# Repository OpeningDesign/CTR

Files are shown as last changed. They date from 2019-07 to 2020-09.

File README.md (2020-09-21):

<div align="right" >
<p align="right" >

</p>
</div>

## OpeningDesign
An (uberly) transparent & open source architectural studio.

---
#### In-the-Open

All of [OpeningDesign's](http://openingdesign.com/) projects are conducted out in the open.  That is, during the development of any one project, all team communication and content is hosted [publicly](https://github.com/OpeningDesign) (here on GitHub) and is <a href="#license">open source</a>.

Our [about page](http://openingdesign.com/about/) provides a more nuanced description of this open approach.

---
#### License
Per usual, unless otherwise noted, all content associated with [OpeningDesign](http://openingdesign.com) projects is licensed under an open source, 'copyleft' license: 
[Attribution-ShareAlike 4.0 International (CC BY-SA 4.0)](https://creativecommons.org/licenses/by-sa/4.0/).  Attribution to be given to the entire team associated with the project.


---

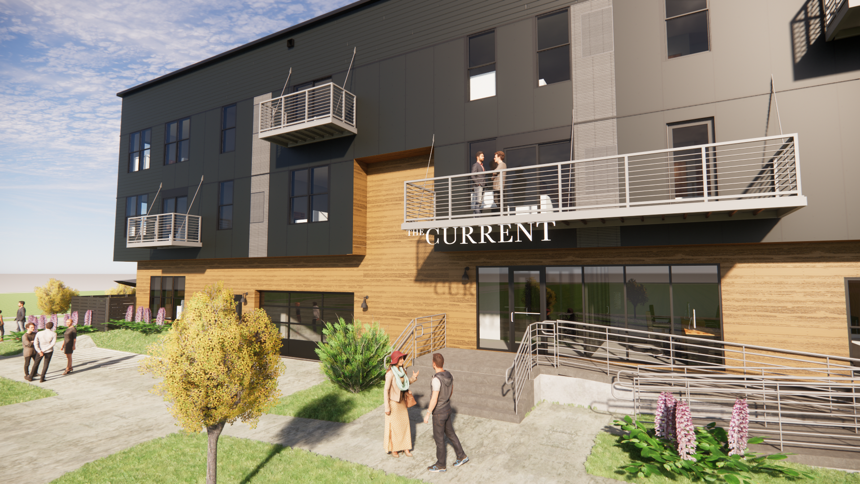
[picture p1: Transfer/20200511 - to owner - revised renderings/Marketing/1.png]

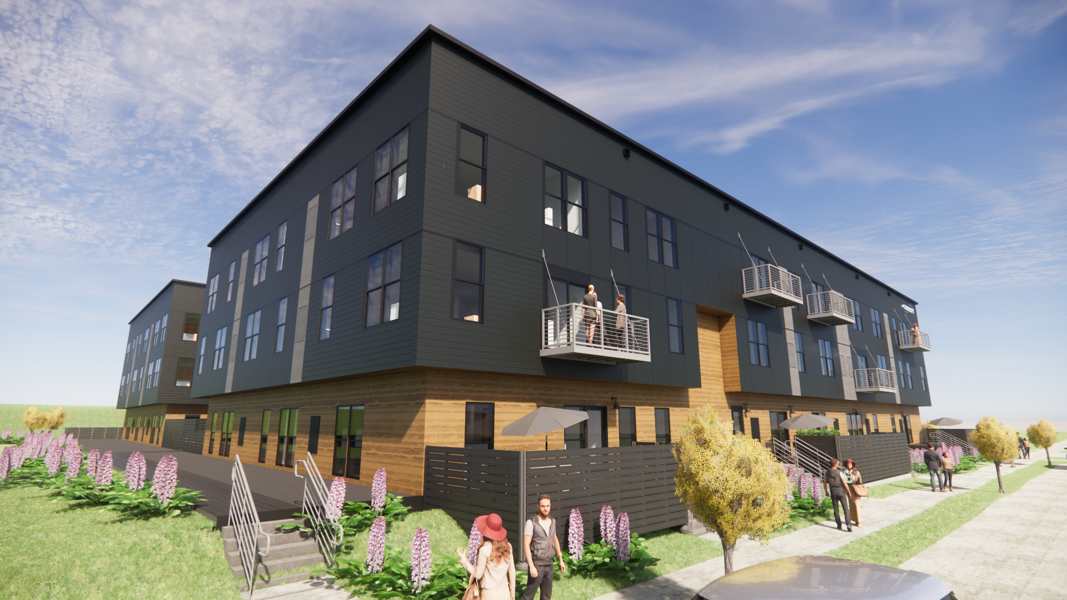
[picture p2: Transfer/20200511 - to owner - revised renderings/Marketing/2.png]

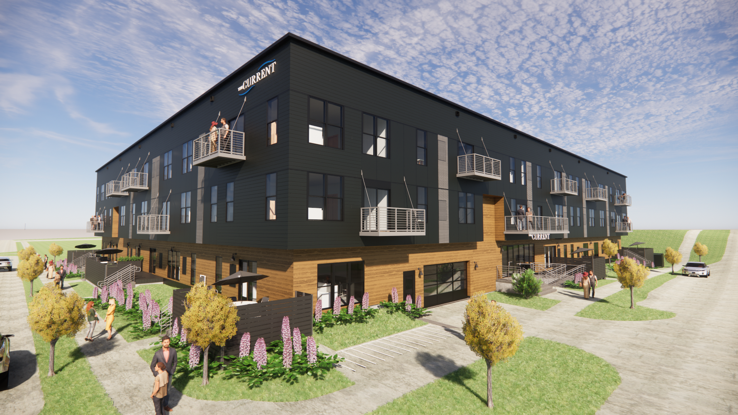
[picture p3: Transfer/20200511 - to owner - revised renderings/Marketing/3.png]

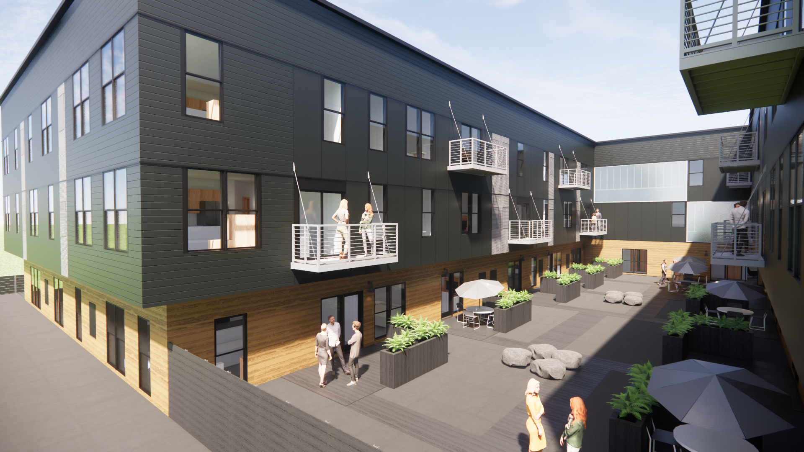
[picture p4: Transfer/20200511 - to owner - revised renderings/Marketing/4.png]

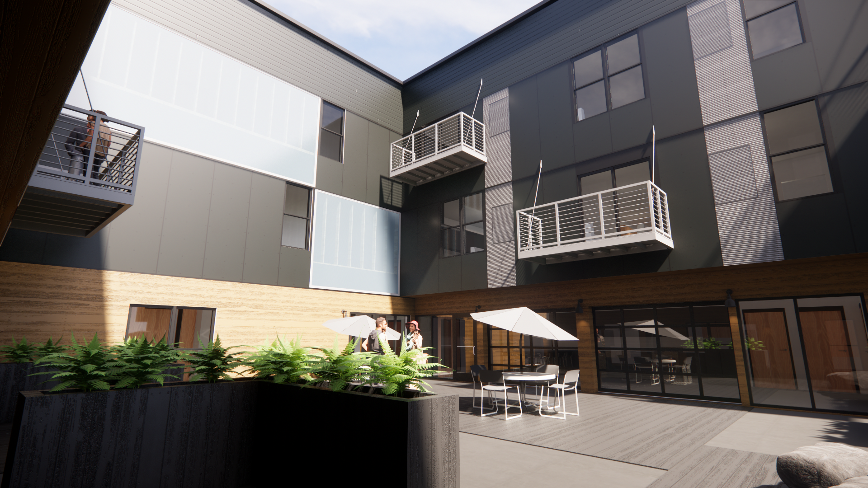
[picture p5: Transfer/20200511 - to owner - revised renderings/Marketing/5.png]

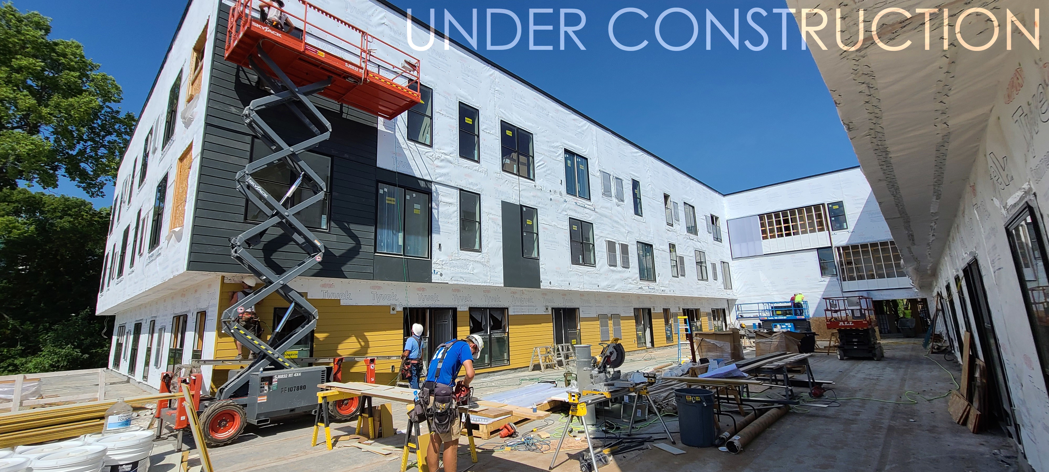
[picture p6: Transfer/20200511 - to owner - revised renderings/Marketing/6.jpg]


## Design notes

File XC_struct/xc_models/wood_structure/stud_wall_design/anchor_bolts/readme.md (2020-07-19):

Anchor bolts for anchoring wood framing walls to concrete.

See [issue](https://github.com/OpeningDesign/CTR/issues/90)

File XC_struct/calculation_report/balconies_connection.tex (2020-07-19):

\subsection{Loads on the connection}
The ties of the balconies are attached to the wood structure by means of the
connection represented in figure \ref{fg_balconies_connection}.

According to our calculations the maximum load to be resisted by this connection is:

\begin{equation}
  F= 4.83\ kN
\end{equation}

\noindent the angle with respect to the vertical of this force is 23.42 degrees.

\subsection{Loads on fasteners}
To calculate the loads on the connection fasteners we have used a the finite element model shown in figure \ref{fg_balconies_connection_mesh}.

\subsection{Fastener strength}
The strength of the 3/8 lag screws are as follows:

\begin{itemize}
\item Screw design withdrawal: $W_d= 4.6\ kN$.
\item Screw design lateral strength: $Z_d= 0.89\ kN$.
\end{itemize}

\subsection{Checking of fastener capacities}
The capacities of the fasteners are as follows:

\begin{center}
  \begin{tabular}{|c|c|c|c|}
    \hline
    \textbf{Screw} & $\mathbf{Z}$ & $\mathbf{R}$ & CF    \\
    \textbf{ID} & \textbf{(kN)}& \textbf{(kN)} & - \\
      \hline
466 & 0.13 & 0.98 & 0.14\\
638 & 0.96 & 1.03 & 0.93\\
129 & 0.15 & 1.19 & 0.12\\
59 & 0.76 & 1.38 & 0.55\\
94 & 0.12 & 4.25 & 0.03\\
50 & 0.64 & 2.66 & 0.24\\
26 & 0.13 & 1.40 & 0.10\\
393 & 0.70 & 1.21 & 0.58\\
218 & 0.13 & 0.98 & 0.14\\
242 & 0.96 & 1.03 & 0.93\\
543 & 0.15 & 1.19 & 0.12\\
522 & 0.76 & 1.38 & 0.55\\
539 & 0.12 & 4.25 & 0.03\\
490 & 0.64 & 2.66 & 0.24\\
322 & 0.13 & 1.40 & 0.10\\
297 & 0.70 & 1.21 & 0.58\\
\hline
  \end{tabular}
  \end{center}

\noindent where
\begin{description}
\item{Screw ID.} Screw identifier.
\item{$Z$:} Screw strength.
\item{$R$:} Design load on screw.
\item{$CF= Z/R$:} Capacity factor
  \end{description}

We can see that the maximum capacity factor is $0.93<1$ so the fasteners are strong enough.

\begin{figure}
  \begin{center}
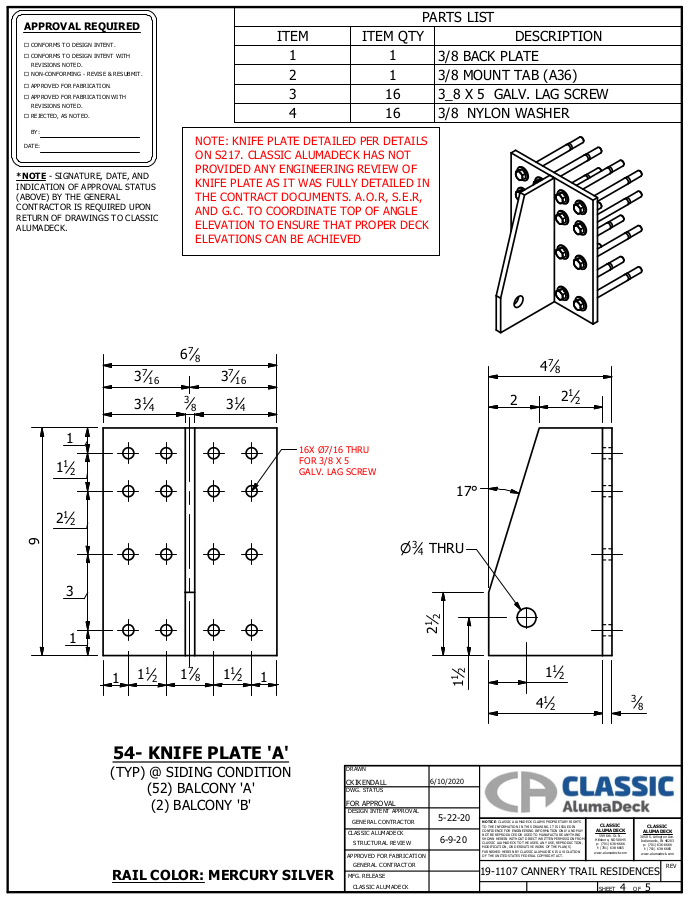
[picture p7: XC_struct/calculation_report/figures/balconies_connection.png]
    
  \end{center}
  \caption{Balconies connection.} \label{fg_balconies_connection}
\end{figure}

\begin{figure}
  \begin{center}
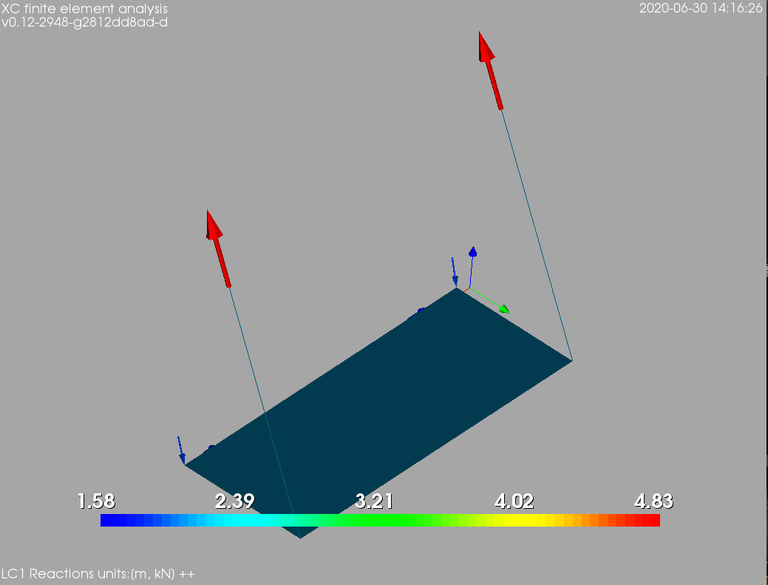
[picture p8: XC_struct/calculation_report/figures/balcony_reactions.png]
    
  \end{center}
  \caption{Balconies. Maximum load on connections.}
\end{figure}

\begin{figure}
  \begin{center}
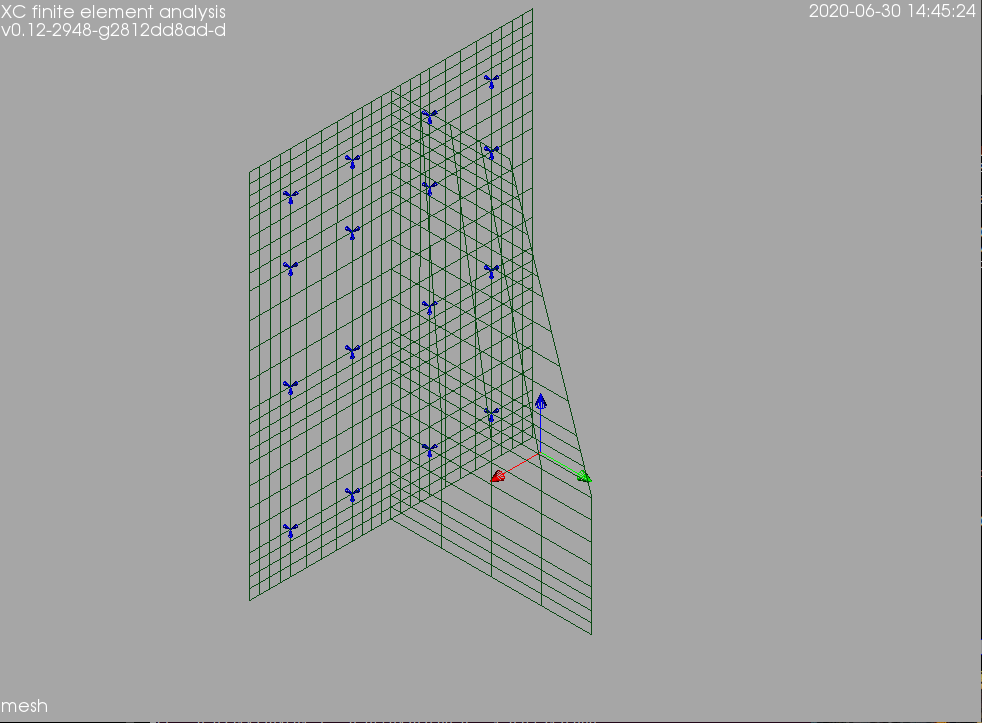
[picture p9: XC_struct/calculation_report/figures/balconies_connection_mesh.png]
    
  \end{center}
  \caption{Balconies connection. Finite element model.}\label{fg_balconies_connection_mesh}
\end{figure}

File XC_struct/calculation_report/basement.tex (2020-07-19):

\input{model.tex}
\subsection{Footings}
\input{footings.tex}
\subsection{Basement walls}
\input{basement_walls.tex}
%\subsection{Ramp}
%\input{ramp.tex}
\subsection{Ramp walls and steel structure bearing hollowcore 2nd floor}
\input{ramp_wall/data.tex}
\subsubsection{Material and RC-sections properties}
\input{ramp_wall/results.tex}

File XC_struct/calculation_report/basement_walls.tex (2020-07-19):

\subsubsection{Introduction}

The design is based in the following assumptions:

\begin{itemize}
\item Design wall with pinned base and pinned top.
\item Neglect corner regions (wall spans one-way only).
\item Top slab is in place and has achieved full strength prior to back-filling.
\item Vehicular traffic around the building is represented by a uniform load of $250\ psf$ ($11.97\ kN/m^2$).
\item The vertical response of the soil calculated using a Winkler model with a sub-grade reaction module of set of 200 pounds per cubic inch ($54.29 \times 10^6\ N/m^3$).
\item Water table deep below structure.
\end{itemize}

\subsubsection{Load determination}

\subparagraph{Self weight.}
The self weight of the reinforced concrete is calculated from its density: $2500\ kg/m^3$.

\subparagraph{Axial loads from building.}
The loads transferred by the top slab to the wall are as follows:

\begin{center}
  \begin{tabular}{|l|l|r|r|}
\hline
\textbf{Building} & \textbf{Load} & \textbf{Phase 1} & \textbf{Phase 2}\\
\textbf{side} &  & (kN/m) & (kN/m)\\
\hline
North & SnowL & 10.06 & 10.06\\
North & LiveL & 21.67 & 21.67\\
North & Wind\_NS & -15.12 & -15.12\\
North & Wind\_WE & -1.33 & -1.33\\
North & DeadL & 31.54 & 31.54\\
\hline
South & SnowL & 8.04 & 16.08\\
South & LiveL & 14.22 & 28.44\\
South & Wind\_NS & 4.97 & 9.95\\
South & Wind\_WE & -0.23 & -0.46\\
South & DeadL & 20.58 & 41.15\\
\hline
East & SnowL & 11.96 & 11.96\\
East & LiveL & 23.75 & 23.75\\
East & Wind\_NS & -0.07 & -0.07\\
East & Wind\_WE & 12.97 & 12.97\\
East & DeadL & 30.87 & 30.87\\
\hline
West & SnowL & 15.02 & 15.02\\
West & LiveL & 27.15 & 27.15\\
West & Wind\_NS & -0.20 & -0.20\\
West & Wind\_WE & -13.20 & -13.20\\
West & DeadL & 29.81 & 29.81\\
\hline
\end{tabular}
\end{center}

\subsubsection{Load combinations} \label{sc_load_combinations}

\begin{center}
  \begin{footnotesize}
  \begin{tabular}{|l|c|l|}
\hline
\multicolumn{3}{|c|}{\textbf{Serviceability limit states}}\\
\hline
Equation 16-8 & EQ1608 & 1.0*selfWeight+1.0*deadLoad\\
Equation 16-9 & EQ1609A & 1.0*selfWeight+1.0*deadLoad+1.0*trafficLoad\\
Equation 16-9 & EQ1609B & 1.0*selfWeight+1.0*deadLoad+1.0*liveLoad\\
Equation 16-10 & EQ1610 & 1.0*selfWeight+1.0*deadLoad+1.0*snowLoad\\
Equation 16-11 & EQ1611A & 1.0*selfWeight+1.0*deadLoad+0.75*trafficLoad+0.75*snowLoad\\
Equation 16-11 & EQ1611B & 1.0*selfWeight+1.0*deadLoad+0.75*liveLoad+0.75*snowLoad\\
Equation 16-12 & EQ1612 & 1.0*selfWeight+1.0*deadLoad+0.6*windLoad\\
Equation 16-13 & EQ1613A & 1.0*selfWeight+1.0*deadLoad+0.45*windLoad+0.75*trafficLoad+0.75*snowLoad\\
Equation 16-13 & EQ1613B & 1.0*selfWeight+1.0*deadLoad+0.45*windLoad+0.75*liveLoad+0.75*snowLoad\\
Equation 16-14 & \multicolumn{2}{l|}{doesn't apply}\\
Equation 16-15 & EQ1615 & 0.6*selfWeight+0.6*deadLoad+0.6*windLoad\\
Equation 16-16 & \multicolumn{2}{l|}{doesn't apply}\\
\hline
  \end{tabular}
  \end{footnotesize}
  \end{center}

\begin{center}
  \begin{footnotesize}
  \begin{tabular}{|l|c|l|}
\hline
\multicolumn{3}{|c|}{\textbf{Ultimate limit states.}}\\
\hline
Equation 16-1 & EQ1601 & 1.4*selfWeight+1.4*deadLoad\\
Equation 16-2 & EQ1602A & 1.2*selfWeight+1.2*deadLoad+1.6*trafficLoad+0.5*snowLoad\\
Equation 16-2 & EQ1602B & 1.2*selfWeight+1.2*deadLoad+1.6*liveLoad+0.5*snowLoad\\
Equation 16-3 & EQ1603A & 1.2*selfWeight+1.2*deadLoad+1.6*snowLoad+0.5*trafficLoad\\
Equation 16-3 & EQ1603B & 1.2*selfWeight+1.2*deadLoad+1.6*snowLoad+0.5*liveLoad\\
Equation 16-3 & EQ1603C & 1.2*selfWeight+1.2*deadLoad+1.6*snowLoad+0.5*windLoad\\
Equation 16-4 & EQ1604A & 1.2*selfWeight+1.2*deadLoad+1.0*windLoad+0.5*trafficLoad+0.5*snowLoad\\
Equation 16-4 & EQ1604B & 1.2*selfWeight+1.2*deadLoad+1.0*windLoad+0.5*liveLoad+0.5*snowLoad\\
Equation 16-5 & EQ1605A & 1.2*selfWeight+1.2*deadLoad+0.5*trafficLoad+0.7*snowLoad\\
Equation 16-5 & EQ1605B & 1.2*selfWeight+1.2*deadLoad+0.5*liveLoad+0.7*snowLoad\\
Equation 16-6 & \multicolumn{2}{l|}{doesn't apply}\\
Equation 16-7 & \multicolumn{2}{l|}{doesn't apply}\\
\hline
  \end{tabular}
  \end{footnotesize}
  \end{center}

\subparagraph{Earth pressure.}
The soil pressure over the wall has been calculated using the lateral pressure at rest with a coefficient $K_0= 0.5$.

\subsubsection{Stem dimensions and reinforcement}
The thickness and the reinforcement for the walls are indicated in the table \ref{tb_concrete_wall_reinforcing_schedule}.

\begin{table}
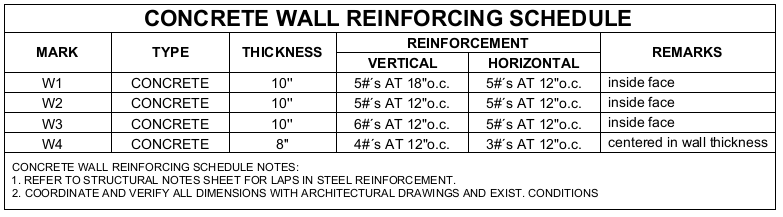
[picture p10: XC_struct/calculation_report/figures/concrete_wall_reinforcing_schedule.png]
    
    \caption{Concrete walls reinforcing schedule}\label{tb_concrete_wall_reinforcing_schedule}
\end{table}

\subparagraph{Wall types.}
For analysis purposes we have considered the following wall types:

\begin{center}
  \begin{tabular}{|l|c|}
    \hline
    \textbf{Wall} & \textbf{Stem} \\
    & \textbf{height (m)} \\
    \hline
T1 & 3.15\\
T2 & 2.74\\
T3 & 3.53\\
T4 & 3.12\\
T5 & 2.51\\
T6 & 3.43\\
    \hline
  \end{tabular}
\end{center}

\subparagraph{Internal forces.}
The envelope of internal forces envelope for each of the walls are given in tables \ref{tb_def_T1} to \ref{tb_def_T6}.

\begin{table}
\begin{center}
\begin{tabular}{|l|}
\hline
\multicolumn{1}{|c|}{\textsc{T1}}\\
\hline
\begin{tabular}{c|l}
\begin{minipage}{85mm}
\vspace{2mm}
\begin{center}

\end{center}
\vspace{1pt}
\end{minipage} & 
\begin{tabular}{l}
\textsc{Wall geometry}\\
Stem top thickness: \\
$b_{top}= 0.25\ m$\\
Stem height: \\
$h_{stem}= 3.15\ m$\\
Stem bottom thickness: \\
$b_{bottom}= 0.25\ m$\\
Footing thickness: \\
$b_{footing}= 0.36\ m$\\
\end{tabular} \\
\end{tabular} \\
\hline
\begin{tabular}{llll}
\multicolumn{3}{c}{\textsc{Materials}}\\
  Concrete: C4000 &   Steel: A615G60 &   Concrete cover: 55 mm\\
\end{tabular} \\
\hline
\end{tabular}
\caption{Wall materials and dimensions T1} \label{tb_def_T1}
\end{center}
\end{table}

\begin{table}
\begin{center}
\begin{tabular}{|l|}
\hline
\multicolumn{1}{|c|}{\textsc{T2}}\\
\hline
\begin{tabular}{c|l}
\begin{minipage}{85mm}
\vspace{2mm}
\begin{center}

\end{center}
\vspace{1pt}
\end{minipage} & 
\begin{tabular}{l}
\textsc{Wall geometry}\\
Stem top thickness: \\
$b_{top}= 0.25\ m$\\
Stem height: \\
$h_{stem}= 2.74\ m$\\
Stem bottom thickness: \\
$b_{bottom}= 0.25\ m$\\
Footing thickness: \\
$b_{footing}= 0.36\ m$\\
\end{tabular} \\
\end{tabular} \\
\hline
\begin{tabular}{llll}
\multicolumn{3}{c}{\textsc{Materials}}\\
  Concrete: C4000 &   Steel: A615G60 &   Concrete cover: 55 mm\\
\end{tabular} \\
\hline
\end{tabular}
\caption{Wall materials and dimensions T2} \label{tb_def_T2}
\end{center}
\end{table}

\begin{table}
\begin{center}
\begin{tabular}{|l|}
\hline
\multicolumn{1}{|c|}{\textsc{T3}}\\
\hline
\begin{tabular}{c|l}
\begin{minipage}{85mm}
\vspace{2mm}
\begin{center}

\end{center}
\vspace{1pt}
\end{minipage} & 
\begin{tabular}{l}
\textsc{Wall geometry}\\
Stem top thickness: \\
$b_{top}= 0.25\ m$\\
Stem height: \\
$h_{stem}= 3.53\ m$\\
Stem bottom thickness: \\
$b_{bottom}= 0.25\ m$\\
Footing thickness: \\
$b_{footing}= 0.36\ m$\\
\end{tabular} \\
\end{tabular} \\
\hline
\begin{tabular}{llll}
\multicolumn{3}{c}{\textsc{Materials}}\\
  Concrete: C4000 &   Steel: A615G60 &   Concrete cover: 55 mm\\
\end{tabular} \\
\hline
\end{tabular}
\caption{Wall materials and dimensions T3} \label{tb_def_T3}
\end{center}
\end{table}

\begin{table}
\begin{center}
\begin{tabular}{|l|}
\hline
\multicolumn{1}{|c|}{\textsc{T4}}\\
\hline
\begin{tabular}{c|l}
\begin{minipage}{85mm}
\vspace{2mm}
\begin{center}

\end{center}
\vspace{1pt}
\end{minipage} & 
\begin{tabular}{l}
\textsc{Wall geometry}\\
Stem top thickness: \\
$b_{top}= 0.25\ m$\\
Stem height: \\
$h_{stem}= 3.12\ m$\\
Stem bottom thickness: \\
$b_{bottom}= 0.25\ m$\\
Footing thickness: \\
$b_{footing}= 0.36\ m$\\
\end{tabular} \\
\end{tabular} \\
\hline
\begin{tabular}{llll}
\multicolumn{3}{c}{\textsc{Materials}}\\
  Concrete: C4000 &   Steel: A615G60 &   Concrete cover: 55 mm\\
\end{tabular} \\
\hline
\end{tabular}
\caption{Wall materials and dimensions T4} \label{tb_def_T4}
\end{center}
\end{table}

\begin{table}
\begin{center}
\begin{tabular}{|l|}
\hline
\multicolumn{1}{|c|}{\textsc{T5}}\\
\hline
\begin{tabular}{c|l}
\begin{minipage}{85mm}
\vspace{2mm}
\begin{center}

\end{center}
\vspace{1pt}
\end{minipage} & 
\begin{tabular}{l}
\textsc{Wall geometry}\\
Stem top thickness: \\
$b_{top}= 0.25\ m$\\
Stem height: \\
$h_{stem}= 2.51\ m$\\
Stem bottom thickness: \\
$b_{bottom}= 0.25\ m$\\
Footing thickness: \\
$b_{footing}= 0.36\ m$\\
\end{tabular} \\
\end{tabular} \\
\hline
\begin{tabular}{llll}
\multicolumn{3}{c}{\textsc{Materials}}\\
  Concrete: C4000 &   Steel: A615G60 &   Concrete cover: 55 mm\\
\end{tabular} \\
\hline
\end{tabular}
\caption{Wall materials and dimensions T5} \label{tb_def_T5}
\end{center}
\end{table}

\begin{table}
\begin{center}
\begin{tabular}{|l|}
\hline
\multicolumn{1}{|c|}{\textsc{T6}}\\
\hline
\begin{tabular}{c|l}
\begin{minipage}{85mm}
\vspace{2mm}
\begin{center}

\end{center}
\vspace{1pt}
\end{minipage} & 
\begin{tabular}{l}
\textsc{Wall geometry}\\
Stem top thickness: \\
$b_{top}= 0.25\ m$\\
Stem height: \\
$h_{stem}= 3.43\ m$\\
Stem bottom thickness: \\
$b_{bottom}= 0.25\ m$\\
Footing thickness: \\
$b_{footing}= 0.36\ m$\\
\end{tabular} \\
\end{tabular} \\
\hline
\begin{tabular}{llll}
\multicolumn{3}{c}{\textsc{Materials}}\\
  Concrete: C4000 &   Steel: A615G60 &   Concrete cover: 55 mm\\
\end{tabular} \\
\hline
\end{tabular}
\caption{Wall materials and dimensions T6} \label{tb_def_T6}
\end{center}
\end{table}

\subparagraph{Reinforcement checks.}

\tablefirsthead{\hline
\multicolumn{1}{|c|}{\textsc{Wall vertical reinforcements}}\\\hline
}
\tablehead{\hline
\multicolumn{1}{|c|}{\textsc{wall vertical reinforcements (cont.)}}\\\hline
}
\tabletail{\hline \multicolumn{1}{|r|}{../..}\\\hline}
\tablelasttail{\hline}
\begin{center}
\begin{supertabular}{|l|}
\hline
\textbf{T1 wall. Inside stem reinforcement:}\\
  RC section dimensions; b= 1.00 m, h= 0.25 m\\
  diam: 16 mm, spacing: 300 mm  reinf. development L=0.34 m (22 diameters).\\
  area: As=   6.67 cm2/m areaMin:   4.56 cm2/m  F(As)= 1.46 OK!\\
  Bending check: Md=  40.09 kN m, MR=  41.36kN m  F(M)= 1.03 OK!\\
  Shear check: Vd=   7.61 kN,  VR= 199.37 kN  F(V)= 26.21 OK!\\
  %% Stress check: M=  40.09 kN m, $\sigma_s$= 263.03 MPa\\
  %%   $\sigma_{lim}$= 300.00 MPa  F($\sigma_s$)= 1.14 OK!\\
\hline
\textbf{T2 wall. Inside stem reinforcement:}\\
  RC section dimensions; b= 1.00 m, h= 0.25 m\\
  diam: 16 mm, spacing: 400 mm  reinf. development L=0.34 m (22 diameters).\\
  area: As=   5.00 cm2/m areaMin:   4.56 cm2/m  F(As)= 1.10 OK!\\
  Bending check: Md=  29.02 kN m, MR=  31.02kN m  F(M)= 1.07 OK!\\
  Shear check: Vd=   6.84 kN,  VR= 199.37 kN  F(V)= 29.15 OK!\\
  %% Stress check: M=  29.02 kN m, $\sigma_s$= 253.88 MPa\\
  %%   $\sigma_{lim}$= 300.00 MPa  F($\sigma_s$)= 1.18 OK!\\
\hline
\textbf{T3 wall. Inside stem reinforcement:}\\
  RC section dimensions; b= 1.00 m, h= 0.25 m\\
  diam: 19 mm, spacing: 300 mm  reinf. development L=0.61 m (32 diameters).\\
  area: As=   9.47 cm2/m areaMin:   4.56 cm2/m  F(As)= 2.08 OK!\\
  Bending check: Md=  51.88 kN m, MR=  58.26kN m  F(M)= 1.12 OK!\\
  Shear check: Vd=   7.98 kN,  VR= 199.37 kN  F(V)= 24.98 OK!\\
  %% Stress check: M=  51.88 kN m, $\sigma_s$= 239.75 MPa\\
  %%   $\sigma_{lim}$= 300.00 MPa  F($\sigma_s$)= 1.25 $\sim$ OK!\\
\hline
\textbf{T4 wall. Inside stem reinforcement:}\\
  RC section dimensions; b= 1.00 m, h= 0.25 m\\
  diam: 16 mm, spacing: 300 mm  reinf. development L=0.34 m (22 diameters).\\
  area: As=   6.67 cm2/m areaMin:   4.56 cm2/m  F(As)= 1.46 OK!\\
  Bending check: Md=  39.19 kN m, MR=  41.36kN m  F(M)= 1.06 OK!\\
  Shear check: Vd=   7.46 kN,  VR= 199.37 kN  F(V)= 26.73 OK!\\
  %% Stress check: M=  39.19 kN m, $\sigma_s$= 257.14 MPa\\
  %%   $\sigma_{lim}$= 300.00 MPa  F($\sigma_s$)= 1.17 OK!\\
\hline
\textbf{T5 wall. Inside stem reinforcement:}\\
  RC section dimensions; b= 1.00 m, h= 0.25 m\\
  diam: 16 mm, spacing: 400 mm  reinf. development L=0.34 m (22 diameters).\\
  area: As=   5.00 cm2/m areaMin:   4.56 cm2/m  F(As)= 1.10 OK!\\
  Bending check: Md=  23.62 kN m, MR=  31.02kN m  F(M)= 1.31 OK!\\
  Shear check: Vd=   6.42 kN,  VR= 199.37 kN  F(V)= 31.05 OK!\\
  %% Stress check: M=  23.62 kN m, $\sigma_s$= 206.69 MPa\\
  %%   $\sigma_{lim}$= 300.00 MPa  F($\sigma_s$)= 1.45 OK!\\
\hline
\textbf{T6 wall. Inside stem reinforcement:}\\
  RC section dimensions; b= 1.00 m, h= 0.25 m\\
  diam: 19 mm, spacing: 300 mm  reinf. development L=0.61 m (32 diameters).\\
  area: As=   9.47 cm2/m areaMin:   4.56 cm2/m  F(As)= 2.08 OK!\\
  Bending check: Md=  49.02 kN m, MR=  58.26kN m  F(M)= 1.19 OK!\\
  Shear check: Vd=   8.13 kN,  VR= 199.37 kN  F(V)= 24.54 OK!\\
  %% Stress check: M=  49.02 kN m, $\sigma_s$= 226.52 MPa\\
  %%   $\sigma_{lim}$= 300.00 MPa  F($\sigma_s$)= 1.32 OK!\\
\end{supertabular}
\end{center}

\tablefirsthead{\hline
\multicolumn{1}{|c|}{\textsc{Shear check}}\\\hline
}
\tablehead{\hline
\multicolumn{1}{|c|}{\textsc{shear check (cont.)}}\\\hline
}
\tabletail{\hline \multicolumn{1}{|r|}{../..}\\\hline}
\tablelasttail{\hline}
\begin{center}
\begin{supertabular}{|l|}
\textbf{T1 wall. Shear check:}\\
  Shear check: Vd=  42.99 kN,  VR= 199.37 kN  F(V)= 4.64 OK!\\
\hline
\textbf{T2 wall. Shear check:}\\
  Shear check: Vd=  31.78 kN,  VR= 199.37 kN  F(V)= 6.27 OK!\\
\hline
\textbf{T3 wall. Shear check:}\\
  Shear check: Vd=  55.00 kN,  VR= 199.37 kN  F(V)= 3.63 OK!\\
\hline
\textbf{T4 wall. Shear check:}\\
  Shear check: Vd=  42.35 kN,  VR= 199.37 kN  F(V)= 4.71 OK!\\
\hline
\textbf{T5 wall. Shear check:}\\
  Shear check: Vd=  26.03 kN,  VR= 199.37 kN  F(V)= 7.66 OK!\\
\hline
\textbf{T6 wall. Shear check:}\\
  Shear check: Vd=  51.43 kN,  VR= 199.37 kN  F(V)= 3.88 OK!\\
\end{supertabular}
\end{center}

\paragraph{Wall foundations}
The results obtained for the verifications of the footing stability and the soil-bearing capacity. According to the geotechnical report the allowable soil bearing pressure is 3000 psf ($143.64\ kN/m^2$).
\begin{center}
\begin{tabular}{|l|c|c|c|}
\hline
\multicolumn{4}{|c|}{\textsc{wall foundation: T1}}\\
\hline
Verification:  & $F_{disp}$ & $F_{req}$ & Combination\\
\hline
Overturning:  & $\gg 1$ & 1.00 & EQ1609A\\
Sliding:  & 1.23 & 1.00 & EQ1609A\\
Adm. pressure:  & 1.09 & 1.00 & EQ1613B\\
\hline
\multicolumn{4}{|c|}{\textsc{wall foundation: T2}}\\
\hline
Verification:  & $F_{disp}$ & $F_{req}$ & Combination\\
\hline
Overturning:  & $\gg 1$ & 1.00 & EQ1613B\\
Sliding:  & 1.46 & 1.00 & EQ1609A\\
Adm. pressure:  & 1.13 & 1.00 & EQ1613B\\
\hline
\multicolumn{4}{|c|}{\textsc{wall foundattion: T3}}\\
\hline
Verification:  & $F_{disp}$ & $F_{req}$ & Combination\\
\hline
Overturning:  & $\gg 1$ & 1.00 & EQ1609A\\
Sliding:  & 1.13 & 1.00 & EQ1609A\\
Adm. pressure:  & 1.12 & 1.00 & EQ1613B\\
\hline
\multicolumn{4}{|c|}{\textsc{wall foundation: T4}}\\
\hline
Verification:  & $F_{disp}$ & $F_{req}$ & Combination\\
\hline
Overturning:  & $\gg 1$ & 1.00 & EQ1613B\\
Sliding:  & 1.45 & 1.00 & EQ1609A\\
Adm. pressure:  & 1.08 & 1.00 & EQ1613B\\
\hline
\multicolumn{4}{|c|}{\textsc{wall foundation: T5 }}\\
\hline
Verification:  & $F_{disp}$ & $F_{req}$ & Combination\\
\hline
Overturning:  & $\gg 1$ & 1.00 & EQ1613B\\
Sliding:  & 1.69 & 1.00 & EQ1609A\\
Adm. pressure:  & 1.22 & 1.00 & EQ1613B\\
\hline
\multicolumn{4}{|c|}{\textsc{wall foundation: T6}}\\
\hline
Verification:  & $F_{disp}$ & $F_{req}$ & Combination\\
\hline
Overturning:  & $\gg 1$ & 1.00 & EQ1609A\\
Sliding:  & 1.10 & 1.00 & EQ1609A\\
Adm. pressure:  & 1.03 & 1.00 & EQ1613B\\
\hline
\multicolumn{4}{|l|}{$F_{avail.}$: available security.}\\
\multicolumn{4}{|l|}{$F_{req}$: required security.}\\
\hline
\end{tabular}
\end{center}

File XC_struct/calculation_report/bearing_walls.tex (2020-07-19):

\subsection{Bearing walls}

\begin{figure}
  \begin{center}
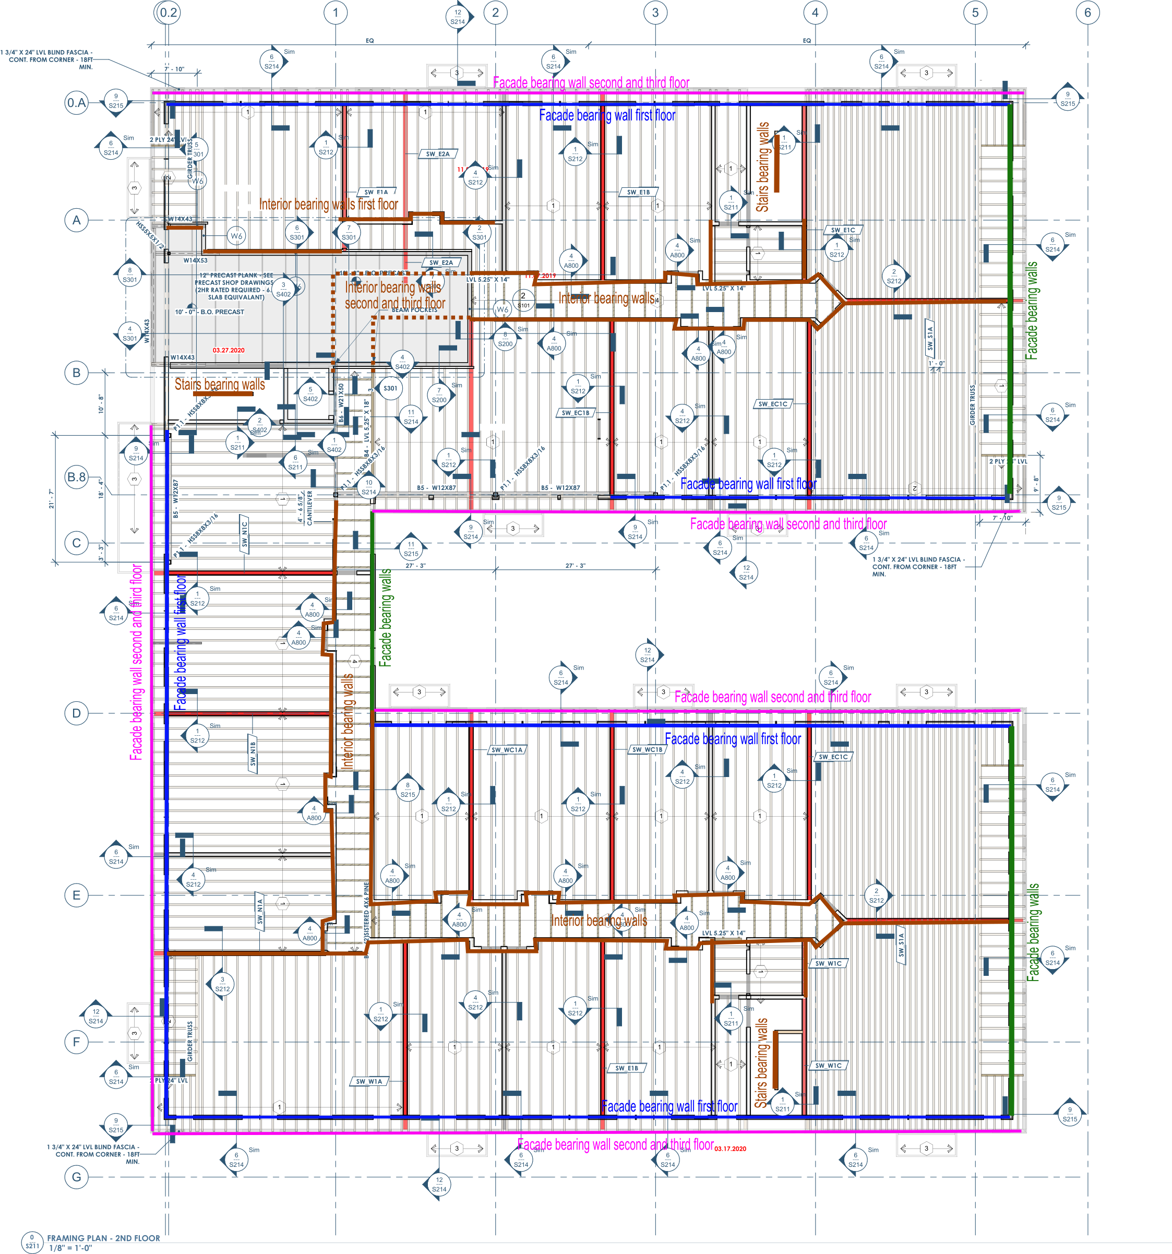
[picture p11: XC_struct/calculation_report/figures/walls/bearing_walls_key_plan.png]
  
  \end{center}
  \caption{Bearing walls key plan. Roof}\label{fg_bearing_walls_key_plan}
\end{figure}

\subsubsection{Facade bearing walls at first floor}

\paragraph{Loads.}

\begin{itemize}
\item Vertical load: 43.34 kN/m
\item Vertical load on each stud: 21.14 kN
\item Wind load on stud height: 0.42 kN/m
\end{itemize}

\paragraph{Internal forces.}

\noindent Internal forces:

\begin{align}
  N_{max}&= 21.14\ kN \\
  M_{max}&= 0.36\ kN \cdot m
\end{align}

\paragraph{Bending and axial compression check.}

\subparagraph{Mechanical properties}

\begin{itemize}
\item Species: Hem-fir stud
\item Spacing: $0.49\ m$
\item Stud height: 2.64 m
\item Repetitive member factor: $C_r= 1.15$
\item Size factor: $C_F= 1.3$
\item $E_{min}= 3.03\ GPa$
\item $F'_c= 6.09\ MPa$.
\item $F'_b= 6.97\ MPa$.
\item Sections dimensions: (2x8''), effective (1.5x7.5'')= $38.1 \times 190.5\ mm$.
\item Unbraced length x axis: 2.64 m
\item Unbraced length y axis: 0.3 m
\item Stud stability factor: $C_P= 0.85$
\end{itemize}

\begin{equation}
  N'_s= 44.21\ kN
\end{equation}

\noindent Capacity factor according to section 3.9.2 of NDS-2018 (equations 3.9.3 and 3.9.4):

\begin{equation}
  CF= 0.52 < 1 \implies OK
\end{equation}

\subsubsection{Facade bearing walls at second floor}

\paragraph{Loads.}

\begin{itemize}
\item Vertical load: 30.52 kN/m
\item Vertical load on each stud: 14.88 kN
\item Wind load on stud height: 0.42 kN/m
\end{itemize}

\paragraph{Internal forces.}

\noindent Internal forces:

\begin{align}
  N_{max}&= 14.88\ kN \\
  M_{max}&= 0.36\ kN \cdot m
\end{align}

\paragraph{Bending and axial compression check.}

\subparagraph{Mechanical properties}

\begin{itemize}
\item Species: Hem-fir stud
\item Spacing: $0.49\ m$
\item Stud height: 2.64 m
\item Repetitive member factor: $C_r= 1.15$
\item Size factor: $C_F= 1.3$
\item $E_{min}= 3.03\ GPa$
\item $F'_c= 6.09\ MPa$.
\item $F'_b= 6.95\ MPa$.
\item Sections dimensions: (2x8''), effective (1.5x7.5'')= $38.1 \times 190.5\ mm$.
\item Unbraced length x axis: 2.64 m
\item Unbraced length y axis: 0.3 m
\item Stud stability factor: $C_P= 0.85$
\end{itemize}

\begin{equation}
  N'_s= 44.21\ kN
\end{equation}

\noindent Capacity factor according to section 3.9.2 of NDS-2018 (equations 3.9.3 and 3.9.4):

\begin{equation}
  CF= 0.38 < 1 \implies OK
\end{equation}

\subsubsection{Facade bearing walls at third floor}

\paragraph{Loads.}

\begin{itemize}
\item Vertical load: 16.01 kN/m
\item Vertical load on each stud: 7.81 kN
\item Wind load on stud height: 0.42 kN/m
\end{itemize}

\paragraph{Internal forces.}

\noindent Internal forces:

\begin{align}
  N_{max}&= 7.81\ kN \\
  M_{max}&= 0.36\ kN \cdot m
\end{align}

\paragraph{Bending and axial compression check.}

\subparagraph{Mechanical properties}

\begin{itemize}
\item Species: Hem-fir stud
\item Spacing: $0.49\ m$
\item Stud height: 2.64 m
\item Repetitive member factor: $C_r= 1.15$
\item Size factor: $C_F= 1.3$
\item $E_{min}= 3.03\ GPa$
\item $F'_c= 6.09\ MPa$.
\item $F'_b= 6.96\ MPa$.
\item Sections dimensions: (2x8''), effective (1.5x7.5'')= $38.1 \times 190.5\ mm$.
\item Unbraced length x axis: 2.64 m
\item Unbraced length y axis: 0.3 m
\item Stud stability factor: $C_P= 0.85$
\end{itemize}

\begin{equation}
  N'_s= 44.21\ kN
\end{equation}

\noindent Capacity factor according to section 3.9.2 of NDS-2018 (equations 3.9.3 and 3.9.4):

\begin{equation}
  CF= 0.28 < 1 \implies OK
\end{equation}

\subsubsection{Top plates}

\paragraph{Loads}

\begin{itemize}
\item Load from trusses: 9.64 kN/truss.
\item Truss spacing: 0.61 m
\item Stud spacing: 0.49 m
\end{itemize}

\paragraph{Bending strength checking:}

\noindent Maximum induced moment:
\begin{align}
  M_{max}&= 0.42 kN \cdot m\\
  \sigma_{max}&= 9.21\ MPa
\end{align}

\noindent Bending strength:

\begin{equation}
  F'_b= 10.05\ MPa
\end{equation}

\noindent Structural bending check:

\begin{equation}
F'_b = 10.05 > 9.21 = \sigma_{max} \implies OK
\end{equation}

\paragraph{Perpendicular to grain strength checking:}

\noindent Maximum induced reaction:
\begin{align}
  R_{max}&= 9.38\ kN\\
  \sigma_{max,perp}&= 1.29\ MPa
\end{align}

\begin{equation}
F'_{c,perp} = 2.79 > 1.29 = \sigma_{max,perp} \implies OK
\end{equation}

\subsubsection{Interior bearing walls at first floor}

\paragraph{Loads.}

\begin{itemize}
\item Vertical load: 84.99 kN/m
\item Vertical load on each stud: 25.9 kN
\item Wind load on stud height: 0.0 kN/m
\end{itemize}

\paragraph{Internal forces.}

\noindent Internal forces:

\begin{align}
  N_{max}&= 25.9\ kN \\
  M_{max}&= 0.0\ kN \cdot m
\end{align}

\paragraph{Bending and axial compression check.}

\subparagraph{Mechanical properties}

\begin{itemize}
\item Species: Hem-fir stud
\item Spacing: $0.30\ m$
\item Stud height: 2.64 m
\item Repetitive member factor: $C_r= 1.15$
\item Size factor: $C_F= 1.3$
\item $E_{min}= 3.03\ GPa$
\item $F'_c= 4.89\ MPa$.
\item $F'_b= 6.96\ MPa$.
\item Sections dimensions: (2x6''), effective (1.5x5.5'')= 38.1 x 139.7  mm.
\item Unbraced length x axis: 2.64 m
\item Unbraced length y axis: 0.3 m
\item Stud stability factor: $C_P= 0.68$
\end{itemize}

\begin{equation}
  N'_s= 26.00\ kN
\end{equation}

\noindent Capacity factor according to section 3.9.2 of NDS-2018 (equations 3.9.3 and 3.9.4):

\begin{equation}
  CF= 0.99 < 1 \implies OK
\end{equation}

\subsubsection{Interior bearing walls at second floor}

\paragraph{Loads.}

\begin{itemize}
\item Vertical load: 59.93 kN/m
\item Vertical load on each stud: 18.26 kN
\item Wind load on stud height: 0.0 kN/m
\end{itemize}

\paragraph{Internal forces.}

\noindent Internal forces:

\begin{align}
  N_{max}&= 18.26\ kN \\
  M_{max}&= 0.0\ kN \cdot m
\end{align}

\paragraph{Bending and axial compression check.}

\subparagraph{Mechanical properties}

\begin{itemize}
\item Species: Hem-fir stud
\item Spacing: $0.30\ m$
\item Stud height: 2.64 m
\item Repetitive member factor: $C_r= 1.15$
\item Size factor: $C_F= 1.3$
\item $E_{min}= 3.03\ GPa$
\item $F'_c= 4.89\ MPa$.
\item $F'_b= 6.96\ MPa$.
\item Sections dimensions: (2x6''), effective (1.5x5.5'')= 38.1 x 139.7  mm.
\item Unbraced length x axis: 2.64 m
\item Unbraced length y axis: 0.3 m
\item Stud stability factor: $C_P= 0.68$
\end{itemize}

\begin{equation}
  N'_s= 26.00\ kN
\end{equation}

\noindent Capacity factor according to section 3.9.2 of NDS-2018 (equations 3.9.3 and 3.9.4):

\begin{equation}
  CF= 0.49 < 1 \implies OK
\end{equation}

\subsubsection{Interior bearing walls at third floor}

\paragraph{Loads.}

\begin{itemize}
\item Vertical load: 33.7 kN/m
\item Vertical load on each stud: 20.54 kN
\item Wind load on stud height: 0.0 kN/m
\end{itemize}

\paragraph{Internal forces.}

\noindent Internal forces:

\begin{align}
  N_{max}&= 20.54\ kN \\
  M_{max}&= 0.00\ kN \cdot m
\end{align}

\paragraph{Bending and axial compression check.}

\subparagraph{Mechanical properties}

\begin{itemize}
\item Species: Hem-fir stud
\item Spacing: $0.61\ m$
\item Stud height: 2.64 m
\item Repetitive member factor: $C_r= 1.15$
\item Size factor: $C_F= 1.3$
\item $E_{min}= 3.03\ GPa$
\item $F'_c= 4.89\ MPa$.
\item $F'_b= 6.96\ MPa$.
\item Sections dimensions: (2x6''), effective (1.5x5.5'')= 38.1 x 139.7  mm.
\item Unbraced length x axis: 2.64 m
\item Unbraced length y axis: 0.3 m
\item Stud stability factor: $C_P= 0.68$
\end{itemize}

\begin{equation}
  N'_s= 26.00\ kN
\end{equation}

\noindent Capacity factor according to section 3.9.2 of NDS-2018 (equations 3.9.3 and 3.9.4):

\begin{equation}
  CF= 0.62 < 1 \implies OK
\end{equation}

\subsubsection{Top plates}

\paragraph{Loads}

\begin{itemize}
\item Load from trusses: 11.81 kN/truss.
\item Truss spacing: 0.61 m
\item Stud spacing: 0.49 m
\end{itemize}

\paragraph{Bending strength checking:}

\noindent Maximum induced moment:
\begin{align}
  M_{max}&= 0.24 kN \cdot m\\
  \sigma_{max}&= 7.15\ MPa
\end{align}

\noindent Bending strength:

\begin{equation}
  F'_b= 10.05\ MPa
\end{equation}

\noindent Structural bending check:

\begin{equation}
F'_b = 10.05 > 7.15 = \sigma_{max} \implies OK
\end{equation}

\paragraph{Perpendicular to grain strength checking:}

\noindent Maximum induced reaction:
\begin{align}
  R_{max}&= 8.56\ kN\\
  \sigma_{max,perp}&= 1.61\ MPa
\end{align}

\begin{equation}
F'_{c,perp} = 2.79 > 1.61 = \sigma_{max,perp} \implies OK
\end{equation}

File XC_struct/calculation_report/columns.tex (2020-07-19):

\subsection{Columns}

\begin{figure}
  \begin{center}
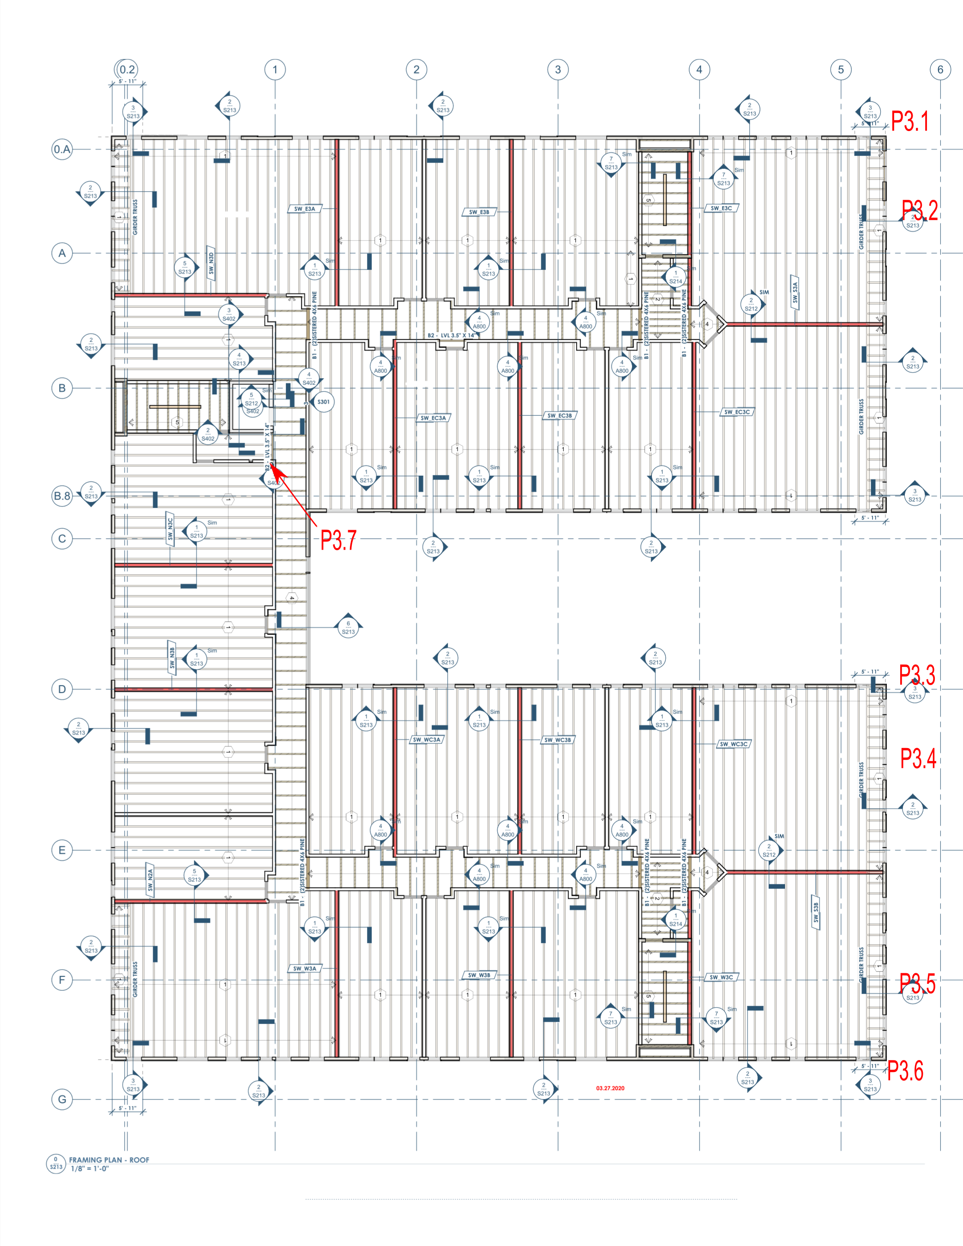
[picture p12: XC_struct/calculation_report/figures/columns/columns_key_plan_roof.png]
  
  \end{center}
  \caption{Columns key plan. Roof}\label{fg_columns_key_plan_roof}
\end{figure}

\begin{figure}
  \begin{center}
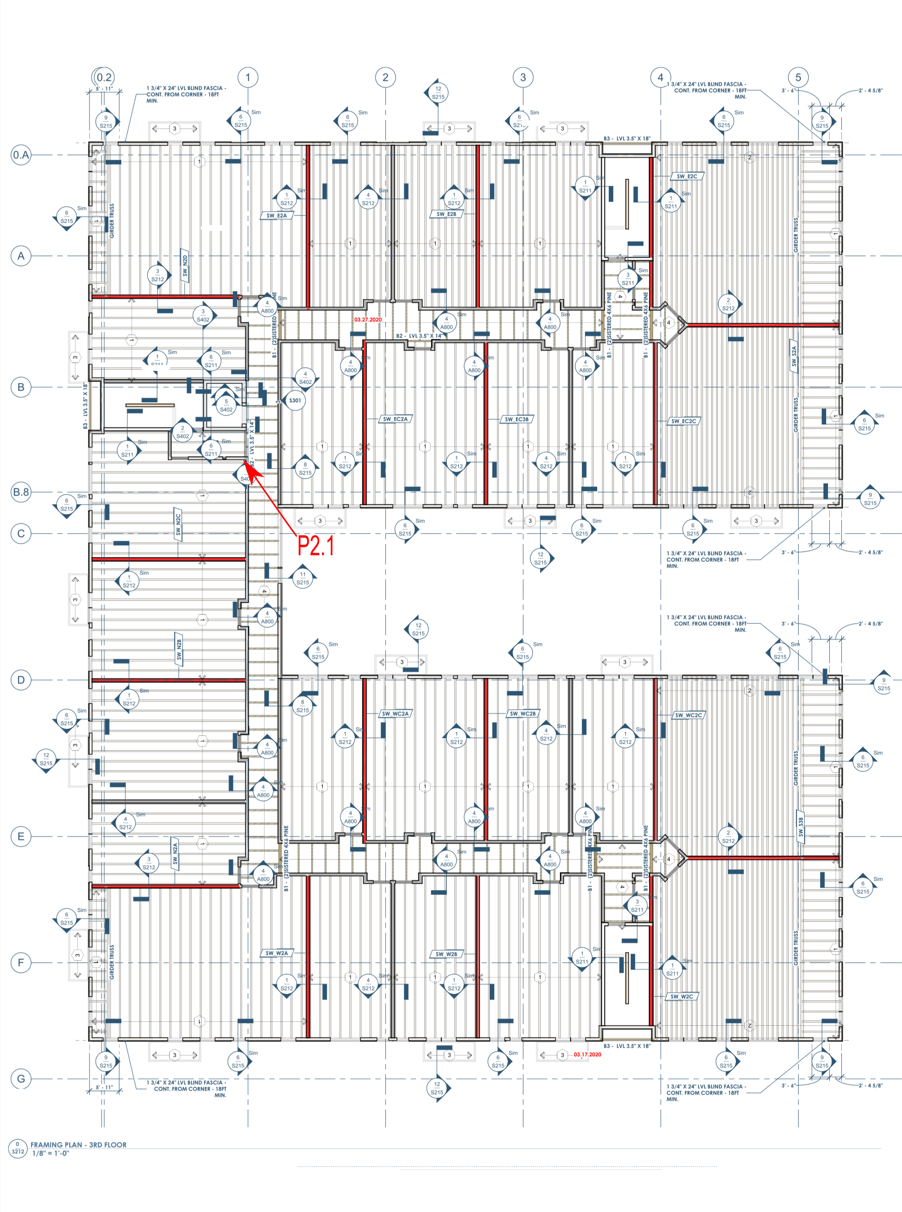
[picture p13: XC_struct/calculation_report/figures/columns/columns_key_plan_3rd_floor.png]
  
  \end{center}
  \caption{Columns key plan. Third floor}\label{fg_columns_key_plan_3rd_floor}
\end{figure}

\begin{figure}
  \begin{center}
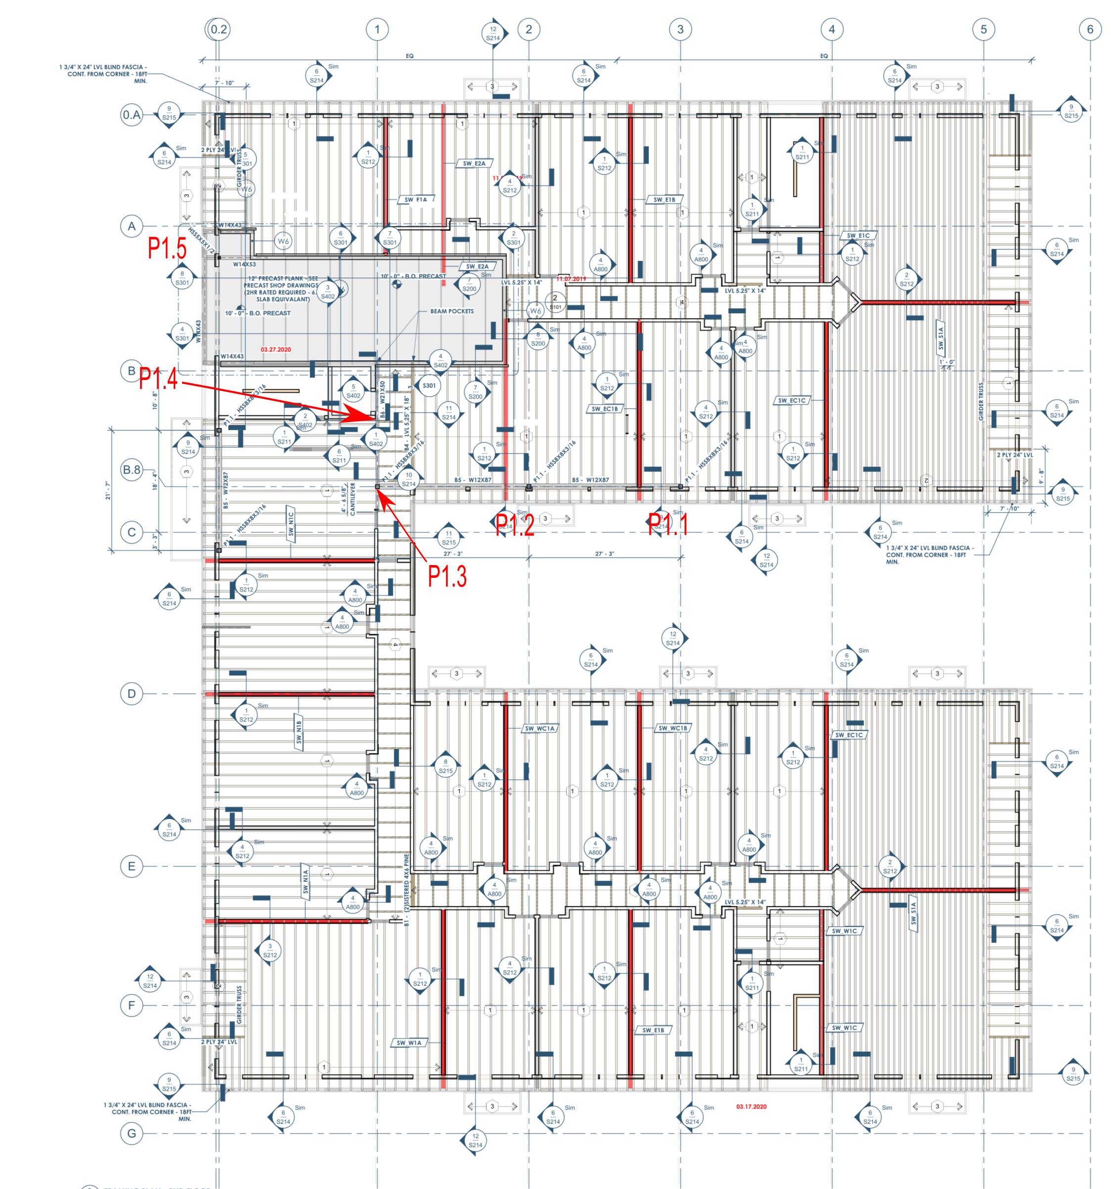
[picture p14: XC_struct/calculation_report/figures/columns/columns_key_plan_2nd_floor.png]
  
  \end{center}
  \caption{Columns key plan. Second floor}\label{fg_columns_key_plan_2nd_floor}
\end{figure}

\subsubsection{Columns P3.1 to P3.6}

\paragraph{Loads.}

\begin{itemize}
\item Load from header: 4.8 kN
\end{itemize}

\paragraph{Internal forces.}

\noindent Maximum induced axial force:

\begin{equation}
  N_{max}= 4.8\ kN
\end{equation}

\paragraph{Compression check.}

\subparagraph{Mechanical properties}

\begin{itemize}
\item Species: Spruce-pine-fir No.2
\item $E_{min}= 2.55\ GPa$
\item $F_c= 2.93\ MPa$.
\item Sections dimensions: (6x6''), effective (5.5x5.5'')= 139.7 x 139.7  mm.
\item Unbraced lenght x axis: 3.45 m
\item Unbraced lenght y axis: 2.59 m
\item Column stability factor: $C_P= 0.74$
\end{itemize}

\begin{equation}
  N'_s= 42.46\ kN
\end{equation}

\noindent Structural compression check: $N'_s = 42.46 > 4.8 = N_{max} \implies OK$

\subsubsection{Column P3.7}

\paragraph{Loads.}

\begin{itemize}
\item Load from header 3.10: 27.61 kN
\end{itemize}

\paragraph{Internal forces.}

\noindent Maximum induced axial force:

\begin{equation}
  N_{max}= 27.61\ kN
\end{equation}

\paragraph{Compression check.}

\subparagraph{Mechanical properties}

\begin{itemize}
\item Species: Douglas fir-Larch dense structural
\item $E_{min}= 4.27\ GPa$
\item $F_c= 9.31\ MPa$.
\item Sections dimensions: (4x6''), effective (3.5x5.5'')= 88.9 x 139.7  mm.
\item Unbraced lenght x axis: 2.902 m
\item Unbraced lenght y axis: 0.5 m
\item Column stability factor: $C_P= 0.64$
\end{itemize}

\begin{equation}
  N'_s= 74.34\ kN
\end{equation}

\noindent Structural compression check: $N'_s = 74.34 > 27.61 = N_{max} \implies OK$

\subsubsection{Column P2.1}

\paragraph{Loads.}

\begin{itemize}
\item Load from header 2.07 and post P3.10: 55.22 kN
\end{itemize}

\paragraph{Internal forces.}

\noindent Maximum induced axial force:

\begin{equation}
  N_{max}= 55.22\ kN
\end{equation}

\paragraph{Compression check.}

\subparagraph{Mechanical properties}

\begin{itemize}
\item Species: Douglas fir-Larch dense structural
\item $E_{min}= 4.27\ GPa$
\item $F_c= 9.31\ MPa$.
\item Sections dimensions: (4x6''), effective (3.5x5.5'')= 88.9 x 139.7  mm.
\item Unbraced lenght x axis: 2.902 m
\item Unbraced lenght y axis: 0.5 m
\item Column stability factor: $C_P= 0.64$
\end{itemize}

\begin{equation}
  N'_s= 74.34\ kN
\end{equation}

\noindent Structural compression check: $N'_s = 74.34 > 55.22 = N_{max} \implies OK$

\subsubsection{2x6 wood stud capacity}

\paragraph{Compression capacity.}

\subparagraph{Mechanical properties.}

\begin{itemize}
\item Species: Hem-fir stud select structural.
\item $E_{min}= 3.24\ GPa$
\item $F_c= 8.27\ MPa$.
\item Sections dimensions: (2x6''), effective (1.5x5.5'')= 38.1 x 139.7  mm.
\item Unbraced lenght x axis: 0.3 m
\item Unbraced lenght y axis: 3.45 m
\item Column stability factor: $C_P= 0.45$
\end{itemize}

\begin{equation}
  N'_s= 19.90\ kN
\end{equation}

\subsubsection{Columns P1.1, P1.2 and P1.3}

\paragraph{Loads.}

\begin{itemize}
\item Column P1.3: load from corridor beam and courtyard beam: $192.97\ kN + 65.99\ kN= 258.96\ kN$
\item Column P1.2: load from courtyard beam: $219.96\ kN$
\item Column P1.1: load from courtyard beam: $65.99\ kN$
\end{itemize}

\paragraph{Internal forces.}

\noindent Maximum induced axial force:

\begin{equation}
  N_{max}= 258.96\ kN
  M_{y,max}= 5.18\ kN m
  M_{z,max}= 12.95\ kN m
\end{equation}

\paragraph{Mechanical properties.}

\begin{itemize}
\item Structural shape: HSS8x8x3/16
\item Height: 3.51 m
\item Steel: ASTM A500 Grade B ($F_y= 315.0\ MPa$)
\item Effective length buckling coefficient: $K= 1$
\item Compression
\begin{itemize}
  \item Limiting width-to-thickness ratio $\lambda_r= 35.28$
  \item Classification of walls: slender
\end{itemize}
\end{itemize}

\paragraph{Compression check.}

\begin{itemize}
\item Nominal compressive strength: $P_n= \frac{844.37}{1.67}= 505.61\ kN$
\item Nominal flexural strength: $M_n= \frac{58.55}{1.67}= 35.06\ kN m$
\end{itemize}

\noindent Capacity factor according to equation H1-1 of AISC 360-16:

\begin{equation}
  \frac{P_d}{P_n}+\frac{8}{9} (\frac{M_{yd}}{M_{yn}}+\frac{M_{zd}}{M_{zn}})= 0.97 < 1.0 \implies OK
  \end{equation}

\subsubsection{Column P1.4}

\paragraph{Loads.}

\begin{itemize}
\item Column P1.4: load from corridor: $125.49\ kN$
\end{itemize}

\paragraph{Internal forces.}

\noindent Maximum induced axial force:

\begin{equation}
  N_{max}= 125.49\ kN
  M_{y,max}= 7.33\ kN m
  M_{z,max}= 6.27\ kN m
\end{equation}

\paragraph{Mechanical properties.}

\begin{itemize}
\item Structural shape: HSS7X7X3/16
\item Height: 3.51 m
\item Steel: ASTM A500 Grade B ($F_y= 315.0\ MPa$)
\item Effective length buckling coefficient: $K= 1$
\item Compression
\begin{itemize}
  \item Limiting width-to-thickness ratio $\lambda_r= 35.28$
  \item Classification of walls: slender
\end{itemize}
\end{itemize}

\paragraph{Compression check.}

\begin{itemize}
\item Nominal compressive strength: $P_n= \frac{774.19}{1.67}= 463.59\ kN$
\item Nominal flexural strength: $M_n= \frac{51.02}{1.67}= 30.55\ kN m$
\end{itemize}

\noindent Capacity factor according to equation H1-1 of AISC 360-16:

\begin{equation}
  \frac{P_d}{P_n}+\frac{8}{9} (\frac{M_{yd}}{M_{yn}}+\frac{M_{zd}}{M_{zn}})= 0.67 < 1.0 \implies OK
  \end{equation}

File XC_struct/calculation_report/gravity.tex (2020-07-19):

\subsection{Gravity}

\input{trusses.tex}
\input{joists.tex}
\input{headers.tex}
\input{steel_beams.tex}
%%\input{cantilevers.tex}
\input{columns.tex}
\input{bearing_walls.tex}

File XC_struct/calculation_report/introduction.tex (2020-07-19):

This report describes the calculation procedure and data considered in order to design the structure of a new apartment building in Eau Claire, Wisconsin.

The construction consists in a three-story apartment building with a first-floor footprint of about 19,500 square feet, a below-grade parking garage with a footprint of about 27,200 square feet, perimeter retaining walls, a slab-on-grade, and a conventional foundation system.

The first floor system is precast hollow core concrete plank on precast beams and columns. For the upper floors and roof, the system is wood-framed. Retaining walls and slab on grade are comprised of cast in place concrete, except for three reinforced CMU walls next to the garage aisles, that will be demolished during the second phase of construction.

The foundation uses conventional cast in place concrete footings to transfer axial compression and lateral loads to the ground.

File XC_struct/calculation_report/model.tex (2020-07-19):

\subsection{Structural model}
A three-dimensional elastic computer model of the substructure is analyzed using XC. The model includes first floor frame and columns (see figure \ref{model}). The hollow core planks are modelled using shell elements, while beams and columns are modelled using frame elements. Loads transmited by 2$^{nd}$, 3$^{rd}$ floors and roof are applied to the 1$^{st}$. Load layout is shown in figure \ref{loadLay}. See in figures \ref{LC_D} to \ref{LC_W_NS} load distribution for each load case.\\

Linear loads are expressed in $\mathrm{kN/m}$ and surface loads in $\mathrm{kN/m^2}$, where:\\
\begin{center}
  \begin{tabular}{ll}
    1 $\mathrm{kN/m}$ = & 68.52178 lb/ft \\
    1 $\mathrm{kN/m^2}$ = & 20.885434 psf \\
  \end{tabular}
  \end{center}

\captionsetup[figure]{font=footnotesize}
\twocolumn
\begin{Figure}
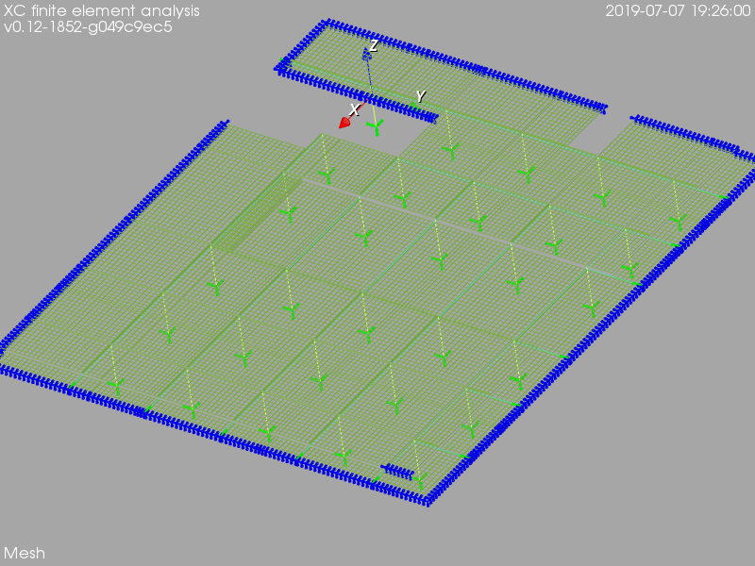
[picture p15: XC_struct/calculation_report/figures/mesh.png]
    
    \captionof{figure}{Elastic model, mesh.}
    \label{model}
\end{Figure}
\begin{Figure}
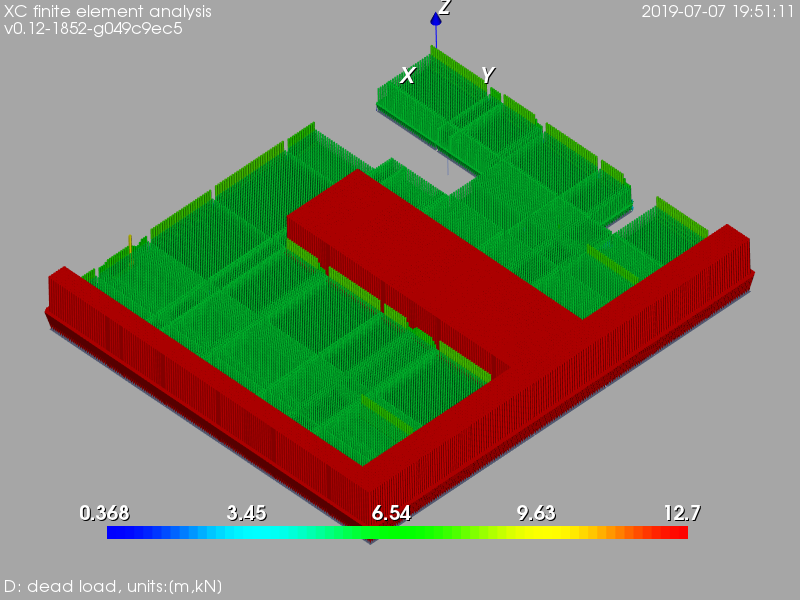
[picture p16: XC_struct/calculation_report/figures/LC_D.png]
    
    \captionof{figure}{Load case D: dead load (include slab selfweight) [units: kN,m].}
    \label{LC_D}
\end{Figure}

\begin{Figure}
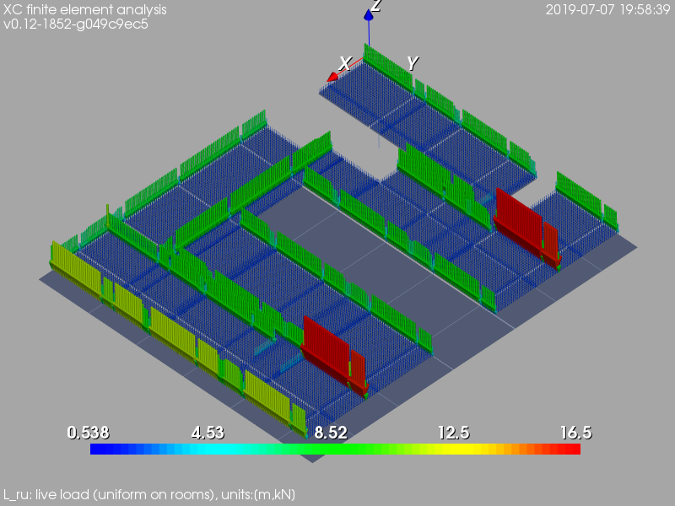
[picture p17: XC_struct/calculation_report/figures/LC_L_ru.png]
    
    \captionof{figure}{Load case Lru: live load (uniform on rooms) [units: kN,m].}
    \label{LC_L_ru}
\end{Figure}

\begin{Figure}
    
    \captionof{figure}{Load case Lrs:  live load (staggered pattern on rooms) [units: kN,m].}
    \label{LC_L_rs}
\end{Figure}

\begin{Figure}
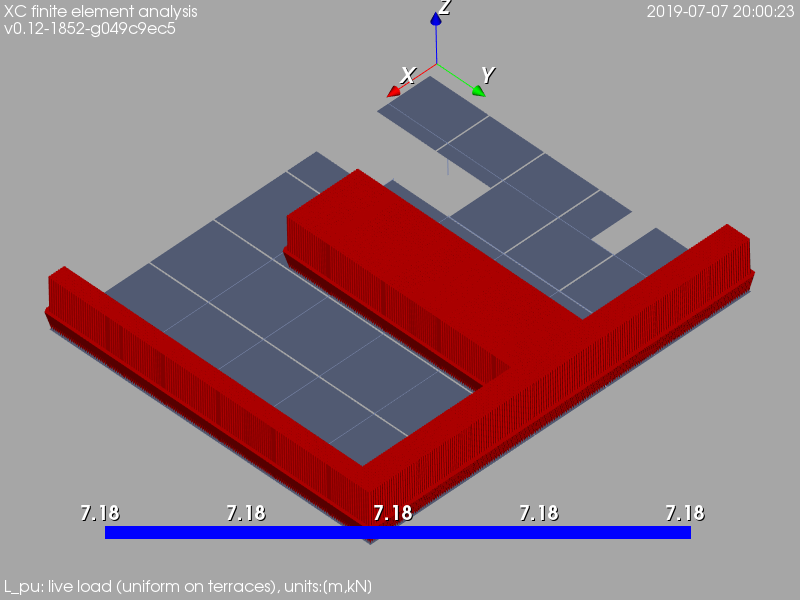
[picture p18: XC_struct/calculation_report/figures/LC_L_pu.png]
    
    \captionof{figure}{Load case Lpu: live load (uniform on patios) [units: kN,m].}
    \label{LC_L_pu}
\end{Figure}

\begin{Figure}
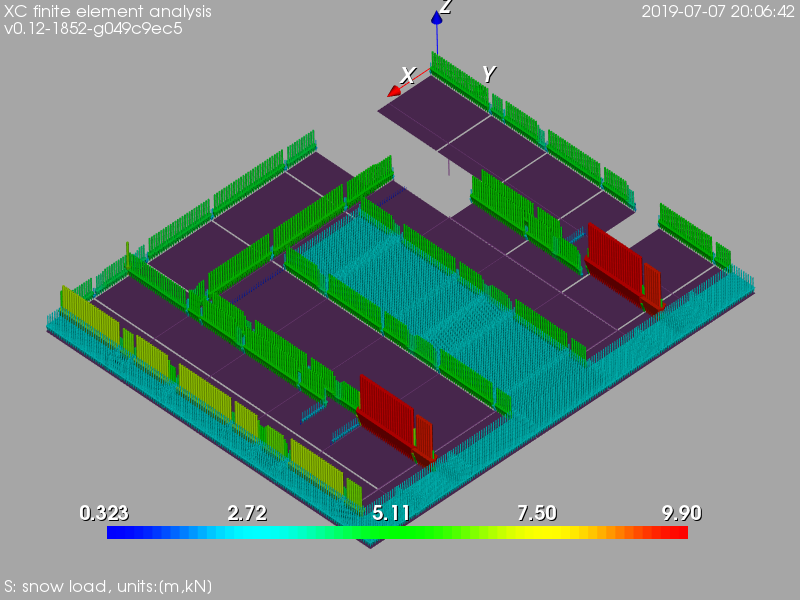
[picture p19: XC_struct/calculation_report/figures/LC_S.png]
    
    \captionof{figure}{Load case S: snow [units: kN,m].}
    \label{LC_S}
\end{Figure}
\begin{Figure}
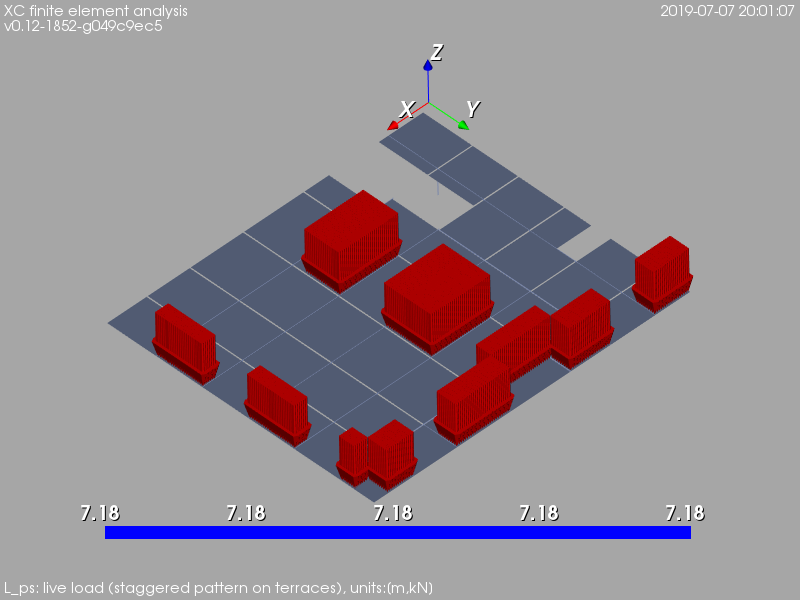
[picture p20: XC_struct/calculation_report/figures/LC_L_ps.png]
    
    \captionof{figure}{Load case Lps:  live load (staggered pattern on patios) [units: kN,m].}
    \label{LC_L_ps}
\end{Figure}

\begin{Figure}
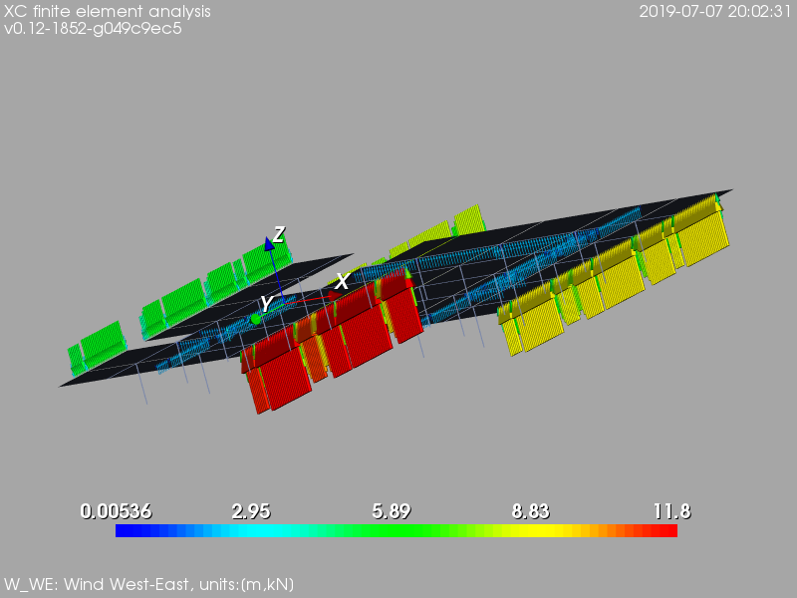
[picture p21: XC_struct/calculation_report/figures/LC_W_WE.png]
    
    \captionof{figure}{Load case W\_WE:  wind West-East [units: kN,m].}
    \label{LC_W_WE}
\end{Figure}

\begin{Figure}
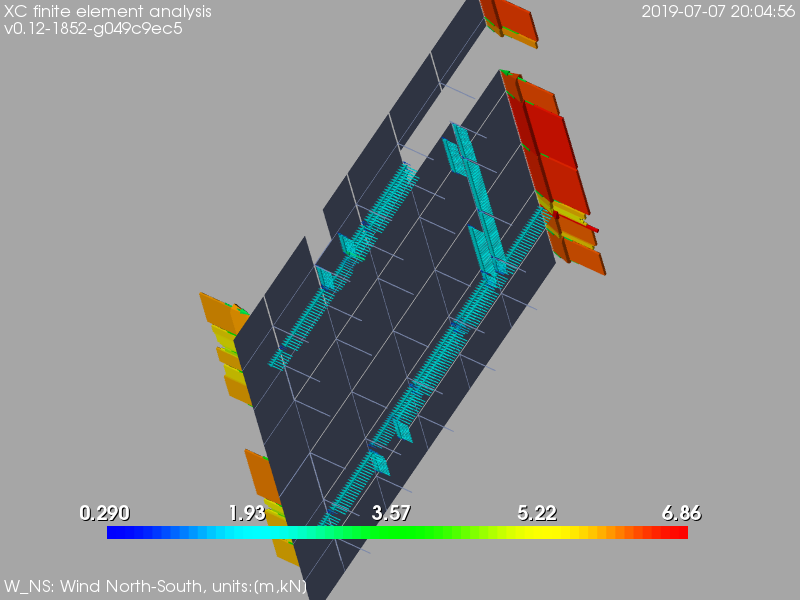
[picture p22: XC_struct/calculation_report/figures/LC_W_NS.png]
    
    \captionof{figure}{Load case W\_NS: wind North-South [units: kN,m].}
    \label{LC_W_NS}
\end{Figure}
\onecolumn
\begin{Figure}
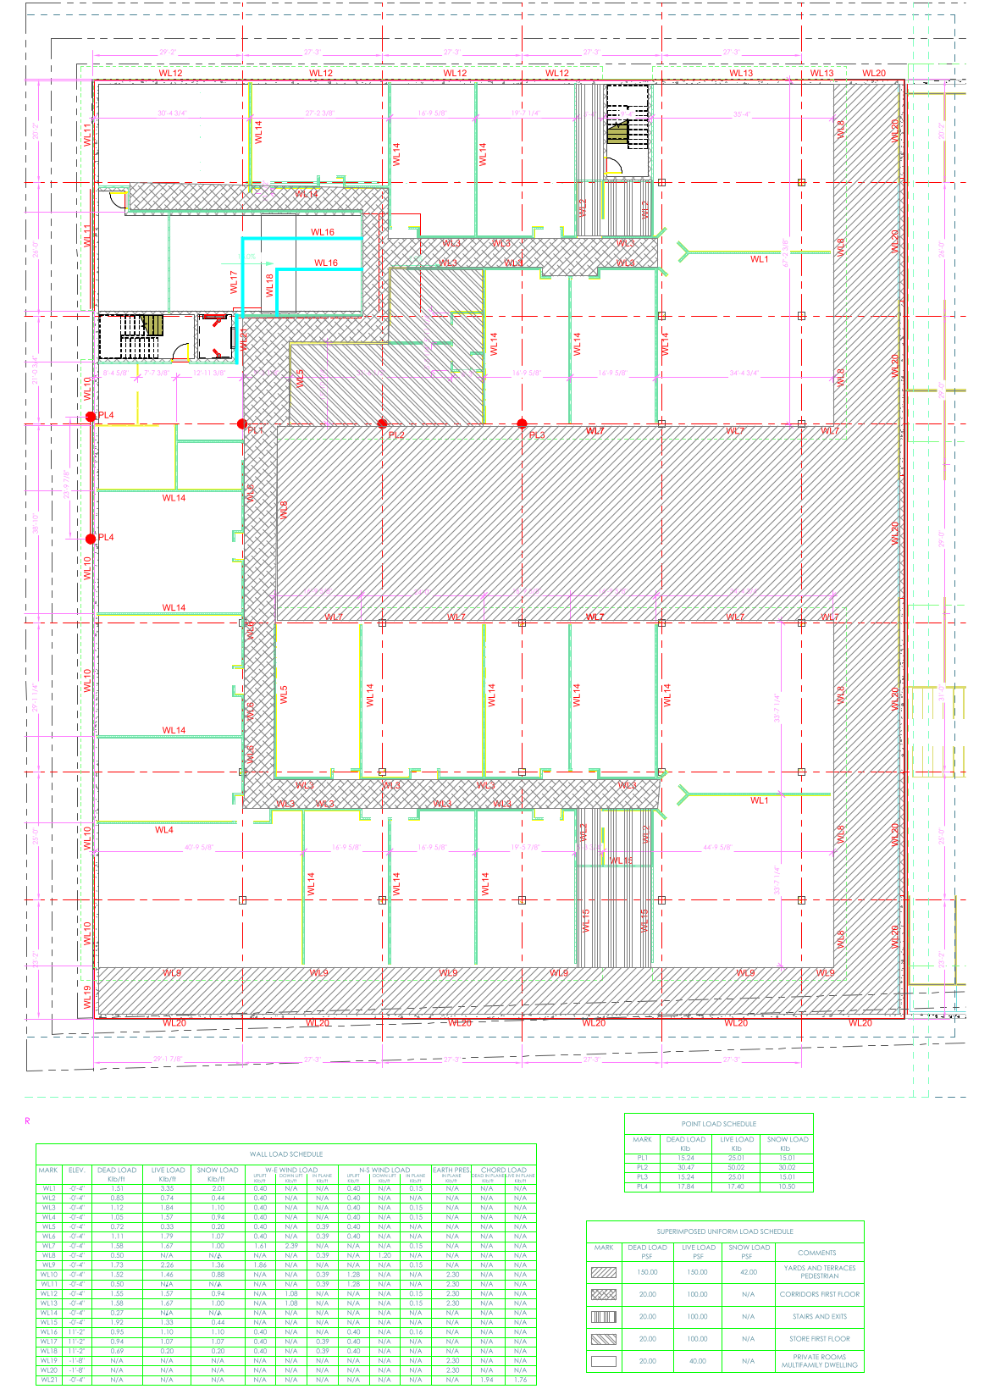
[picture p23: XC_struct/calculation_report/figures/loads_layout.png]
    
    \captionof{figure}{Load layout on first floor.}
    \label{loadLay}
\end{Figure}

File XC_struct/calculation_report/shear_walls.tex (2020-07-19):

\subsection{Lateral. Diaphragms/Shear walls}

\subsubsection{East and West facades shear walls}
The shear walls of the East facade are those denoted by the letters ``E'' and ``W'' in figures \ref{fg_3rd_floor_key_plan} to \ref{fg_1st_floor_key_plan}. The wind load on each floor per unit length is as follows:

\begin{center}
  \begin{tabular}{|l|c|}
    \hline
    \textbf{floor} & \textbf{wind force}\\
    & $(kN/m)$\\
    \hline
    roof & 2.34 \\
    third & 1.67 \\
    second & 1.71 \\
    \hline
  \end{tabular}
\end{center}  

\noindent The shear values obtained for each wall are as follows:

\begin{center}
  \begin{tabular}{|l|c|c|c|}
    \hline
    \textbf{floor} & \multicolumn{3}{c|}{\textbf{shear force} $(kN)$}\\
                   & EA/WA & EB/WB & EC/WC \\
    \hline
    roof & 68.76 & -21.54 & 59.39 \\
    third & 48.93 & -15.32 & 42.26 \\
    second & 118.86 & 44.95 & 31.49 \\
    \hline
  \end{tabular}
\end{center}  

\noindent And the cumulated values are:

\begin{center}
  \begin{tabular}{|l|c|c|c|}
    \hline
    \textbf{floor} & \multicolumn{3}{c|}{\textbf{shear force} $(kN)$}\\
                   & EA/WA & EB/WB & EC/WC \\
    \hline
    roof & 68.76 & -21.54 & 59.39 \\
    third & 117.70 & -36.86 & 101.65 \\
    second & 118.86 & 8.09 & 133.14 \\
    \hline
  \end{tabular}
\end{center}

\noindent leading to the following dimensions:

\begin{center}
  \begin{tiny}
  \begin{longtable}{|c|p{1.25cm}|c|c|c|c|c|c|c|c|c|c|c|p{2cm}|}
    \hline
    \multicolumn{11}{|c|}{}& \multicolumn{2}{p{1.1cm}|}{Bottom plate attachment (foundation)} & Bottom plate attachment (floor to floor)\\
    \hline
    \rotatebox[origin=c]{90}{Shear wall} & \rotatebox[origin=c]{90}{Sheathing material} & \rotatebox[origin=c]{90}{Panel thickness} & \rotatebox[origin=c]{90}{Blocking} & \rotatebox[origin=c]{90}{Minimum fastener penetration} & \rotatebox[origin=c]{90}{Fastener type and size} & \rotatebox[origin=c]{90}{Panel edge fastener spacing}  & \rotatebox[origin=c]{90}{Nominal unit shear capacity $v_w$} & \rotatebox[origin=c]{90}{Hold-down anchor capacity} & \rotatebox[origin=c]{90}{Hold-down studs} & \rotatebox[origin=c]{90}{Hold-down anchor type} & \rotatebox[origin=c]{90}{Number of bolts} & \rotatebox[origin=c]{90}{Bolt spacing}  & \\
\hline
ID &  & (in) &  & (in) &  & (in) & (plf) & (kip) & & HD & & (in) & \\
\hline
E3A & WSP – sheathing & 19/32 & Y & 1-1/2 & 10d & 4 & 1430 & 3 & (1) & U4-SDS2.5 & - & - & wood screws 20 (d= 0.32 in) at 16 in. o/c; 46 fasteners in 2 rows.\\
\hline
E3B & WSP – sheathing & 3/8 & N & 1-3/8 & 8d & 6 & 560 & - & - &  & - & - & 16d (d= 0.268 in) nails at 12 in. o/c; 30 fasteners in 1 row.\\
\hline
E3C & WSP – sheathing & 19/32 & Y & 1-1/2 & 10d & 4 & 1430 & 6 & (2) & U11-SDS2.5 & - & - & SDWS log screw (d= 0.197 in) at 15 in. o/c; 32 fasteners in 2 rows.\\
\hline
E2A & WSP – sheathing & 19/32 & Y & 1-1/2 & 10d & 3 & 1860 & 7 & (3) & U11-SDS2.5 & - & - & SDWS log screw (d= 0.197 in) at 11 in. o/c; 64 fasteners in 2 rows.\\
\hline
E2B & WSP – sheathing & 3/8 & N & 1-3/8 & 8d & 6 & 560 & 1 & (1) & U4-SDS2.5 & - & - & 16d (d= 0.268 in) nails at 14 in. o/c; 51 fasteners in 2 rows.\\
\hline
E2C & WSP – sheathing & 19/32 & Y & 1-1/2 & 10d & 2 & 2435 & 11 & (4) & 19 & - & - & SDWS log screw (d= 0.197 in) at 9 in. o/c; 54 fasteners in 2 rows.\\
\hline
E1A & WSP – sheathing & 19/32 & Y & 1-1/2 & 10d & 2 & 2435 & 13 & (4) & 19 & 7 & 36 & SDWS log screw (d= 0.197 in) at 7 in. o/c; 64 fasteners in 2 rows.\\
\hline
E1B & WSP – sheathing & 3/8 & N & 1-3/8 & 8d & 6 & 560 & - & - &  & 11 & 36 & 16d (d= 0.268 in) nails at 32 in. o/c; 12 fasteners in 1 row.\\
\hline
E1C & WSP – sheathing & 19/32 & Y & 1-1/2 & 10d & 2 & 2435 & 9 & (3) & 19 & 11 & 36 & SDWS log screw (d= 0.197 in) at 10 in. o/c; 72 fasteners in 2 rows.\\
\hline
W3A & WSP – sheathing & 19/32 & Y & 1-1/2 & 10d & 4 & 1430 & 3 & (1) & U4-SDS2.5 & - & - & wood screws 20 (d= 0.32 in) at 16 in. o/c; 46 fasteners in 2 rows.\\
\hline
W3B & WSP – sheathing & 3/8 & N & 1-3/8 & 8d & 6 & 560 & - & - &  & - & - & 16d (d= 0.268 in) nails at 12 in. o/c; 30 fasteners in 1 row.\\
\hline
W3C & WSP – sheathing & 19/32 & Y & 1-1/2 & 10d & 4 & 1430 & 6 & (2) & U11-SDS2.5 & - & - & SDWS log screw (d= 0.197 in) at 15 in. o/c; 32 fasteners in 2 rows.\\
\hline
W2A & WSP – sheathing & 19/32 & Y & 1-1/2 & 10d & 3 & 1860 & 7 & (3) & U11-SDS2.5 & - & - & SDWS log screw (d= 0.197 in) at 11 in. o/c; 64 fasteners in 2 rows.\\
\hline
W2B & WSP – sheathing & 3/8 & N & 1-3/8 & 8d & 6 & 560 & 1 & (1) & U4-SDS2.5 & - & - & 16d (d= 0.268 in) nails at 14 in. o/c; 51 fasteners in 2 rows.\\
\hline
W2C & WSP – sheathing & 19/32 & Y & 1-1/2 & 10d & 2 & 2435 & 11 & (4) & 19 & - & - & SDWS log screw (d= 0.197 in) at 9 in. o/c; 54 fasteners in 2 rows.\\
\hline
W1A & WSP – sheathing & 19/32 & Y & 1-1/2 & 10d & 2 & 2435 & 13 & (4) & 19 & 9 & 30 & SDWS log screw (d= 0.197 in) at 7 in. o/c; 64 fasteners in 2 rows.\\
\hline
W1B & WSP – sheathing & 3/8 & N & 1-3/8 & 8d & 6 & 560 & - & - &  & 11 & 36 & 16d (d= 0.268 in) nails at 32 in. o/c; 12 fasteners in 1 row.\\
\hline
W1C & WSP – sheathing & 19/32 & Y & 1-1/2 & 10d & 2 & 2435 & 9 & (3) & 19 & 11 & 36 & SDWS log screw (d= 0.197 in) at 10 in. o/c; 72 fasteners in 2 rows.\\
\hline
\hline
  \end{longtable}
  \end{tiny}
  \end{center}

\subsubsection{Courtyard facades shear walls}
The shear walls of the courtyard East and West facades are those denoted by the letters ``EC'' or ``WC'' in figures \ref{fg_3rd_floor_key_plan} to \ref{fg_1st_floor_key_plan}. The wind load on each floor per unit length is as follows:

\begin{center}
  \begin{tabular}{|l|c|}
    \hline
    \textbf{floor} & \textbf{wind force}\\
    & $(kN/m)$\\
    \hline
    roof & 2.50 \\
    third & 1.98 \\
    second & 2.03 \\
    \hline
  \end{tabular}
\end{center}  

\noindent The shear values obtained for each wall are as follows:

\begin{center}
  \begin{tabular}{|l|c|c|c|}
    \hline
    \textbf{floor} & \multicolumn{3}{c|}{\textbf{shear force} $(kN)$}\\
                   & ECA/WCA & ECB/WCB & ECC/WCC \\
    \hline
    roof & 30.35 & -4.77 & 59.26 \\
    third & 24.06 & -3.78 & 46.97 \\
    second & 24.61 & -3.87 & 48.04 \\
    \hline
  \end{tabular}
\end{center}  

\noindent And the cumulated values are:

\begin{center}
  \begin{tabular}{|l|c|c|c|}
    \hline
    \textbf{floor} & \multicolumn{3}{c|}{\textbf{shear force} $(kN)$}\\
                   & ECA/WCA & ECB/WCB & ECC/WCC \\
    \hline
roof & 30.35 & -4.77 & 59.26 \\
third & 54.41 & -8.56 & 106.22 \\
second & 79.02 & -12.43 & 154.27 \\
    \hline
  \end{tabular}
\end{center}

\noindent leading to the following dimensions:

\begin{center}
  \begin{tiny}
  \begin{longtable}{|c|p{1.25cm}|c|c|c|c|c|c|c|c|c|c|c|p{2cm}|}
    \hline
    \multicolumn{11}{|c|}{}& \multicolumn{2}{p{1.1cm}|}{Bottom plate attachment (foundation)} & Bottom plate attachment (floor to floor)\\
    \hline
    \rotatebox[origin=c]{90}{Shear wall} & \rotatebox[origin=c]{90}{Sheathing material} & \rotatebox[origin=c]{90}{Panel thickness} & \rotatebox[origin=c]{90}{Blocking} & \rotatebox[origin=c]{90}{Minimum fastener penetration} & \rotatebox[origin=c]{90}{Fastener type and size} & \rotatebox[origin=c]{90}{Panel edge fastener spacing}  & \rotatebox[origin=c]{90}{Nominal unit shear capacity $v_w$} & \rotatebox[origin=c]{90}{Hold-down anchor capacity} & \rotatebox[origin=c]{90}{Hold-down studs} & \rotatebox[origin=c]{90}{Hold-down anchor type} & \rotatebox[origin=c]{90}{Number of bolts} & \rotatebox[origin=c]{90}{Bolt spacing}  & \\
\hline
ID &  & (in) &  & (in) &  & (in) & (plf) & (kip) & & HD & & (in) & \\
\hline
EC3A & WSP – sheathing & 19/32 & Y & 1-1/2 & 10d & 6 & 950 & 0 & - &  & - & - & 16d (d= 0.268 in) nails at 18 in. o/c; 42 fasteners in 2 rows.\\
\hline
EC3B & WSP – sheathing & 3/8 & N & 1-3/8 & 8d & 6 & 560 & - & - &  & - & - & 16d (d= 0.268 in) nails at 60 in. o/c; 7 fasteners in 1 row.\\
\hline
EC3C & WSP – sheathing & 19/32 & Y & 1-1/2 & 10d & 6 & 950 & 3 & (1) & U4-SDS2.5 & - & - & wood screws 20 (d= 0.32 in) at 19 in. o/c; 40 fasteners in 2 rows.\\
\hline
EC2A & WSP – sheathing & 19/32 & Y & 1-1/2 & 10d & 3 & 1860 & 2 & (1) & U4-SDS2.5 & - & - & wood screws 20 (d= 0.32 in) at 21 in. o/c; 36 fasteners in 2 rows.\\
\hline
EC2B & WSP – sheathing & 3/8 & N & 1-3/8 & 8d & 6 & 560 & - & - &  & - & - & 16d (d= 0.268 in) nails at 32 in. o/c; 12 fasteners in 1 row.\\
\hline
EC2C & WSP – sheathing & 19/32 & Y & 1-1/2 & 10d & 3 & 1860 & 6 & (2) & U11-SDS2.5 & - & - & SDWS log screw (d= 0.197 in) at 12 in. o/c; 58 fasteners in 2 rows.\\
\hline
EC1A & WSP – sheathing & 19/32 & Y & 1-1/2 & 10d & 2 & 2435 & 11 & (4) & 19 & 6 & 36 & SDWS log screw (d= 0.197 in) at 9 in. o/c; 42 fasteners in 2 rows.\\
\hline
EC1B & WSP – sheathing & 3/8 & N & 1-3/8 & 8d & 6 & 560 & - & - &  & 11 & 36 & 16d (d= 0.268 in) nails at 22 in. o/c; 17 fasteners in 1 row.\\
\hline
EC1C & WSP – sheathing & 19/32 & Y & 1-1/2 & 10d & 2 & 2435 & 11 & (4) & 19 & 11 & 36 & SDWS log screw (d= 0.197 in) at 9 in. o/c; 82 fasteners in 2 rows.\\
\hline
WC3A & WSP – sheathing & 19/32 & Y & 1-1/2 & 10d & 6 & 950 & 0 & - &  & - & - & 16d (d= 0.268 in) nails at 18 in. o/c; 42 fasteners in 2 rows.\\
\hline
WC3B & WSP – sheathing & 3/8 & N & 1-3/8 & 8d & 0 & 560 & - & - &  & - & - & 16d (d= 0.268 in) nails at 60 in. o/c; 7 fasteners in 1 row.\\
\hline
WC3C & WSP – sheathing & 19/32 & Y & 1-1/2 & 10d & 6 & 950 & 3 & (1) & U4-SDS2.5 & - & - & wood screws 20 (d= 0.32 in) at 19 in. o/c; 40 fasteners in 2 rows.\\
\hline
WC2A & WSP – sheathing & 19/32 & Y & 1-1/2 & 10d & 3 & 1860 & 2 & (1) & U4-SDS2.5 & - & - & wood screws 20 (d= 0.32 in) at 21 in. o/c; 36 fasteners in 2 rows.\\
\hline
WC2B & WSP – sheathing & 3/8 & N & 1-3/8 & 8d & 6 & 560 & - & - &  & - & - & 16d (d= 0.268 in) nails at 32 in. o/c; 12 fasteners in 1 row.\\
\hline
WC2C & WSP – sheathing & 19/32 & Y & 1-1/2 & 10d & 3 & 1860 & 6 & (2) & U11-SDS2.5 & - & - & SDWS log screw (d= 0.197 in) at 12 in. o/c; 58 fasteners in 2 rows.\\
\hline
WC1A & WSP – sheathing & 19/32 & Y & 1-1/2 & 10d & 2 & 2435 & 11 & (4) & 19 & 6 & 36 & SDWS log screw (d= 0.197 in) at 9 in. o/c; 42 fasteners in 2 rows.\\
\hline
WC1B & WSP – sheathing & 3/8 & N & 1-3/8 & 8d & 6 & 560 & - & - &  & 11 & 36 & 16d (d= 0.268 in) nails at 22 in. o/c; 17 fasteners in 1 row.\\
\hline
WC1C & WSP – sheathing & 19/32 & Y & 1-1/2 & 10d & 2 & 2435 & 11 & (4) & 19 & 11 & 36 & SDWS log screw (d= 0.197 in) at 9 in. o/c; 82 fasteners in 2 rows.\\
    \hline
  \end{longtable}
  \end{tiny}
  \end{center}

\subsubsection{South facades shear walls}
The shear walls of the South facade are those denoted by the letter ``S'' in figures \ref{fg_3rd_floor_key_plan} to \ref{fg_1st_floor_key_plan}. The wind load on each floor per unit length is as follows:

\begin{center}
  \begin{tabular}{|l|c|}
    \hline
    \textbf{floor} & \textbf{wind force}\\
    & $(kN/m)$\\
    \hline
    roof & 2.50 \\
    third & 1.98 \\
    second & 2.03 \\
    \hline
  \end{tabular}
\end{center}  

\noindent The shear values obtained for each wall are as follows:

\begin{center}
  \begin{tabular}{|l|c|}
    \hline
    \textbf{floor} & \textbf{shear force} $(kN)$\\
                   & SA/SB \\
    \hline
    roof & 54.95 \\
    third & 43.56 \\
    second & 44.55 \\
    \hline
  \end{tabular}
\end{center}  

\noindent And the cumulated values are:

\begin{center}
  \begin{tabular}{|l|c|}
    \hline
    \textbf{floor} & \textbf{shear force} $(kN)$\\
                   & SA/SB \\
    \hline
    roof & 54.95 \\
    third & 98.51 \\
    second & 143.06 \\
    \hline
  \end{tabular}
\end{center}  

\noindent leading to the following dimensions:
\begin{center}
  \begin{tiny}
  \begin{longtable}{|c|p{1.25cm}|c|c|c|c|c|c|c|c|c|c|c|p{2cm}|}
    \hline
    \multicolumn{11}{|c|}{}& \multicolumn{2}{p{1.1cm}|}{Bottom plate attachment (foundation)} & Bottom plate attachment (floor to floor)\\
    \hline
    \rotatebox[origin=c]{90}{Shear wall} & \rotatebox[origin=c]{90}{Sheathing material} & \rotatebox[origin=c]{90}{Panel thickness} & \rotatebox[origin=c]{90}{Blocking} & \rotatebox[origin=c]{90}{Minimum fastener penetration} & \rotatebox[origin=c]{90}{Fastener type and size} & \rotatebox[origin=c]{90}{Panel edge fastener spacing}  & \rotatebox[origin=c]{90}{Nominal unit shear capacity $v_w$} & \rotatebox[origin=c]{90}{Hold-down anchor capacity} & \rotatebox[origin=c]{90}{Hold-down studs} & \rotatebox[origin=c]{90}{Hold-down anchor type} & \rotatebox[origin=c]{90}{Number of bolts} & \rotatebox[origin=c]{90}{Bolt spacing}  & \\
\hline
ID &  & (in) &  & (in) &  & (in) & (plf) & (kip) & & HD & & (in) & \\
\hline
S3A & WSP – sheathing & 19/32 & Y & 1-1/2 & 10d & 6 & 950 & 2 & (1) & U4-SDS2.5 & - & - & wood screws 20 (d= 0.32 in) at 21 in. o/c; 36 fasteners in 2 rows.\\
\hline
S3B & WSP – sheathing & 19/32 & Y & 1-1/2 & 10d & 6 & 950 & 2 & (1) & U4-SDS2.5 & - & - & wood screws 20 (d= 0.32 in) at 21 in. o/c; 36 fasteners in 2 rows.\\
\hline
S2A & WSP – sheathing & 19/32 & Y & 1-1/2 & 10d & 3 & 1860 & 6 & (2) & U11-SDS2.5 & - & - & SDWS log screw (d= 0.197 in) at 13 in. o/c; 54 fasteners in 2 rows.\\
\hline
S2B & WSP – sheathing & 19/32 & Y & 1-1/2 & 10d & 3 & 1860 & 6 & (2) & U11-SDS2.5 & - & - & SDWS log screw (d= 0.197 in) at 13 in. o/c; 54 fasteners in 2 rows.\\
\hline
S1A & WSP – sheathing & 19/32 & Y & 1-1/2 & 10d & 2 & 2435 & 11 & (4) & 19 & 10 & 36 & SDWS log screw (d= 0.197 in) at 8 in. o/c; 76 fasteners in 2 rows.\\
\hline
S1B & WSP – sheathing & 19/32 & Y & 1-1/2 & 10d & 2 & 2435 & 11 & (4) & 19 & 10 & 36 & SDWS log screw (d= 0.197 in) at 8 in. o/c; 76 fasteners in 2 rows.\\
\hline
  \end{longtable}
  \end{tiny}
  \end{center}

\subsubsection{North facade shear walls}
The shear walls of the North facade are those denoted by the letter ``N'' in figures \ref{fg_3rd_floor_key_plan} to \ref{fg_1st_floor_key_plan}. The wind load on each floor per unit length is as follows:

\begin{center}
  \begin{tabular}{|l|c|}
    \hline
    \textbf{floor} & \textbf{wind force}\\
    & $(kN/m)$\\
    \hline
    roof & 2.34 \\
    third & 1.67 \\
    second & 1.71 \\
    \hline
  \end{tabular}
\end{center}

\noindent The shear values obtained for each wall are as follows:

\begin{center}
  \begin{tabular}{|l|c|c|c|c|}
    \hline
    \textbf{floor} & \multicolumn{4}{c|}{\textbf{shear force} $(kN)$}\\
                   & NA & NB & NC & ND \\
    \hline
    roof & 44.84 & 11.72 & 25.01 & 45.63 \\
    third & 31.91 & 8.34 & 17.79 & 32.47 \\
    second & 32.64 & 8.53 & 18.20 & 33.22 \\
    \hline
  \end{tabular}
\end{center}  

\noindent And the cumulated values are:

\begin{center}
  \begin{tabular}{|l|c|c|c|c|}
    \hline
    \textbf{floor} & \multicolumn{4}{c|}{\textbf{shear force} $(kN)$}\\
                   & NA & NB & NC & ND \\
    \hline
    roof & 44.84 & 11.72 & 25.01 & 45.63 \\
    third & 76.75 & 20.06 & 42.80 & 78.11 \\
    second & 109.39 & 28.59 & 61.01 & 111.33 \\
    \hline
  \end{tabular}
\end{center}  

\noindent leading to the following dimensions:
\begin{center}
  \begin{tiny}
    \begin{longtable}{|c|p{1.25cm}|c|c|c|c|c|c|c|c|c|c|c|p{2cm}|}
    \hline
    \multicolumn{11}{|c|}{}& \multicolumn{2}{p{1.1cm}|}{Bottom plate attachment (foundation)} & Bottom plate attachment (floor to floor)\\
    \hline
    \rotatebox[origin=c]{90}{Shear wall} & \rotatebox[origin=c]{90}{Sheathing material} & \rotatebox[origin=c]{90}{Panel thickness} & \rotatebox[origin=c]{90}{Blocking} & \rotatebox[origin=c]{90}{Minimum fastener penetration} & \rotatebox[origin=c]{90}{Fastener type and size} & \rotatebox[origin=c]{90}{Panel edge fastener spacing}  & \rotatebox[origin=c]{90}{Nominal unit shear capacity $v_w$} & \rotatebox[origin=c]{90}{Hold-down anchor capacity} & \rotatebox[origin=c]{90}{Hold-down studs} & \rotatebox[origin=c]{90}{Hold-down anchor type} & \rotatebox[origin=c]{90}{Number of bolts} & \rotatebox[origin=c]{90}{Bolt spacing}  & \\
\hline
ID &  & (in) &  & (in) &  & (in) & (plf) & (kip) & & HD & & (in) & \\
N3A & WSP – sheathing & 3/8 & Y & 1-3/8 & 8d & 4 & 840 & 2 & (1) & U4-SDS2.5 & - & - & wood screws 20 (d= 0.32 in) at 25 in. o/c; 30 fasteners in 2 rows.\\
\hline
N3B & WSP – sheathing & 3/8 & N & 1-3/8 & 8d & 6 & 560 & - & - &  & - & - & 16d (d= 0.268 in) nails at 24 in. o/c; 16 fasteners in 1 row.\\
\hline
N3C & WSP – sheathing & 3/8 & N & 1-3/8 & 8d & 6 & 560 & - & - &  & - & - & 16d (d= 0.268 in) nails at 21 in. o/c; 35 fasteners in 2 rows.\\
\hline
N3D & WSP – sheathing & 3/8 & Y & 1-3/8 & 8d & 4 & 840 & 2 & (1) & U4-SDS2.5 & - & - & wood screws 20 (d= 0.32 in) at 25 in. o/c; 30 fasteners in 2 rows.\\
\hline
N2A & WSP – sheathing & 19/32 & Y & 1-1/2 & 10d & 4 & 1430 & 4 & (2) & U4-SDS2.5 & - & - & wood screws 20 (d= 0.32 in) at 14 in. o/c; 52 fasteners in 2 rows.\\
\hline
N2B & WSP – sheathing & 19/32 & Y & 1-1/2 & 10d & 6 & 950 & - & - &  & - & - & 16d (d= 0.268 in) nails at 13 in. o/c; 28 fasteners in 1 row.\\
\hline
N2C & WSP – sheathing & 19/32 & Y & 1-1/2 & 10d & 6 & 950 & 1 & (1) & U4-SDS2.5 & - & - & 16d (d= 0.268 in) nails at 12 in. o/c; 59 fasteners in 2 rows.\\
\hline
N2D & WSP – sheathing & 19/32 & Y & 1-1/2 & 10d & 4 & 1430 & 4 & (2) & U4-SDS2.5 & - & - & wood screws 20 (d= 0.32 in) at 14 in. o/c; 52 fasteners in 2 rows.\\
\hline
N1A & WSP – sheathing & 19/32 & Y & 1-1/2 & 10d & 3 & 1860 & 7 & (3) & U11-SDS2.5 & 10 & 36 & SDWS log screw (d= 0.197 in) at 12 in. o/c; 58 fasteners in 2 rows.\\
\hline
N1B & WSP – sheathing & 19/32 & Y & 1-1/2 & 10d & 6 & 950 & - & - &  & 11 & 36 & 16d (d= 0.268 in) nails at 19 in. o/c; 39 fasteners in 2 rows.\\
\hline
N1C & WSP – sheathing & 19/32 & Y & 1-1/2 & 10d & 6 & 950 & 3 & (1) & U4-SDS2.5 & 11 & 36 & wood screws 20 (d= 0.32 in) at 19 in. o/c; 40 fasteners in 2 rows.\\
\hline
N1D & WSP – sheathing & 19/32 & Y & 1-1/2 & 10d & 3 & 1860 & 7 & (3) & U11-SDS2.5 & 10 & 36 & SDWS log screw (d= 0.197 in) at 12 in. o/c; 60 fasteners in 2 rows.\\
\hline
  \end{longtable}
  \end{tiny}
  \end{center}

\begin{figure}
  \begin{center}
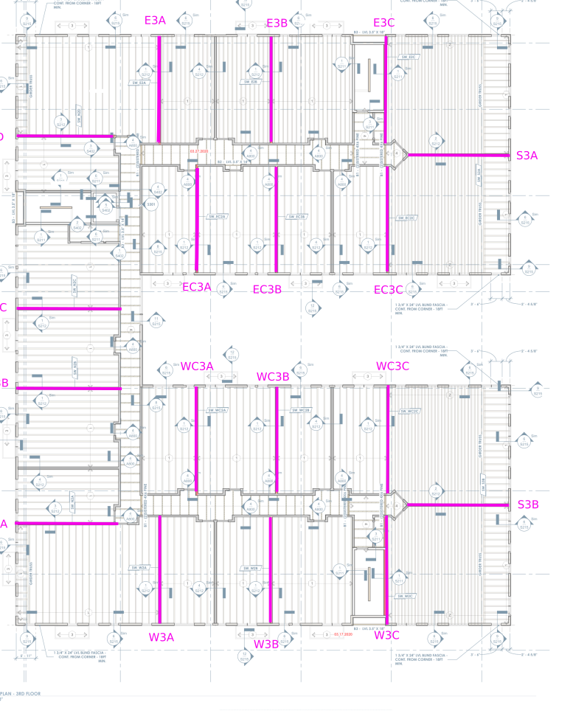
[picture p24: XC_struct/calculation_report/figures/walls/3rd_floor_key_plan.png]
  
  \end{center}
  \caption{Shear walls on the third floor.}\label{fg_3rd_floor_key_plan}
\end{figure}

\begin{figure}
  \begin{center}
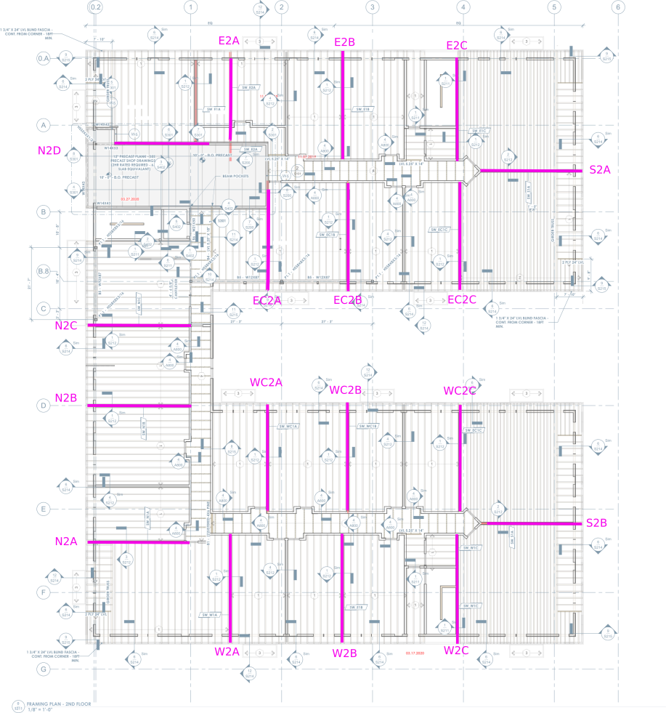
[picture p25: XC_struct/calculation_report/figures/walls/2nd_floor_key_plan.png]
  
  \end{center}
  \caption{Shear walls on the second floor.}\label{fg_2nd_floor_key_plan}
\end{figure}

\begin{figure}
  \begin{center}
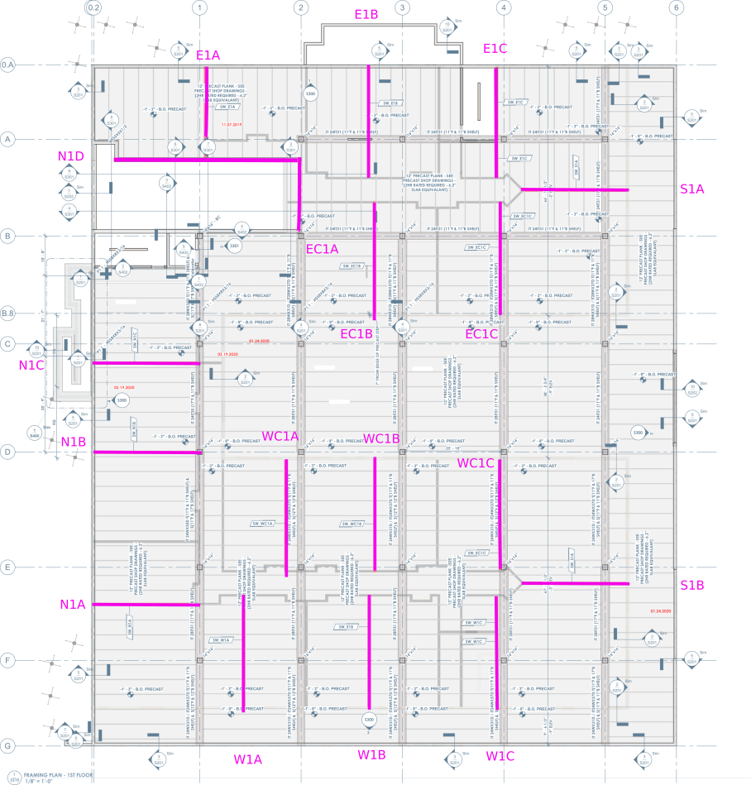
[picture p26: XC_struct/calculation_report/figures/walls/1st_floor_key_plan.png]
  
  \end{center}
  \caption{Shear walls on the first floor.}\label{fg_1st_floor_key_plan}
\end{figure}

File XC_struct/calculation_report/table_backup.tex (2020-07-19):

\begin{center}
  \begin{tiny}
  \begin{longtable}{|l|p{1.5cm}|c|c|c|c|c|c|c|c|c|p{3cm}|}
    \hline
    \multicolumn{9}{|c|}{}& \multicolumn{2}{p{1.1cm}|}{Bottom plate attachment (foundation)} &  Bottom plate attachment (floor to floor)\\
    \hline
    \rotatebox[origin=c]{90}{Shear wall} & \rotatebox[origin=c]{90}{Sheathing material} & \rotatebox[origin=c]{90}{Panel thickness} & \rotatebox[origin=c]{90}{Blocking} & \rotatebox[origin=c]{90}{Minimum fastener penetration} & \rotatebox[origin=c]{90}{Fastener type and size} & \rotatebox[origin=c]{90}{Panel edge fastener spacing}  & \rotatebox[origin=c]{90}{Nominal unit shear capacity vw} & \rotatebox[origin=c]{90}{Hold-down anchor capacity} & \rotatebox[origin=c]{90}{Number of bolts} & \rotatebox[origin=c]{90}{Bolt spacing}  & \\
\hline
ID &  & (in) &  & (in) &  & (in) & (plf) & (kip) &  & (in) & \\
\hline
SW\_N3A & Wood structural panels – sheathing & 3/8 & YES & 1-3/8 & 8d & 4 & 840 & 2 & - & - & wood screws 20 (d= 0.32 in) at 25 in. o/c; 30 fasteners in 2 rows.\\
\hline
SW\_N3B & Wood structural panels – sheathing & 3/8 & NO & 1-3/8 & 8d & 6 & 560 & - & - & - & 16d (d= 0.268 in) nails at 24 in. o/c; 16 fasteners in 1 row.\\
\hline
SW\_N3C & Wood structural panels – sheathing & 3/8 & NO & 1-3/8 & 8d & 6 & 560 & - & - & - & 16d (d= 0.268 in) nails at 21 in. o/c; 35 fasteners in 2 rows.\\
\hline
SW\_N3D & Wood structural panels – sheathing & 3/8 & YES & 1-3/8 & 8d & 4 & 840 & 2 & - & - & wood screws 20 (d= 0.32 in) at 25 in. o/c; 30 fasteners in 2 rows.\\
\hline
SW\_N2A & Wood structural panels – sheathing & 19/32 & YES & 1-1/2 & 10d & 4 & 1430 & 4 & - & - & wood screws 20 (d= 0.32 in) at 14 in. o/c; 52 fasteners in 2 rows.\\
\hline
SW\_N2B & Wood structural panels – sheathing & 19/32 & YES & 1-1/2 & 10d & 6 & 950 & - & - & - & 16d (d= 0.268 in) nails at 13 in. o/c; 28 fasteners in 1 row.\\
\hline
SW\_N2C & Wood structural panels – sheathing & 19/32 & YES & 1-1/2 & 10d & 6 & 950 & 1 & - & - & 16d (d= 0.268 in) nails at 12 in. o/c; 59 fasteners in 2 rows.\\
\hline
SW\_N2D & Wood structural panels – sheathing & 19/32 & YES & 1-1/2 & 10d & 4 & 1430 & 4 & - & - & wood screws 20 (d= 0.32 in) at 14 in. o/c; 52 fasteners in 2 rows.\\
\hline
SW\_N1A & Wood structural panels – sheathing & 19/32 & YES & 1-1/2 & 10d & 3 & 1860 & 7 & 10 & 36 & SDWS log screw (d= 0.197 in) at 12 in. o/c; 58 fasteners in 2 rows.\\
\hline
SW\_N1B & Wood structural panels – sheathing & 19/32 & YES & 1-1/2 & 10d & 6 & 950 & - & 11 & 36 & 16d (d= 0.268 in) nails at 19 in. o/c; 39 fasteners in 2 rows.\\
\hline
SW\_N1C & Wood structural panels – sheathing & 19/32 & YES & 1-1/2 & 10d & 6 & 950 & 3 & 11 & 36 & wood screws 20 (d= 0.32 in) at 19 in. o/c; 40 fasteners in 2 rows.\\
\hline
SW\_N1D & Wood structural panels – sheathing & 19/32 & YES & 1-1/2 & 10d & 3 & 1860 & 7 & 10 & 36 & SDWS log screw (d= 0.197 in) at 12 in. o/c; 60 fasteners in 2 rows.\\
\hline
SW\_S3A & Wood structural panels – sheathing & 19/32 & YES & 1-1/2 & 10d & 6 & 950 & 2 & - & - & wood screws 20 (d= 0.32 in) at 21 in. o/c; 36 fasteners in 2 rows.\\
\hline
SW\_S3B & Wood structural panels – sheathing & 19/32 & YES & 1-1/2 & 10d & 6 & 950 & 2 & - & - & wood screws 20 (d= 0.32 in) at 21 in. o/c; 36 fasteners in 2 rows.\\
\hline
SW\_S2A & Wood structural panels – sheathing & 19/32 & YES & 1-1/2 & 10d & 3 & 1860 & 6 & - & - & SDWS log screw (d= 0.197 in) at 13 in. o/c; 54 fasteners in 2 rows.\\
\hline
SW\_S2B & Wood structural panels – sheathing & 19/32 & YES & 1-1/2 & 10d & 3 & 1860 & 6 & - & - & SDWS log screw (d= 0.197 in) at 13 in. o/c; 54 fasteners in 2 rows.\\
\hline
SW\_S1A & Wood structural panels – sheathing & 19/32 & YES & 1-1/2 & 10d & 2 & 2435 & 11 & 10 & 36 & SDWS log screw (d= 0.197 in) at 8 in. o/c; 76 fasteners in 2 rows.\\
\hline
SW\_S1B & Wood structural panels – sheathing & 19/32 & YES & 1-1/2 & 10d & 2 & 2435 & 11 & 10 & 36 & SDWS log screw (d= 0.197 in) at 8 in. o/c; 76 fasteners in 2 rows.\\
\hline
SW\_E3A & Wood structural panels – sheathing & 19/32 & YES & 1-1/2 & 10d & 4 & 1430 & 3 & - & - & wood screws 20 (d= 0.32 in) at 16 in. o/c; 46 fasteners in 2 rows.\\
\hline
SW\_E3B & Wood structural panels – sheathing & 3/8 & NO & 1-3/8 & 8d & 6 & 560 & - & - & - & 16d (d= 0.268 in) nails at 12 in. o/c; 30 fasteners in 1 row.\\
\hline
SW\_E3C & Wood structural panels – sheathing & 19/32 & YES & 1-1/2 & 10d & 4 & 1430 & 6 & - & - & SDWS log screw (d= 0.197 in) at 15 in. o/c; 32 fasteners in 2 rows.\\
\hline
SW\_E2A & Wood structural panels – sheathing & 19/32 & YES & 1-1/2 & 10d & 3 & 1860 & 7 & - & - & SDWS log screw (d= 0.197 in) at 11 in. o/c; 64 fasteners in 2 rows.\\
\hline
SW\_E2B & Wood structural panels – sheathing & 3/8 & NO & 1-3/8 & 8d & 6 & 560 & 1 & - & - & 16d (d= 0.268 in) nails at 14 in. o/c; 51 fasteners in 2 rows.\\
\hline
SW\_E2C & Wood structural panels – sheathing & 19/32 & YES & 1-1/2 & 10d & 2 & 2435 & 11 & - & - & SDWS log screw (d= 0.197 in) at 9 in. o/c; 54 fasteners in 2 rows.\\
\hline
SW\_E1A & Wood structural panels – sheathing & 19/32 & YES & 1-1/2 & 10d & 2 & 2435 & 13 & 7 & 36 & SDWS log screw (d= 0.197 in) at 7 in. o/c; 64 fasteners in 2 rows.\\
\hline
SW\_E1B & Wood structural panels – sheathing & 3/8 & NO & 1-3/8 & 8d & 6 & 560 & - & 11 & 36 & 16d (d= 0.268 in) nails at 32 in. o/c; 12 fasteners in 1 row.\\
\hline
SW\_E1C & Wood structural panels – sheathing & 19/32 & YES & 1-1/2 & 10d & 2 & 2435 & 9 & 11 & 36 & SDWS log screw (d= 0.197 in) at 10 in. o/c; 72 fasteners in 2 rows.\\
\hline
SW\_W3A & Wood structural panels – sheathing & 19/32 & YES & 1-1/2 & 10d & 4 & 1430 & 3 & - & - & wood screws 20 (d= 0.32 in) at 16 in. o/c; 46 fasteners in 2 rows.\\
\hline
SW\_W3B & Wood structural panels – sheathing & 3/8 & NO & 1-3/8 & 8d & 6 & 560 & - & - & - & 16d (d= 0.268 in) nails at 12 in. o/c; 30 fasteners in 1 row.\\
\hline
SW\_W3C & Wood structural panels – sheathing & 19/32 & YES & 1-1/2 & 10d & 4 & 1430 & 6 & - & - & SDWS log screw (d= 0.197 in) at 15 in. o/c; 32 fasteners in 2 rows.\\
\hline
SW\_W2A & Wood structural panels – sheathing & 19/32 & YES & 1-1/2 & 10d & 3 & 1860 & 7 & - & - & SDWS log screw (d= 0.197 in) at 11 in. o/c; 64 fasteners in 2 rows.\\
\hline
SW\_W2B & Wood structural panels – sheathing & 3/8 & NO & 1-3/8 & 8d & 6 & 560 & 1 & - & - & 16d (d= 0.268 in) nails at 14 in. o/c; 51 fasteners in 2 rows.\\
\hline
SW\_W2C & Wood structural panels – sheathing & 19/32 & YES & 1-1/2 & 10d & 2 & 2435 & 11 & - & - & SDWS log screw (d= 0.197 in) at 9 in. o/c; 54 fasteners in 2 rows.\\
\hline
SW\_W1A & Wood structural panels – sheathing & 19/32 & YES & 1-1/2 & 10d & 2 & 2435 & 13 & 9 & 30 & SDWS log screw (d= 0.197 in) at 7 in. o/c; 64 fasteners in 2 rows.\\
\hline
SW\_W1B & Wood structural panels – sheathing & 3/8 & NO & 1-3/8 & 8d & 6 & 560 & - & 11 & 36 & 16d (d= 0.268 in) nails at 32 in. o/c; 12 fasteners in 1 row.\\
\hline
SW\_W1C & Wood structural panels – sheathing & 19/32 & YES & 1-1/2 & 10d & 2 & 2435 & 9 & 11 & 36 & SDWS log screw (d= 0.197 in) at 10 in. o/c; 72 fasteners in 2 rows.\\
\hline
SW\_EC3A & Wood structural panels – sheathing & 19/32 & YES & 1-1/2 & 10d & 6 & 950 & 0 & - & - & 16d (d= 0.268 in) nails at 18 in. o/c; 42 fasteners in 2 rows.\\
\hline
SW\_EC3B & Wood structural panels – sheathing & 3/8 & NO & 1-3/8 & 8d & 6 & 560 & - & - & - & 16d (d= 0.268 in) nails at 60 in. o/c; 7 fasteners in 1 row.\\
\hline
SW\_EC3C & Wood structural panels – sheathing & 19/32 & YES & 1-1/2 & 10d & 6 & 950 & 3 & - & - & wood screws 20 (d= 0.32 in) at 19 in. o/c; 40 fasteners in 2 rows.\\
\hline
SW\_EC2A & Wood structural panels – sheathing & 19/32 & YES & 1-1/2 & 10d & 3 & 1860 & 2 & - & - & wood screws 20 (d= 0.32 in) at 21 in. o/c; 36 fasteners in 2 rows.\\
\hline
SW\_EC2B & Wood structural panels – sheathing & 3/8 & NO & 1-3/8 & 8d & 6 & 560 & - & - & - & 16d (d= 0.268 in) nails at 32 in. o/c; 12 fasteners in 1 row.\\
\hline
SW\_EC2C & Wood structural panels – sheathing & 19/32 & YES & 1-1/2 & 10d & 3 & 1860 & 6 & - & - & SDWS log screw (d= 0.197 in) at 12 in. o/c; 58 fasteners in 2 rows.\\
\hline
SW\_EC1A & Wood structural panels – sheathing & 19/32 & YES & 1-1/2 & 10d & 2 & 2435 & 11 & 6 & 36 & SDWS log screw (d= 0.197 in) at 9 in. o/c; 42 fasteners in 2 rows.\\
\hline
SW\_EC1B & Wood structural panels – sheathing & 3/8 & NO & 1-3/8 & 8d & 6 & 560 & - & 11 & 36 & 16d (d= 0.268 in) nails at 22 in. o/c; 17 fasteners in 1 row.\\
\hline
SW\_EC1C & Wood structural panels – sheathing & 19/32 & YES & 1-1/2 & 10d & 2 & 2435 & 11 & 11 & 36 & SDWS log screw (d= 0.197 in) at 9 in. o/c; 82 fasteners in 2 rows.\\
\hline
SW\_WC3A & Wood structural panels – sheathing & 19/32 & YES & 1-1/2 & 10d & 6 & 950 & 0 & - & - & 16d (d= 0.268 in) nails at 18 in. o/c; 42 fasteners in 2 rows.\\
\hline
SW\_WC3B & Wood structural panels – sheathing & 3/8 & NO & 1-3/8 & 8d & 0 & 560 & - & - & - & 16d (d= 0.268 in) nails at 60 in. o/c; 7 fasteners in 1 row.\\
\hline
SW\_WC3C & Wood structural panels – sheathing & 19/32 & YES & 1-1/2 & 10d & 6 & 950 & 3 & - & - & wood screws 20 (d= 0.32 in) at 19 in. o/c; 40 fasteners in 2 rows.\\
\hline
SW\_WC2A & Wood structural panels – sheathing & 19/32 & YES & 1-1/2 & 10d & 3 & 1860 & 2 & - & - & wood screws 20 (d= 0.32 in) at 21 in. o/c; 36 fasteners in 2 rows.\\
\hline
SW\_WC2B & Wood structural panels – sheathing & 3/8 & NO & 1-3/8 & 8d & 6 & 560 & - & - & - & 16d (d= 0.268 in) nails at 32 in. o/c; 12 fasteners in 1 row.\\
\hline
SW\_WC2C & Wood structural panels – sheathing & 19/32 & YES & 1-1/2 & 10d & 3 & 1860 & 6 & - & - & SDWS log screw (d= 0.197 in) at 12 in. o/c; 58 fasteners in 2 rows.\\
\hline
SW\_WC1A & Wood structural panels – sheathing & 19/32 & YES & 1-1/2 & 10d & 2 & 2435 & 11 & 6 & 36 & SDWS log screw (d= 0.197 in) at 9 in. o/c; 42 fasteners in 2 rows.\\
\hline
SW\_WC1B & Wood structural panels – sheathing & 3/8 & NO & 1-3/8 & 8d & 6 & 560 & - & 11 & 36 & 16d (d= 0.268 in) nails at 22 in. o/c; 17 fasteners in 1 row.\\
\hline
SW\_WC1C & Wood structural panels – sheathing & 19/32 & YES & 1-1/2 & 10d & 2 & 2435 & 11 & 11 & 36 & SDWS log screw (d= 0.197 in) at 9 in. o/c; 82 fasteners in 2 rows.\\
    \hline
  \end{longtable}
  \end{tiny}
  \end{center}

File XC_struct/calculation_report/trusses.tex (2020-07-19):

\subsection{Trusses}

\subsubsection{Introduction}
The calculations shown below correspond to the dimensioning of the floor structure carried out during the design of the building. These calculations have been superseded by those provided by the truss manufacturer.

\begin{figure}
  \begin{center}
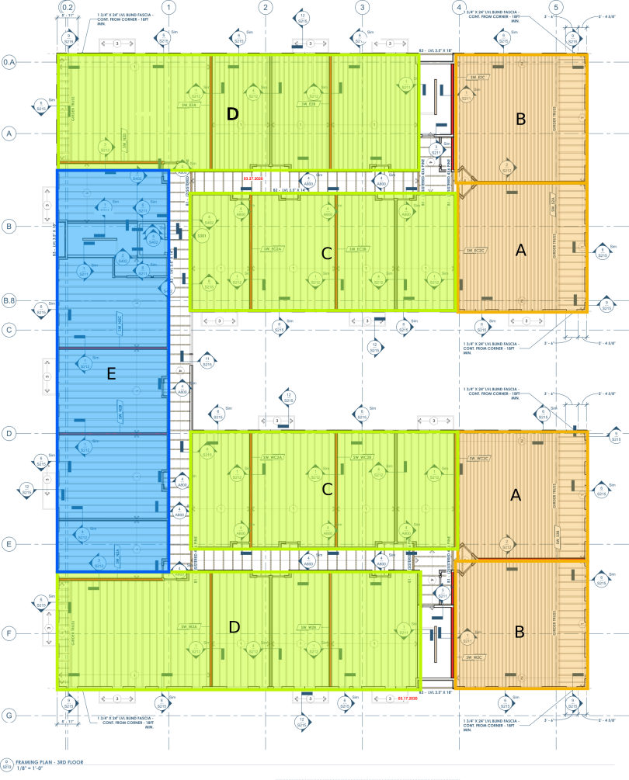
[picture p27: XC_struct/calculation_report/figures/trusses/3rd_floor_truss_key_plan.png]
  
  \end{center}
  \caption{Trusses key plan.}\label{fg_3rd_floor_truss_key_plan}
\end{figure}

\subsubsection{Trusses A and B. Roof}
The deflection results for those trusses (see figure \ref{fg_roof_truss_AB}) are as follows \footnote{The load combinations are listed in \ref{sc_load_combinations}.}:

\begin{center}
  \begin{scriptsize}
  \begin{tabular}{|l|c|c|c|c|c|c|}
    \hline
    \textbf{Load} & \textbf{truss} & \multicolumn{2}{c|}{\textbf{deflection}} & \textbf{truss} & \multicolumn{2}{c|}{\textbf{deflection}} \\
    \hline
EQ1608 & roof(A): & -1.94 mm & (L/5782; L= 11.22 m) & roof(B): &-1.12 mm & (L/9586; L= 10.77 m) \\
EQ1609 & roof(A): & -5.63 mm & (L/1994; L= 11.22 m) & roof(B): & -3.82 mm & (L/2819; L= 10.77 m) \\
EQ1610 & roof(A): & -9.66 mm & (L/1161; L= 11.22 m) & roof(B): & -6.76 mm & (L/1591; L= 10.77 m) \\
EQ1611 & roof(A): & -10.49 mm & (L/1069; L= 11.22 m) & roof(B): & -7.38 mm & (L/1459; L= 10.77 m) \\
EQ1612 & roof(A): & 0.99 mm & (L/11391; L= 11.22 m) & roof(B): & 1.02 mm & (L/10598; L= 10.77 m) \\
EQ1613 & roof(A): & -8.30 mm & (L/1352; L= 11.22 m) & roof(B): & -5.77 mm & (L/1865; L= 10.77 m) \\
EQ1615 & roof(A): & 1.76 mm & (L/6370; L= 11.22 m) & roof(B): & 1.47 mm & (L/7348; L= 10.77 m) \\
LIVE & roof(A): & -3.69 mm & (L/3044; L= 11.22 m) & roof(B): & -2.69 mm & (L/3995; L= 10.77 m) \\
\hline
  \end{tabular}
  \end{scriptsize}
\end{center}

\noindent The truss depth is allways greater than 24 inches due to the geometry of the roof. The spacing of the trusses is 24 inches.

\begin{align}
\Delta_{LL,A} &= 3.69\ mm= \frac{L}{3044} < \frac{L}{540} \implies OK \\
\Delta_{LL,B} &= 2.69\ mm= \frac{L}{3995} < \frac{L}{540} \implies OK \\
\Delta_{TL,A} &= 10.49\ mm= \frac{L}{1069} < \frac{L}{360} \implies OK \\
\Delta_{TL,B} &= 7.38\ mm= \frac{L}{1459} < \frac{L}{360} \implies OK
\end{align}

\begin{figure}
  \begin{center}
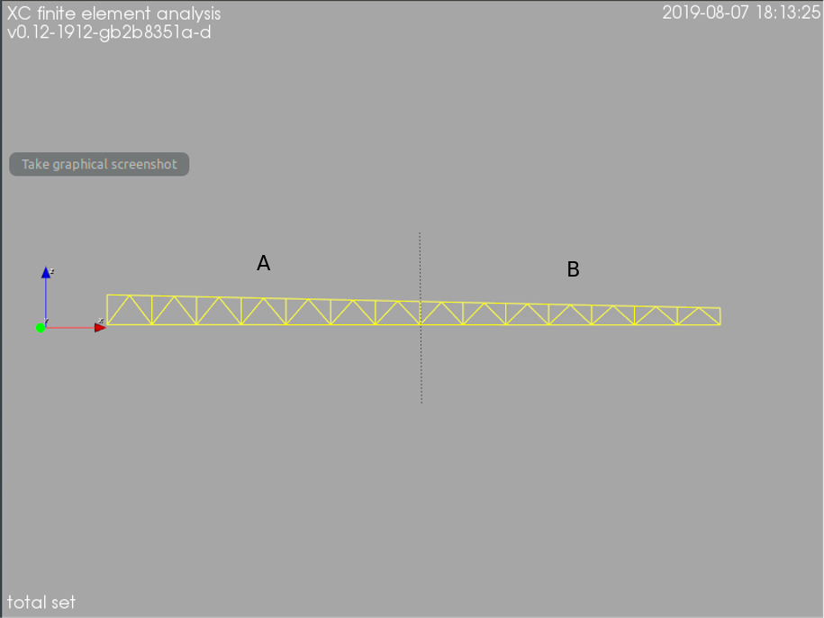
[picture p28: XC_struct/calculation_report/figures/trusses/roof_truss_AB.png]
  
  \end{center}
  \caption{Roof trusses at zones A and B (see key plan in figure \ref{fg_3rd_floor_truss_key_plan}).}\label{fg_roof_truss_AB}
\end{figure}

\subsubsection{Trusses A and B. Third floor}
The deflection results for those trusses (see figure \ref{fg_floor_truss_AB}) are as follows:

\begin{center}
  \begin{scriptsize}
  \begin{tabular}{|l|c|c|c|c|c|c|}
    \hline
    \textbf{Load} & \textbf{truss} & \multicolumn{2}{c|}{\textbf{deflection}} & \textbf{truss} & \multicolumn{2}{c|}{\textbf{deflection}} \\
    \hline
EQ1608 & A & -9.14 mm & (L/1228; L= 11.22 m)  & B & -7.75 mm & (L/1389; L= 10.77 m) \\
EQ1609 & A & -26.45 mm & (L/424; L= 11.22 m) & B & -22.46 mm & (L/479; L= 10.77 m) \\
EQ1610 & A & -9.13 mm & (L/1228; L= 11.22 m) & B & -7.74 mm & (L/1389; L= 10.77 m) \\
EQ1611 & A & -22.12 mm & (L/507; L= 11.22 m) & B & -18.78 mm & (L/573; L= 10.77 m) \\
EQ1612 & A & -9.14 mm & (L/1228; L= 11.22 m) & B & -7.75 mm & (L/1389; L= 10.77 m) \\
EQ1613 & A & -22.12 mm & (L/507; L= 11.22 m) & B & -18.78 mm & (L/573; L= 10.77 m) \\
EQ1615 & A & -5.48 mm & (L/2047; L= 11.22 m) & B & -4.65 mm & (L/2315; L= 10.77 m) \\
LIVE & A & -17.32 mm & (L/648; L= 11.22 m) & B & -14.71 mm & (L/731; L= 10.77 m) \\
\hline
  \end{tabular}
  \end{scriptsize}
\end{center}

\noindent The truss depth is 24 inches and the spacing of the trusses is 12 inches.

\begin{align}
\Delta_{LL,A} &= 17.32\ mm= \frac{L}{648} < \frac{L}{540} \implies OK \\
\Delta_{LL,B} &= 14.71\ mm= \frac{L}{731} < \frac{L}{540} \implies OK \\
\Delta_{TL,A} &= 26.45\ mm= \frac{L}{424} < \frac{L}{360} \implies OK \\
\Delta_{TL,B} &= 22.46\ mm= \frac{L}{479} < \frac{L}{360} \implies OK
\end{align}

\begin{figure}
  \begin{center}
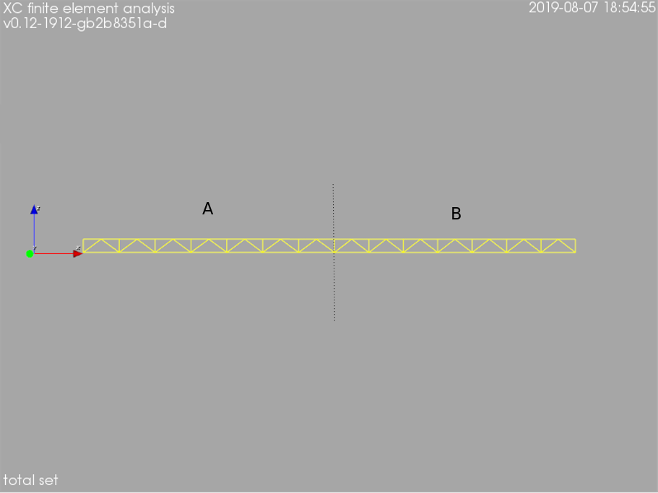
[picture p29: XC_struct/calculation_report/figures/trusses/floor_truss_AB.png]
  
  \end{center}
  \caption{Third floor trusses at zones A and B (see key plan in figure \ref{fg_3rd_floor_truss_key_plan}).}\label{fg_floor_truss_AB}
\end{figure}

\subsubsection{Trusses A and B. Second floor}
The deflection results for those trusses (see figure \ref{fg_2nd_floor_truss_AB}) are as follows:

\begin{center}
  \begin{scriptsize}
  \begin{tabular}{|l|c|c|c|c|c|c|}
    \hline
    \textbf{Load} & \textbf{truss} & \multicolumn{2}{c|}{\textbf{deflection}} & \textbf{truss} & \multicolumn{2}{c|}{\textbf{deflection}} \\
    \hline
EQ1608& A &-8.13  mm & (L/1282; L= 10.42 m) & B &  -6.81  mm & (L/1464; L= 9.97 m)\\
EQ1609& A &-23.51  mm & (L/443; L= 10.42 m) & B &  -19.71  mm & (L/505; L= 9.97 m)\\
EQ1610& A &-8.13  mm & (L/1282; L= 10.42 m) & B &  -6.81  mm & (L/1464; L= 9.97 m)\\
EQ1611& A &-19.66  mm & (L/530; L= 10.42 m) & B &  -16.48  mm & (L/604; L= 9.97 m)\\
EQ1612& A &-8.13  mm & (L/1282; L= 10.42 m) & B &  -6.81  mm & (L/1464; L= 9.97 m)\\
EQ1613& A &-19.66  mm & (L/530; L= 10.42 m) & B &  -16.48  mm & (L/604; L= 9.97 m)\\
EQ1615& A &-4.88  mm & (L/2136; L= 10.42 m) & B &  -4.08  mm & (L/2440; L= 9.97 m)\\
LIVE& A &-15.38  mm & (L/677; L= 10.42 m) & B & -12.90  mm & (L/772; L= 9.97 m)\\
\hline
  \end{tabular}
  \end{scriptsize}
\end{center}

\noindent The truss depth is 22 inches and the spacing of the trusses is 12 inches.

\begin{align}
\Delta_{LL,A} &= 15.38\ mm= \frac{L}{677} < \frac{L}{540} \implies OK \\
\Delta_{LL,B} &= 12.90\ mm= \frac{L}{772} < \frac{L}{540} \implies OK \\
\Delta_{TL,A} &= 23.51\ mm= \frac{L}{443} < \frac{L}{360} \implies OK \\
\Delta_{TL,B} &= 19.71\ mm= \frac{L}{505} < \frac{L}{360} \implies OK
\end{align}

\begin{figure}
  \begin{center}
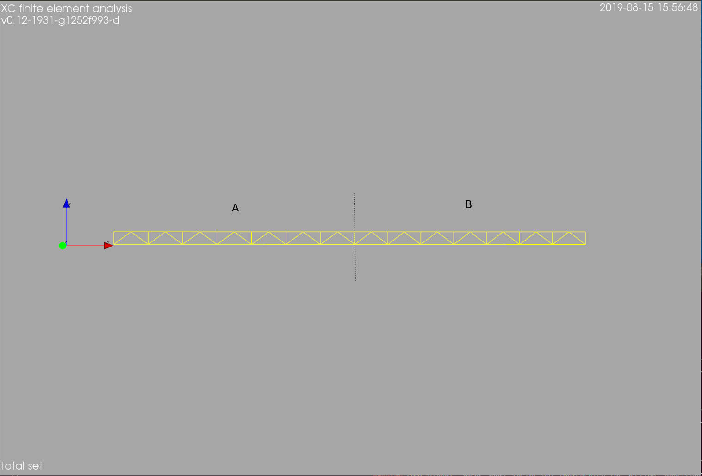
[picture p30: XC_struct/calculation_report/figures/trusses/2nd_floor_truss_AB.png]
  
  \end{center}
  \caption{Second floor trusses at zones A and B (see key plan in figure \ref{fg_3rd_floor_truss_key_plan}).}\label{fg_2nd_floor_truss_AB}
\end{figure}

\subsubsection{Trusses C and D. Roof}
The deflection results for those trusses (see figure \ref{fg_roof_truss_CD}) are as follows:

\begin{center}
  \begin{scriptsize}
  \begin{tabular}{|l|c|c|c|c|c|c|}
    \hline
    \textbf{Load} & \textbf{truss} & \multicolumn{2}{c|}{\textbf{deflection}} & \textbf{truss} & \multicolumn{2}{c|}{\textbf{deflection}} \\
    \hline
EQ1608 & roof(C) & -2.92 mm & (L/3420; L= 10.00 m) & roof(D) & -5.24 mm & (L/1822; L= 9.55 m) \\
EQ1609 & roof(C) & -7.42 mm & (L/1347; L= 10.00 m) & roof(D) & -11.87 mm & (L/803; L= 9.55 m) \\
EQ1610 & roof(C) & -12.34 mm & (L/810; L= 10.00 m) & roof(D) & -19.13 mm & (L/498; L= 9.55 m) \\
EQ1611 & roof(C) & -13.36 mm & (L/748; L= 10.00 m) & roof(D) & -20.64 mm & (L/462; L= 9.55 m) \\
EQ1612 & roof(C) & 0.64 mm & (L/15512; L= 10.00 m) & roof(D) & 0.03 mm & (L/323264; L= 9.55 m) \\
EQ1613 & roof(C) & -10.68 mm & (L/936; L= 10.00 m) & roof(D) & -16.69 mm & (L/572; L= 9.55 m) \\
EQ1615 & roof(C) & 1.81 mm & (L/5512; L= 10.00 m) & roof(D) & 2.12 mm & (L/4493; L= 9.55 m) \\
LIVE & roof(C) & -4.50 mm & (L/2224; L= 10.00 m) & roof(D) & -6.64 mm & (L/1438; L= 9.55 m) \\
\hline
  \end{tabular}
  \end{scriptsize}
\end{center}

\noindent The truss depth is allways greater than 24 inches due to the geometry of the roof. The spacing of the trusses is 24 inches. The spacing of the joists is 32 inches. 

\begin{align}
\Delta_{LL,C} &= 4.50\ mm= \frac{L}{2224} < \frac{L}{540} \implies OK \\
\Delta_{LL,D} &= 6.64\ mm= \frac{L}{772} < \frac{L}{540} \implies OK \\
\Delta_{TL,C} &= 13.36\ mm= \frac{L}{748} < \frac{L}{360} \implies OK \\
\Delta_{TL,D} &= 20.64\ mm= \frac{L}{462} < \frac{L}{360} \implies OK
\end{align}

\begin{figure}
  \begin{center}
  
  \end{center}
  \caption{Roof trusses at zones C and D (see key plan in figure \ref{fg_3rd_floor_truss_key_plan}).}\label{fg_roof_truss_CD}
\end{figure}

\subsubsection{Trusses C and D. Third floor}
The deflection results for those trusses (see figure \ref{fg_floor_truss_CD}) are as follows:

\begin{center}
  \begin{scriptsize}
  \begin{tabular}{|l|c|c|c|c|c|c|}
    \hline
    \textbf{Load} & \textbf{truss} & \multicolumn{2}{c|}{\textbf{deflection}} & \textbf{truss} & \multicolumn{2}{c|}{\textbf{deflection}} \\
    \hline
EQ1608 & C & -10.00 mm & (L/982; L= 9.82 m) & D & -8.93 mm & (L/1048; L= 9.37 m) \\
EQ1609 & C & -26.93 mm & (L/364; L= 9.82 m) & D & -24.04 mm & (L/389; L= 9.37 m) \\
EQ1610 & C & -10.00 mm & (L/982; L= 9.82 m) & D & -8.93 mm & (L/1048; L= 9.37 m) \\
EQ1611 & C & -22.70 mm & (L/432; L= 9.82 m) & D & -20.26 mm & (L/462; L= 9.37 m) \\
EQ1612 & C & -10.00 mm & (L/982; L= 9.82 m) & D & -8.93 mm & (L/1048; L= 9.37 m) \\
EQ1613 & C & -22.70 mm & (L/432; L= 9.82 m) & D & -20.26 mm & (L/462; L= 9.37 m) \\
EQ1615 & C & -6.00 mm & (L/1636; L= 9.82 m) & D & -5.36 mm & (L/1747; L= 9.37 m) \\
LIVE & C & -16.93 mm & (L/580; L= 9.82 m) & D & -15.11 mm & (L/620; L= 9.37 m) \\
\hline
  \end{tabular}
  \end{scriptsize}
\end{center}

\noindent The truss depths are 24 inches for the C truss 22 inches for the D truss. The spacing of the trusses is 24 inches. The spacing of the joists is 32 inches. 

\begin{align}
\Delta_{LL,C} &= 16.93\ mm= \frac{L}{580} < \frac{L}{540} \implies OK \\
\Delta_{LL,D} &= 15.11\ mm= \frac{L}{620} < \frac{L}{540} \implies OK \\
\Delta_{TL,C} &= 26.93\ mm= \frac{L}{364} < \frac{L}{360} \implies OK \\
\Delta_{TL,D} &= 24.04\ mm= \frac{L}{389} < \frac{L}{360} \implies OK
\end{align}

\begin{figure}
  \begin{center}
  
  \end{center}
  \caption{Third floor trusses at zones C and D (see key plan in figure \ref{fg_3rd_floor_truss_key_plan}).}\label{fg_floor_truss_CD}
\end{figure}

\subsubsection{Trusses C and D. Second floor}
The deflection results for those trusses (see figure \ref{fg_2nd_floor_truss_CD}) are as follows:

\begin{center}
  \begin{scriptsize}
  \begin{tabular}{|l|c|c|c|c|c|c|}
    \hline
    \textbf{Load} & \textbf{truss} & \multicolumn{2}{c|}{\textbf{deflection}} & \textbf{truss} & \multicolumn{2}{c|}{\textbf{deflection}} \\
    \hline
EQ1608& C &-8.43  mm & (L/1070; L= 9.02 m) & D & -9.01  mm & (L/1039; L= 9.37 m)\\
EQ1609& C &-22.70  mm & (L/397; L= 9.02 m) & D & -24.24  mm & (L/386; L= 9.37 m)\\
EQ1610& C &-8.43  mm & (L/1070; L= 9.02 m) & D & -9.01  mm & (L/1039; L= 9.37 m)\\
EQ1611& C &-19.14  mm & (L/471; L= 9.02 m) & D & -20.43  mm & (L/458; L= 9.37 m)\\
EQ1612& C &-8.43  mm & (L/1070; L= 9.02 m) & D & -9.01  mm & (L/1039; L= 9.37 m)\\
EQ1613& C &-19.14  mm & (L/471; L= 9.02 m) & D & -20.43  mm & (L/458; L= 9.37 m)\\
EQ1615& C &-5.06  mm & (L/1783; L= 9.02 m) & D & -5.41  mm & (L/1732; L= 9.37 m)\\
LIVE& C &-14.27  mm & (L/632; L= 9.02 m) & D & -15.23  mm & (L/614; L= 9.37 m)\\
\hline
  \end{tabular}
  \end{scriptsize}
\end{center}

\noindent The truss depths are 22 inches. The spacing of the trusses is 24 inches. The spacing of the joists is 32 inches. 

\begin{align}
\Delta_{LL,C} &= 14.27\ mm= \frac{L}{632} < \frac{L}{540} \implies OK \\
\Delta_{LL,D} &= 15.23\ mm= \frac{L}{614} < \frac{L}{540} \implies OK \\
\Delta_{TL,C} &= 22.70\ mm= \frac{L}{397} < \frac{L}{360} \implies OK \\
\Delta_{TL,D} &= 24.24\ mm= \frac{L}{386} < \frac{L}{360} \implies OK
\end{align}

\begin{figure}
  \begin{center}
  
  \end{center}
  \caption{Second floor trusses at zones C and D (see key plan in figure \ref{fg_3rd_floor_truss_key_plan}).}\label{fg_2nd_floor_truss_CD}
\end{figure}

\subsubsection{Truss E. Roof}
The deflection results for those trusses (see figure \ref{fg_roof_truss_E}) are as follows:

\begin{center}
  \begin{scriptsize}
  \begin{tabular}{|l|c|c|c|c|c|c|}
    \hline
    \textbf{Load} & \textbf{truss} & \multicolumn{2}{c|}{\textbf{deflection}} \\
    \hline
EQ1608 & 3E & -4.67 mm & (L/2025; L= 9.47 m) \\
EQ1609 & 3E & -11.56 mm & (L/819; L= 9.47 m) \\
EQ1610 & 3E & -19.09 mm & (L/496; L= 9.47 m) \\
EQ1611 & 3E & -20.65 mm & (L/458; L= 9.47 m) \\
EQ1612 & 3E & 0.79 mm & (L/11978; L= 9.47 m) \\
EQ1613 & 3E & -16.55 mm & (L/572; L= 9.47 m) \\
EQ1615 & 3E & 2.66 mm & (L/3559; L= 9.47 m) \\
LIVE & 3E & -6.89 mm & (L/1375; L= 9.47 m) \\
\hline
  \end{tabular}
  \end{scriptsize}
\end{center}

\noindent The truss depth is allways greater than 24 inches due to the geometry of the roof. The spacing of the trusses is 24 inches. The spacing of the joists is 32 inches.

\begin{align}
\Delta_{LL,E} &= 6.89\ mm= \frac{L}{1375} < \frac{L}{540} \implies OK \\
\Delta_{TL,E} &= 20.65\ mm= \frac{L}{458} < \frac{L}{360} \implies OK \\
\end{align}

\begin{figure}
  \begin{center}
  
  \end{center}
  \caption{Roof truss at zone E (see key plan in figure \ref{fg_3rd_floor_truss_key_plan}).}\label{fg_roof_truss_E}
\end{figure}

\subsubsection{Truss E. Third floor}
The deflection results for those trusses (see figure \ref{fg_floor_truss_E}) are as follows:

\begin{center}
  \begin{scriptsize}
  \begin{tabular}{|l|c|c|c|c|c|c|}
    \hline
    \textbf{Load} & \textbf{truss} & \multicolumn{2}{c|}{\textbf{deflection}} \\
    \hline
EQ1608 & 2E & -8.65 mm & (L/1095; L= 9.47 m) \\
EQ1609 & 2E & -23.30 mm & (L/406; L= 9.47 m) \\
EQ1610 & 2E & -8.65 mm & (L/1095; L= 9.47 m) \\
EQ1611 & 2E & -19.63 mm & (L/482; L= 9.47 m) \\
EQ1612 & 2E & -8.65 mm & (L/1095; L= 9.47 m) \\
EQ1613 & 2E & -19.63 mm & (L/482; L= 9.47 m) \\
EQ1615 & 2E & -5.19 mm & (L/1825; L= 9.47 m) \\
LIVE & 2E & -14.65 mm & (L/646; L= 9.47 m) \\
\hline
  \end{tabular}
  \end{scriptsize}
\end{center}

\noindent The truss depth 24 inches. The spacing of the trusses is 24 inches and the spacing of the joists is 32 inches.

\begin{align}
\Delta_{LL,E} &= 14.65\ mm= \frac{L}{646} < \frac{L}{540} \implies OK \\
\Delta_{TL,E} &= 23.30\ mm= \frac{L}{406} < \frac{L}{360} \implies OK \\
\end{align}

\begin{figure}
  \begin{center}
  
  \end{center}
  \caption{Third floor truss at zone E (see key plan in figure \ref{fg_3rd_floor_truss_key_plan}).}\label{fg_floor_truss_E}
\end{figure}

\subsubsection{Truss E. Second floor}
The deflection results for those trusses (see figure \ref{fg_2nd_floor_truss_E}) are as follows:

\begin{center}
  \begin{scriptsize}
  \begin{tabular}{|l|c|c|c|c|c|c|}
    \hline
    \textbf{Load} & \textbf{truss} & \multicolumn{2}{c|}{\textbf{deflection}} \\
    \hline
EQ1608 2E: -7.18  mm & (L/1208; L= 8.67 m)\\
EQ1609 2E: -19.34  mm & (L/448; L= 8.67 m)\\
EQ1610 2E: -7.18  mm & (L/1208; L= 8.67 m)\\
EQ1611 2E: -16.30  mm & (L/532; L= 8.67 m)\\
EQ1612 2E: -7.18  mm & (L/1208; L= 8.67 m)\\
EQ1613 2E: -16.30  mm & (L/532; L= 8.67 m)\\
EQ1615 2E: -4.31  mm & (L/2013; L= 8.67 m)\\
LIVE 2E: -12.16  mm & (L/713; L= 8.67 m)\\
\hline
  \end{tabular}
  \end{scriptsize}
\end{center}

\noindent The truss depth 22 inches. The spacing of the trusses is 24 inches and the spacing of the joists is 32 inches.

\begin{align}
\Delta_{LL,E} &= 12.16\ mm= \frac{L}{713} < \frac{L}{540} \implies OK \\
\Delta_{TL,E} &= 19.34\ mm= \frac{L}{448} < \frac{L}{360} \implies OK \\
\end{align}

\begin{figure}
  \begin{center}
  
  \end{center}
  \caption{Second floor truss at zone E (see key plan in figure \ref{fg_3rd_floor_truss_key_plan}).}\label{fg_2nd_floor_truss_E}
\end{figure}

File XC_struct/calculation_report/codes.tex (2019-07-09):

The following building and material codes were used for the design:
\begin{itemize}
\item {Building code}
  \begin{itemize}
  \item International Building Code, 2018 Edition (IBC 2018) with reference to Minimum Design Loads for Buildings and Other Structures by the American Society of Civil Engineers, 2016 Edition (ASCE 7).
    \end{itemize}
\item {Material codes}
  \begin{itemize}
  \item Reinforced Concrete: Building Code Requirements for Structural Concrete and Commentary by the American Concrete Institute, 2019 Edition (ACI 318).
    \item Masonry: Building Code Requirements and Specification for Masonry Structures and Companion Commentaries, 2013 Edition (ACI 530/530).
    \end{itemize}
\end{itemize}

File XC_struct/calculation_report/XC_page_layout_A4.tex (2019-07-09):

%%Geometría de la página.

\pagestyle{fancy}
\fancypagestyle{plain}{
\fancyhf{} %anula los valores de fancy por defecto 

\fancyfoot[LE]{page \thepage\ of \pageref{LastPage}}
%\fancyfoot[CE]{\includegraphics[height=4.5mm]{anagrama/anagrama_XC_memorias}}
\fancyfoot[RE]{\emph{rev. \revision}}

\fancyfoot[LO]{\emph{\date}}
%\fancyfoot[CO]{\includegraphics[height=4.5mm]{anagrama/anagrama_XC_memorias}}
\fancyfoot[RO]{page \thepage\ of \pageref{LastPage}}
\renewcommand{\headrulewidth}{0pt} %Dibuja una raya debajo de la cabecera
\renewcommand{\footrulewidth}{0pt}
}

\renewcommand{\headrulewidth}{0.1pt} %Dibuja una raya debajo de la cabecera
\renewcommand{\footrulewidth}{0pt}
\geometry{a4paper}
\textheight= 22cm %%Espacio vertical para el texto.
%\textwidth=16cm
\marginparwidth=0mm

\fancyhf{} %anula los valores de fancy por defecto 

\fancyhead[LE]{\textsc{\titdocum}}
%\fancyhead[RO]{\textsc{\leftmark}}
\fancyhead[RO]{\textsc{\rightmark}}

\fancyfoot[LE]{page \thepage\ of \pageref{LastPage}}
%\fancyfoot[CE]{\includegraphics[height=4.5mm]{anagrama/anagrama_XC_memorias}}
\fancyfoot[RE]{\emph{rev. \revision}}

\fancyfoot[LO]{\emph{\date}}
%\fancyfoot[CO]{\includegraphics[height=4.5mm]{anagrama/anagrama_XC_memorias}}
\fancyfoot[RO]{page \thepage\ of \pageref{LastPage}}

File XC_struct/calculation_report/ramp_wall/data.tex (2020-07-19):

%Ramp walls and steel structure bearing hollowcore 2nd floor

\subsubsection{Materials}
\begin{center}
  \begin{tabular}{|l|r|}
\hline
Concrete grade & C4000 \\
\hline
Reinforcing steel grade & ASTM A615 Gr60  \\
\hline
Structural steel & ASTM A36 \\
\hline
\end{tabular}
\end{center}

\subsubsection{Loads}

\paragraph{Earth pressure}
\begin{center}
  \begin{tabular}{|l|r|}
\hline
Internal friction angle (radians) &  0.524 \\
\hline
Coefficient of earth pressure at rest  &  0.5 \\
\hline
Mass density of the soil (kg/m3)  &  1000.0 \\
\hline
Horizontal force [N/m] due to earth pressure over East wall &  20000.0 \\
\hline
\end{tabular}
\end{center}

\paragraph{Dead load}
\begin{center}
  \begin{tabular}{|l|r|}
\hline
DL West \& East walls 2nd floor [N/m] &  36620.0 \\
\hline
DL East wall 1st floor [N/m] &  42850.0 \\
\hline
DL steel beam North facade [N/m] &  7350.0 \\
\hline
DL steel cantilever (West side) [N/m]  &  44650.0 \\
\hline
DL steel cantilever (Central) [N/m]  &  44650.0 \\
\hline
DL steel cantilever  (East side) [N/m]  &  8078.7 \\
\hline
\end{tabular}
\end{center}

\paragraph{Live load}
\begin{center}
  \begin{tabular}{|l|r|}
\hline
LL West \& East walls 2nd floor [N/m] &  33030.0 \\
\hline
LL East wall 1st floor [N/m] &  10770.0 \\
\hline
LL steel beam North facade [N/m] &  4660.0 \\
\hline
LL steel cantilever (West side) [N/m]  &  39040.0 \\
\hline
LL steel cantilever (Central) [N/m]  &  39040.0 \\
\hline
LL steel cantilever  (East side) [N/m]  &  6241.5 \\
\hline
\end{tabular}
\end{center}

\paragraph{Snow load}
\begin{center}
  \begin{tabular}{|l|r|}
\hline
SL West \& East walls 2nd floor [N/m] &  13380.0 \\
\hline
SL East wall 1st floor [N/m] &  -80.0 \\
\hline
SL steel beam North facade [N/m] &  1750.0 \\
\hline
SL steel cantilever (West side) [N/m]  &  15490.0 \\
\hline
SL steel cantilever (Central) [N/m]  &  15490.0 \\
\hline
SL steel cantilever  (East side) [N/m]  &  2716.5 \\
\hline
\end{tabular}
\end{center}

\paragraph{Wind load}
\begin{center}
  \begin{tabular}{|l|r|}
\hline
WL West \& East walls 2nd floor [N/m] (vertical) &  8460.0 \\
\hline
WL West \& East walls 2nd floor [N/m] (horizontal) &  1700.0 \\
\hline
WL East wall 1st floor [N/m]  (vertical) &  500.0 \\
\hline
\end{tabular}
\end{center}

\subsubsection{Load combination}
\begin{center}
  \begin{tabular}{|l|r|}
\hline
ELU01 & $1.4 \times DL$ \\
\hline
ELU02 & $ 1.2 \times DL +1.6 \times LL +0.5 \times SL $ \\
\hline
ELU03 & $ 1.2 \times DL +1.6 \times SL +0.5 \times WL $ \\
\hline
ELU04 & $ 1.2 \times DL +1.0 \times LL +1.0 \times WL $ \\
\hline
ELU05 & $ 0.9 \times DL +1.0 \times WL $ \\
\hline
\end{tabular}
\end{center}

\subsubsection{Structural model}
A three-dimensional elastic computer model of the ramp RC walls and cantilever steel structure on 2nd floor is analyzed using XC. The finite element model is depicted in figure \ref{rw_FE_model}. See in figures \ref{rw_D} to \ref{rw_W} load distribution for each load case.
\begin{Figure}
    \centering
    
    \captionof{figure}{Ramp walls and cantilever, mesh.}
    \label{rw_FE_model}
\end{Figure}

\begin{Figure}
    \centering
    
    \captionof{figure}{Ramp walls and cantilever, dead load over ramp wall.}
    \label{rw_D}
\end{Figure}

\begin{Figure}
    \centering
    
    \captionof{figure}{Ramp walls and cantilever, dead load over steel beams.}
\end{Figure}

\begin{Figure}
    
    \captionof{figure}{Ramp walls and cantilever, live load over ramp wall.}
\end{Figure}

\begin{Figure}
    \centering
    
    \captionof{figure}{Ramp walls and cantilever, live load over steel beams.}
\end{Figure}

\begin{Figure}
    \centering
   
    \captionof{figure}{Ramp walls and cantilever, snow load over ramp wall.}
\end{Figure}

\begin{Figure}
    \centering
    
    \captionof{figure}{Ramp walls and cantilever, snow load over steel beams.}
\end{Figure}

\begin{Figure}
    \centering
    
    \captionof{figure}{Ramp walls and cantilever, wind load over ramp wall.}
\end{Figure}

\begin{Figure}
    \centering
    
    \captionof{figure}{Ramp walls and cantilever, wind load over steel beams.}
    \label{rw_W}
\end{Figure}

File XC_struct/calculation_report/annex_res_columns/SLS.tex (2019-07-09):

\begin{figure}
\begin{center}

\caption{SLS01: 1.0*D. Columns, bending moment about local axis y [m.kN]}
\end{center}
\end{figure}

\begin{figure}
\begin{center}

\caption{SLS02\_a: 1.0*D + 1.0*Lru + Lpu + 0.3*S. Columns, bending moment about local axis y [m.kN]}
\end{center}
\end{figure}

\begin{figure}
\begin{center}

\caption{SLS02\_b: 1.0*D + 1.0*Lrs + Lps + 0.3*S. Columns, bending moment about local axis y [m.kN]}
\end{center}
\end{figure}

\begin{figure}
\begin{center}

\caption{SLS03\_a: 1.0*D + 1.0*S + 0.3*Lru + 0.3*Lpu. Columns, bending moment about local axis y [m.kN]}
\end{center}
\end{figure}

\begin{figure}
\begin{center}

\caption{SLS03\_b: 1.0*D + 1.0*S + 0.3*Lrs + 0.3*Lps. Columns, bending moment about local axis y [m.kN]}
\end{center}
\end{figure}

\begin{figure}
\begin{center}

\caption{SLS04\_a: 1.0*D + W\_WE + 1.0*Lru + Lpu. Columns, bending moment about local axis y [m.kN]}
\end{center}
\end{figure}

\begin{figure}
\begin{center}

\caption{SLS04\_b: 1.0*D + W\_NS + 1.0*Lru + Lpu. Columns, bending moment about local axis y [m.kN]}
\end{center}
\end{figure}

\begin{figure}
\begin{center}

\caption{SLS05\_a: 1.0*D + W\_WE. Columns, bending moment about local axis y [m.kN]}
\end{center}
\end{figure}

\begin{figure}
\begin{center}

\caption{SLS05\_b: 1.0*D + W\_NS. Columns, bending moment about local axis y [m.kN]}
\end{center}
\end{figure}

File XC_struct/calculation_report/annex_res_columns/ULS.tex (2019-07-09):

\begin{figure}
\begin{center}

\caption{ULS01: 1.4*D. Columns, internal axial force [kN]}
\end{center}
\end{figure}
\begin{figure}
\begin{center}

\caption{ULS01: 1.4*D. Columns, bending moment about local axis y [m.kN]}
\end{center}
\end{figure}
\begin{figure}
\begin{center}

\caption{ULS01: 1.4*D. Columns, bending moment about local axis z [m.kN]}
\end{center}
\end{figure}
\begin{figure}
\begin{center}

\caption{ULS01: 1.4*D. Columns, internal shear force in local direction y [kN]}
\end{center}
\end{figure}
\begin{figure}

\begin{center}

\caption{ULS01: 1.4*D. Columns, internal shear force in local direction z [kN]}
\end{center}
\end{figure}

\begin{figure}
\begin{center}

\caption{ULS02\_a: 1.2*D + 1.6*Lru + Lpu + 0.5*S. Columns, internal axial force [kN]}
\end{center}
\end{figure}
\begin{figure}
\begin{center}

\caption{ULS02\_a: 1.2*D + 1.6*Lru + Lpu + 0.5*S. Columns, bending moment about local axis y [m.kN]}
\end{center}
\end{figure}
\begin{figure}
\begin{center}

\caption{ULS02\_a: 1.2*D + 1.6*Lru + Lpu + 0.5*S. Columns, bending moment about local axis z [m.kN]}
\end{center}
\end{figure}
\begin{figure}
\begin{center}

\caption{ULS02\_a: 1.2*D + 1.6*Lru + Lpu + 0.5*S. Columns, internal shear force in local direction y [kN]}
\end{center}
\end{figure}
\begin{figure}
\begin{center}

\caption{ULS02\_a: 1.2*D + 1.6*Lru + Lpu + 0.5*S. Columns, internal shear force in local direction z [kN]}
\end{center}
\end{figure}

\begin{figure}
\begin{center}

\caption{ULS02\_b: 1.2*D + 1.6*Lrs + Lps + 0.5*S. Columns, internal axial force [kN]}
\end{center}
\end{figure}
\begin{figure}
\begin{center}

\caption{ULS02\_b: 1.2*D + 1.6*Lrs + Lps + 0.5*S. Columns, bending moment about local axis y [m.kN]}
\end{center}
\end{figure}
\begin{figure}
\begin{center}

\caption{ULS02\_b: 1.2*D + 1.6*Lrs + Lps + 0.5*S. Columns, bending moment about local axis z [m.kN]}
\end{center}
\end{figure}
\begin{figure}
\begin{center}

\caption{ULS02\_b: 1.2*D + 1.6*Lrs + Lps + 0.5*S. Columns, internal shear force in local direction y [kN]}
\end{center}
\end{figure}
\begin{figure}
\begin{center}

\caption{ULS02\_b: 1.2*D + 1.6*Lrs + Lps + 0.5*S. Columns, internal shear force in local direction z [kN]}
\end{center}
\end{figure}

\begin{figure}
\begin{center}

\caption{ULS03\_a: 1.2*D + 1.6*S + 0.5*Lru + Lpu. Columns, internal axial force [kN]}
\end{center}
\end{figure}
\begin{figure}
\begin{center}

\caption{ULS03\_a: 1.2*D + 1.6*S + 0.5*Lru + Lpu. Columns, bending moment about local axis y [m.kN]}
\end{center}
\end{figure}
\begin{figure}
\begin{center}

\caption{ULS03\_a: 1.2*D + 1.6*S + 0.5*Lru + Lpu. Columns, bending moment about local axis z [m.kN]}
\end{center}
\end{figure}
\begin{figure}
\begin{center}

\caption{ULS03\_a: 1.2*D + 1.6*S + 0.5*Lru + Lpu. Columns, internal shear force in local direction y [kN]}
\end{center}
\end{figure}
\begin{figure}
\begin{center}

\caption{ULS03\_a: 1.2*D + 1.6*S + 0.5*Lru + Lpu. Columns, internal shear force in local direction z [kN]}
\end{center}
\end{figure}

\begin{figure}
\begin{center}

\caption{ULS03\_b: 1.2*D + 1.6*S + 0.5*Lrs + Lps. Columns, internal axial force [kN]}
\end{center}
\end{figure}
\begin{figure}
\begin{center}

\caption{ULS03\_b: 1.2*D + 1.6*S + 0.5*Lrs + Lps. Columns, bending moment about local axis y [m.kN]}
\end{center}
\end{figure}
\begin{figure}
\begin{center}

\caption{ULS03\_b: 1.2*D + 1.6*S + 0.5*Lrs + Lps. Columns, bending moment about local axis z [m.kN]}
\end{center}
\end{figure}
\begin{figure}
\begin{center}

\caption{ULS03\_b: 1.2*D + 1.6*S + 0.5*Lrs + Lps. Columns, internal shear force in local direction y [kN]}
\end{center}
\end{figure}
\begin{figure}
\begin{center}

\caption{ULS03\_b: 1.2*D + 1.6*S + 0.5*Lrs + Lps. Columns, internal shear force in local direction z [kN]}
\end{center}
\end{figure}

\begin{figure}
\begin{center}

\caption{ULS04\_a: 1.2*D + 1.6*S + 0.5*W\_WE. Columns, internal axial force [kN]}
\end{center}
\end{figure}
\begin{figure}
\begin{center}

\caption{ULS04\_a: 1.2*D + 1.6*S + 0.5*W\_WE. Columns, bending moment about local axis y [m.kN]}
\end{center}
\end{figure}
\begin{figure}
\begin{center}

\caption{ULS04\_a: 1.2*D + 1.6*S + 0.5*W\_WE. Columns, bending moment about local axis z [m.kN]}
\end{center}
\end{figure}

\begin{figure}
\begin{center}

\caption{ULS04\_a: 1.2*D + 1.6*S + 0.5*W\_WE. Columns, internal shear force in local direction y [kN]}
\end{center}
\end{figure}
\begin{figure}
\begin{center}

\caption{ULS04\_a: 1.2*D + 1.6*S + 0.5*W\_WE. Columns, internal shear force in local direction z [kN]}
\end{center}
\end{figure}

\begin{figure}
\begin{center}

\caption{ULS04\_b: 1.2*D + 1.6*S + 0.5*W\_NS. Columns, internal axial force [kN]}
\end{center}
\end{figure}
\begin{figure}
\begin{center}

\caption{ULS04\_b: 1.2*D + 1.6*S + 0.5*W\_NS. Columns, bending moment about local axis y [m.kN]}
\end{center}
\end{figure}
\begin{figure}
\begin{center}

\caption{ULS04\_b: 1.2*D + 1.6*S + 0.5*W\_NS. Columns, bending moment about local axis z [m.kN]}
\end{center}
\end{figure}
\begin{figure}
\begin{center}

\caption{ULS04\_b: 1.2*D + 1.6*S + 0.5*W\_NS. Columns, internal shear force in local direction y [kN]}
\end{center}
\end{figure}
\begin{figure}
\begin{center}

\caption{ULS04\_b: 1.2*D + 1.6*S + 0.5*W\_NS. Columns, internal shear force in local direction z [kN]}
\end{center}
\end{figure}

\begin{figure}
\begin{center}

\caption{ULS05\_a: 1.2*D + W\_WE + 0.5*Lru + Lpu. Columns, internal axial force [kN]}
\end{center}
\end{figure}
\begin{figure}
\begin{center}

\caption{ULS05\_a: 1.2*D + W\_WE + 0.5*Lru + Lpu. Columns, bending moment about local axis y [m.kN]}
\end{center}
\end{figure}
\begin{figure}
\begin{center}

\caption{ULS05\_a: 1.2*D + W\_WE + 0.5*Lru + Lpu. Columns, bending moment about local axis z [m.kN]}
\end{center}
\end{figure}
\begin{figure}
\begin{center}

\caption{ULS05\_a: 1.2*D + W\_WE + 0.5*Lru + Lpu. Columns, internal shear force in local direction y [kN]}
\end{center}
\end{figure}
\begin{figure}
\begin{center}

\caption{ULS05\_a: 1.2*D + W\_WE + 0.5*Lru + Lpu. Columns, internal shear force in local direction z [kN]}
\end{center}
\end{figure}
% Hasta aquí bien
\clearpage
\begin{figure}
\begin{center}

\caption{ULS05\_b: 1.2*D + W\_NS + 0.5*Lru + Lpu. Columns, internal axial force [kN]}
\end{center}
\end{figure}
\begin{figure}
\begin{center}

\caption{ULS05\_b: 1.2*D + W\_NS + 0.5*Lru + Lpu. Columns, bending moment about local axis y [m.kN]}
\end{center}
\end{figure}
\begin{figure}
\begin{center}

\caption{ULS05\_b: 1.2*D + W\_NS + 0.5*Lru + Lpu. Columns, bending moment about local axis z [m.kN]}
\end{center}
\end{figure}
\begin{figure}
\begin{center}

\caption{ULS05\_b: 1.2*D + W\_NS + 0.5*Lru + Lpu. Columns, internal shear force in local direction y [kN]}
\end{center}
\end{figure}
\begin{figure}
\begin{center}

\caption{ULS05\_b: 1.2*D + W\_NS + 0.5*Lru + Lpu. Columns, internal shear force in local direction z [kN]}
\end{center}
\end{figure}

\begin{figure}
\begin{center}

\caption{ULS05\_c: 1.2*D + W\_WE + 0.5*Lrs + Lps. Columns, internal axial force [kN]}
\end{center}
\end{figure}
\begin{figure}
\begin{center}

\caption{ULS05\_c: 1.2*D + W\_WE + 0.5*Lrs + Lps. Columns, bending moment about local axis y [m.kN]}
\end{center}
\end{figure}
\begin{figure}
\begin{center}

\caption{ULS05\_c: 1.2*D + W\_WE + 0.5*Lrs + Lps. Columns, bending moment about local axis z [m.kN]}
\end{center}
\end{figure}
\begin{figure}
\begin{center}

\caption{ULS05\_c: 1.2*D + W\_WE + 0.5*Lrs + Lps. Columns, internal shear force in local direction y [kN]}
\end{center}
\end{figure}
\begin{figure}
\begin{center}

\caption{ULS05\_c: 1.2*D + W\_WE + 0.5*Lrs + Lps. Columns, internal shear force in local direction z [kN]}
\end{center}
\end{figure}

\begin{figure}
\begin{center}

\caption{ULS05\_d: 1.2*D + W\_NS + 0.5*Lrs + Lps. Columns, internal axial force [kN]}
\end{center}
\end{figure}
\begin{figure}
\begin{center}

\caption{ULS05\_d: 1.2*D + W\_NS + 0.5*Lrs + Lps. Columns, bending moment about local axis y [m.kN]}
\end{center}
\end{figure}
\begin{figure}
\begin{center}

\caption{ULS05\_d: 1.2*D + W\_NS + 0.5*Lrs + Lps. Columns, bending moment about local axis z [m.kN]}
\end{center}
\end{figure}
\begin{figure}
\begin{center}

\caption{ULS05\_d: 1.2*D + W\_NS + 0.5*Lrs + Lps. Columns, internal shear force in local direction y [kN]}
\end{center}
\end{figure}
\begin{figure}
\begin{center}

\caption{ULS05\_d: 1.2*D + W\_NS + 0.5*Lrs + Lps. Columns, internal shear force in local direction z [kN]}
\end{center}
\end{figure}
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

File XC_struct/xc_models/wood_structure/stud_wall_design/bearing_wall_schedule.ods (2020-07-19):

BEARING WALL SCHEDULE
 |  | Stud dimensions | Spacing (in) | Top plates | Bottom plate | Truss spacing | Remarks
 |  | (in) | (in) |  |  | (in)
Facade | 1st floor | 2x8 | 19.2 | (2) 2x8” | 2x8” | 12/24
 | 2nd floor | 2x8 | 19.2 | (2) 2x8” | 2x8” | 12/24
 | 3rd floor | 2x8 | 19.2 | (2) 2x8” | 2x8” | 24
Interior | 1st floor | 2x6 | 12 | (2) 2x6” | 2x6” | 12/24
 | 2nd floor | 2x6 | 24 | (3) 2x6” | 2x6” | 24
 | 2nd floor | 2x6 | 12 | (2) 2x6” | 2x6” | 12 | S2A and S2B in the figure
 | 3rd floor | 2x6 | 24 | (3) 2x6” | 2x6” | 24

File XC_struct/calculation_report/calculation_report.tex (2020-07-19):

\input{encab_A4}
\input{XC_page_layout_A4}
\usepackage{array, boldline, makecell, booktabs}
\newcommand\btrule[1]{\specialrule{#1}{0pt}{0pt}}
\usepackage{colortbl}
\usepackage{multicol,caption}               % three-column layout
%\usepackage[font={footnotesize}]{caption}
\usepackage{xcolor}
\newenvironment{Figure}
  {\par\medskip\noindent\minipage{\linewidth}}
  {\endminipage\par\medskip}
\usepackage{caption}
\usepackage[section]{placeins}
\usepackage{units}
%%\usepackage{draftwatermark}
%\maxdeadcycles=300

\title{Calculation Report: «1750 OX Residences - 1750 N Oxford Ave. - Eau Claire, WI» }
\author{XC structural engineering}
\date{\today}
\newcommand{\revision}{0.2}
\newcommand{\titdocum}{Calculation Report}
\begin{document}
\maketitle
\tableofcontents
\listoftables
\listoffigures
\cleardoublepage
\section{Introduction and scope}
\input{introduction.tex}
\section{Building codes}
\input{codes.tex}
\section{Loading criteria}
\input{loads.tex}
\section{Materials}
\input{materials.tex}
\section{Design and analysis software}
\input{software.tex}
\section{Load combinations}
\input{loadComb.tex}
\section{Wood framing}
\input{wood_framing.tex}
\section{Basement}
\input{basement.tex}
\section{Elevator shaft lintels}
\input{results_lintels/lintel_roof.tex}
\input{results_lintels/lintel_2floor.tex}
%\input{results_lintels/lintel_3floor.tex}
\input{results_lintels/lintel_1floor.tex}
\section{Balconies connection}
\input{balconies_connection.tex}

\newpage
\appendix
\section*{Appendices}
\addcontentsline{toc}{section}{Appendices}
\renewcommand{\thesubsection}{\Alph{subsection}}

\subsection{Loading criteria} \label{loadCrit}
\input{loads_annex/loads.tex}

\newpage
\subsection{Calculation results. Internal forces on columns}\label{sc_column_internal_forces}
\subsubsection{Ultimate limit states}
\input{annex_res_columns/ULS}
\clearpage
\newpage
\subsubsection{Serviceability limit states}
\input{annex_res_columns/SLS}
\end{document}

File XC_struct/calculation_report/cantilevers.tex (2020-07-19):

\subsection{Cantilevers}

\begin{figure}
  \begin{center}
  
  \end{center}
  \caption{Second floor cantilevers key plan.}\label{fg_2nd_floor_cantilevers_key_plan}
\end{figure}

\subsubsection{Cantilevers C1, C3, C4, C6, C7 and C8}

\paragraph{Loads.}

\begin{itemize}
\item Load from trusses (three trusses at 12 inches): 13.21 kN/truss
\item Facade weight: 25.76 kN
\item Total load: 65.41 kN
\end{itemize}

\paragraph{Internal forces.}

\noindent Maximum induced moment:

\begin{equation}
  M_{max}= 37.98\ kN m
\end{equation}

\noindent Maximum induced shear:

\begin{equation}
  V_{max}= 65.41\ kN
\end{equation}

\paragraph{Structural bending check.}

\noindent LSL 1.55E 5.25x14'' design resisting moment:

\begin{equation}
  M'_s= 44.89\ kN m
\end{equation}

\noindent Structural bending check: $M'_s = 44.89 > 37.98 = M_{max} \implies OK$

\paragraph{Structural shear check.}

\noindent LSL 1.55E 5.25x14'' design resisting shear:
\begin{equation}
  V'_s= 89.36\ kN
\end{equation}

\noindent Structural shear check: $V'_s = 89.36 > 65.41 = V_{max} \implies OK$

\paragraph{Bending stiffness.}
The deflection obtained under total load is:

\begin{equation}
  \Delta_{TL}= 1.88\ mm= \frac{L}{506} < \frac{L}{360} \implies OK
\end{equation}

\subsubsection{Cantilevers C2 and C5}

\paragraph{Loads.}

\begin{itemize}
\item Load from trusses (2x3 trusses at 12 inches): 13 kN/truss
\item Facade weight: 51.55 kN
\item Total load: 129.25 kN
\end{itemize}

\paragraph{Internal forces.}

\noindent Maximum induced moment:

\begin{equation}
  M_{max}= 63.79\ kN m
\end{equation}

\noindent Maximum induced shear:

\begin{equation}
  V_{max}= 129.25\ kN
\end{equation}

\paragraph{Structural bending check.}

\noindent (2) LSL 1.55E 5.25x14'' design resisting moment:

\begin{equation}
  M'_s= 65.88\ kN m
\end{equation}

\noindent Structural bending check: $M'_s = 65.88 > 63.79 = M_{max} \implies OK$

\paragraph{Structural shear check.}

\noindent (2) LSL 1.55E 5.25x14'' design resisting shear:
\begin{equation}
  V'_s= 151.60\ kN
\end{equation}

\noindent Structural shear check: $V'_s = 151.60 > 129.25 = V_{max} \implies OK$

\paragraph{Bending stiffness.}
The deflection obtained under total load is:

\begin{equation}
  \Delta_{TL}= 1.95\ mm= \frac{L}{442} < \frac{L}{360} \implies OK
\end{equation}

\subsubsection{Cantilever C9}

\paragraph{Loads.}
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

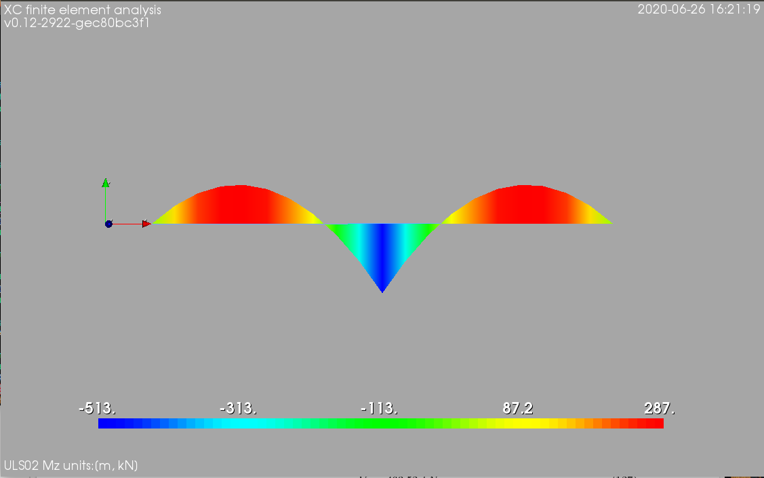
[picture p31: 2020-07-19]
XC_struct/calculation_report/figures/courtyard_facade_beam_uls02_mz.png

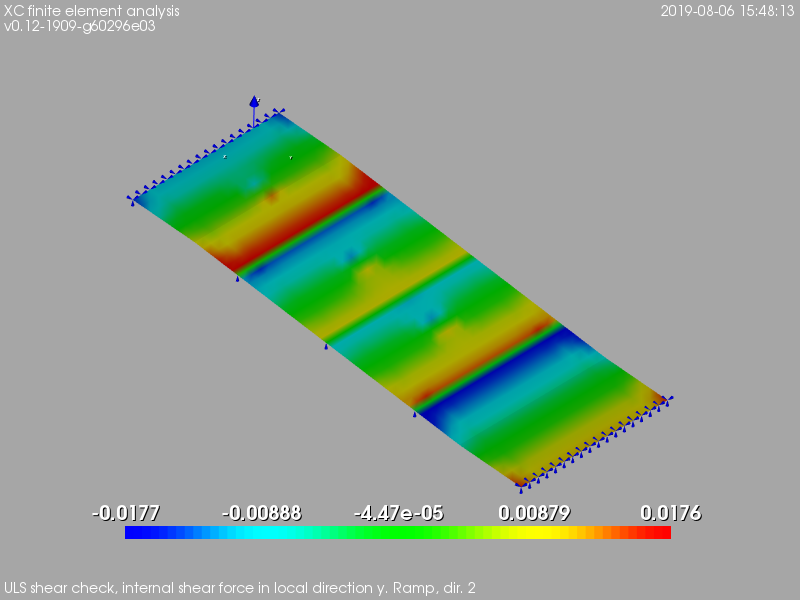
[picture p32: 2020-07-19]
XC_struct/calculation_report/ramp/figures/Vy_shear_long.png

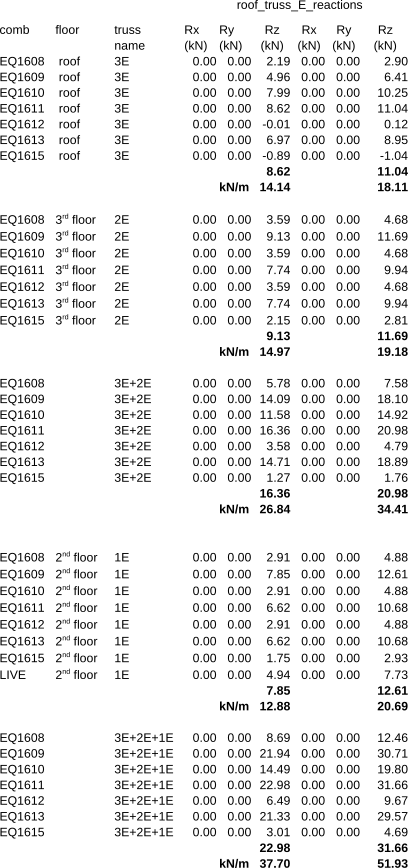
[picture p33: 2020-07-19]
XC_struct/calculation_report/figures/E_reactions.png

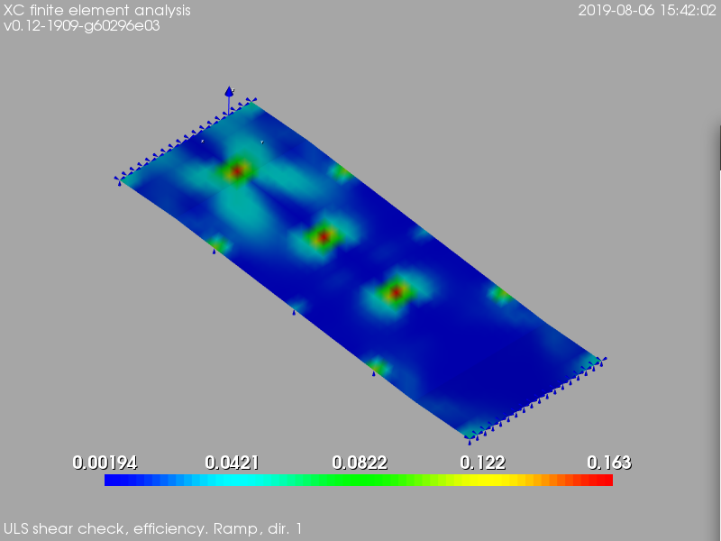
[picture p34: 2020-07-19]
XC_struct/calculation_report/ramp/figures/CF_shear_trans.png

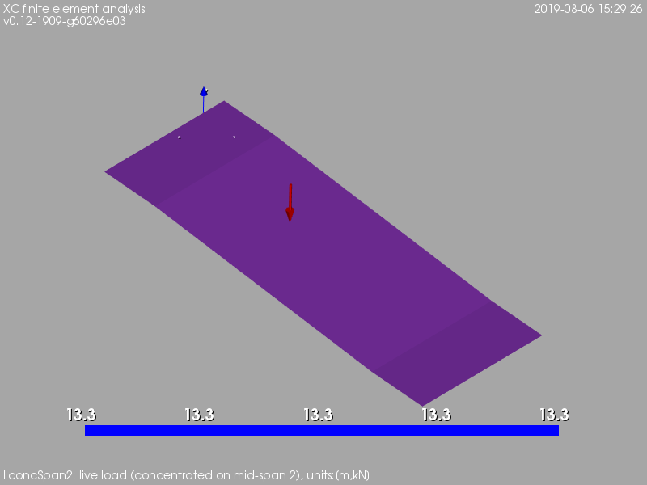
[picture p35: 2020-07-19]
XC_struct/calculation_report/ramp/figures/LconcSpan2.png

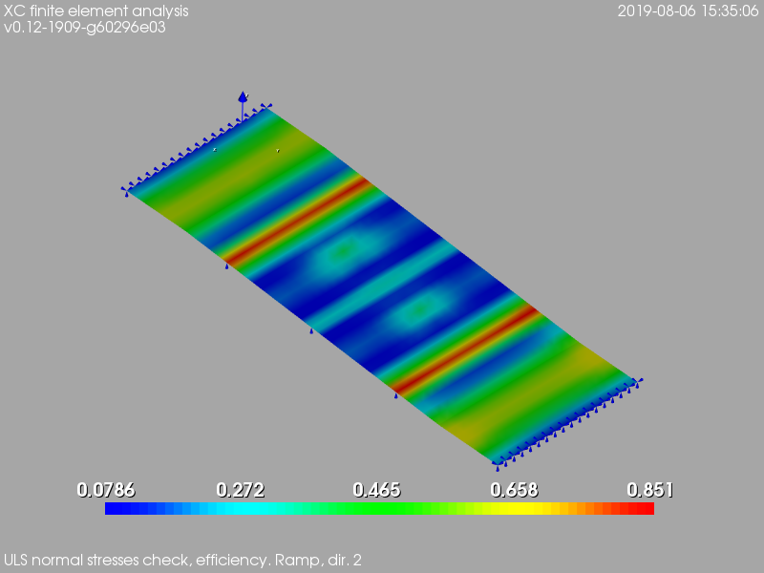
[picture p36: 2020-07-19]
XC_struct/calculation_report/ramp/figures/CF_normal_long.png

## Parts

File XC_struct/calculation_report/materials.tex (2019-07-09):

The material properties used for the design are summarized in Tables \ref{conc_mat} and \ref{reinf_mat}.
\begin{table}[h]
  \begin{center}
   \caption{\textbf{Concrete properties}} \label{conc_mat}
  \begin{tabular}{ll}
      \textbf{Member} & \textbf{Nominal f'$_c$} \\
      \hlineB{2}
      Footings & 3.0 ksi \\
      \arrayrulecolor{gray}\hline
      Basement Walls & 4.0 ksi \\
      \arrayrulecolor{gray}\hline
      Foundation frost walls & 4.0 ksi \\
      \arrayrulecolor{gray}\hline
      Stair landings and treads & 4.0 ksi \\
      \arrayrulecolor{gray}\hline
      Slab on grade &  4.0 ksi \\
      \hlineB{2}
  \end{tabular}
  \end{center}
\end{table}

\begin{table}[h]
  \begin{center}
   \caption{\textbf{Reinforcement properties}} \label{reinf_mat}
  \begin{tabular}{ll}
      \textbf{Standard} & \textbf{Nominal f$_y$} \\
      \hlineB{2}
      All ASTM A615 Grade 60 & 60 ksi \\
       \hlineB{2}
  \end{tabular}
  \end{center}
\end{table}

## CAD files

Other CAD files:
_closed/Products/03 - Concrete/03 40 00 Precast Concrete/20190930 - from GC/47-091-18_Preliminary Layout .dwg
_closed/Products/03 - Concrete/03 40 00 Precast Concrete/20191118 - from GC/47-091-19 Cannery Trails for Ryan Schultz at OD 11-19-19.dwg
_closed/Products/03 - Concrete/03 40 00 Precast Concrete/20191209 - from precast eng - 2nd floor - partial plan/Cannery AutoCAD file 2nd floor layout only 12-6-19.dwg
_closed/Products/03 - Concrete/03 40 00 Precast Concrete/20191210 - from precast eng - review set/Cannery AutoCAD file beam column only 12-11-19.dwg
_closed/Products/03 - Concrete/03 40 00 Precast Concrete/20200210 - from precast eng - CAD background/plank - 5 core.dwg
_closed/Products/03 - Concrete/03 40 00 Precast Concrete/20200421 - from precast eng - final drawings and calcs for permit/47-091-19 Cananery Trails for architect records only May 4, 2020.dwg
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

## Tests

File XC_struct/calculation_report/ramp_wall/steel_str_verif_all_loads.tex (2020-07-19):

\textbf{Beam parallel to facade} \\
\underline{shear checking:} \\
V$_{d,max}$=  55.02  kN \\ V$_{provided}$=  233.1  kN \\ Capacity factor: F=  0.24  \\
\underline{normal stresses checking:} \\
M$_{d,max}$=  56.84  mkN \\ M$_{provided}$=  170.66  mkN \\ Capacity factor: F=  0.33  \\

\textbf{West cantilever} \\
\underline{shear checking:} \\
V$_{d,max}$=  115.64  kN \\ V$_{provided}$=  286.79  kN \\ Capacity factor: F=  0.4  \\
\underline{normal stresses checking:} \\
M$_{d,max}$=  71.16  mkN \\ M$_{provided}$=  214.07  mkN \\ Capacity factor: F=  0.33  \\

\textbf{Central cantilever} \\
\underline{shear checking:} \\
V$_{d,max}$=  198.6  kN \\ V$_{provided}$=  286.79  kN \\ Capacity factor: F=  0.69  \\
\underline{normal stresses checking:} \\
M$_{d,max}$=  127.68  mkN \\ M$_{provided}$=  214.07  mkN \\ Capacity factor: F=  0.6  \\

\textbf{East cantilever} \\
\underline{shear checking:} \\
V$_{d,max}$=  11.39  kN \\ V$_{provided}$=  286.79  kN \\ Capacity factor: F=  0.04  \\
\underline{normal stresses checking:} \\
M$_{d,max}$=  1.86  mkN \\ M$_{provided}$=  214.07  mkN \\ Capacity factor: F=  0.01  \\

 \textbf{Column} \\
\underline{shear checking:} \\
V$_{d,max}$=  0.05  kN \\ V$_{provided}$=  130.5  kN \\ Capacity factor: F=  0.0  \\
\underline{normal stresses checking:} \\
M$_{d,max}$=  0.16  mkN \\ M$_{provided}$=  214.07  mkN \\ Capacity factor: F=  0.0  \\
\underline{shear checking:} \\
V$_{d,max}$=  0.84  kN \\ V$_{provided}$=  130.5  kN \\ Capacity factor: F=  0.01  \\
\underline{normal stresses checking:} \\
M$_{d,max}$=  2.9  mkN \\ M$_{provided}$=  32.19  mkN \\ Capacity factor: F=  0.09  \\

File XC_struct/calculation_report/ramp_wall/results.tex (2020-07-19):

\subsubsection{Verification of reinforced-concrete walls}
\input{ramp_wall/resLC/text/sectReport.tex}
\twocolumn
\paragraph{Displacements and internal forces in ULS}
\input{ramp_wall/resLC/text/report_resSimplLC.tex}
\clearpage
\paragraph{Verification of normal stresses}
\input{ramp_wall/resLC/text/report_normStrsULS.tex}
\clearpage
\paragraph{Verification of shear ULS}
\input{ramp_wall/resLC/text/report_shearULS.tex}
\clearpage

\subsubsection{Verification of steel structure}
\paragraph{ULS all loads}
\input{ramp_wall/steel_str_verif_all_loads.tex}
\paragraph{ULS only cantilever loaded}
\input{ramp_wall/steel_str_verif_only_cantilever_loads.tex}
\onecolumn

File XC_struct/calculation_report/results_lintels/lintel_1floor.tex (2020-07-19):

\subsection{Lintel 1st floor}

\subsubsection{Geometry data}
Clear span=  2 feet 8 inches \\
Bearing length (at each extremity)=  0 feet 0 inches \\
Height of masonry above the opening=  1/2 inches \\
Mmax=  29849.23 lb-ft = 358190.71  lb-in \\
Vmax=  44768.24 lb

\subsubsection{Load data}
Lintel self-weight=  2362.5  $\frac{lb}{ft}$ \\
Wall self weight=  20590.47 $\frac{lb}{ft^2}$\\
Superimposed dead uniform load=  9216.95 $\frac{lb}{ft}$ \\
Live uniform load=  12289.27 $\frac{lb}{ft}$ \\
Snow uniform load=  6451.86 $\frac{lb}{ft}$ 

\subsubsection{Check for arching action}
Effective span l=  2 feet 8 inches \\
Height of masonry required above the lintel for arching action to occur=  2 and 11/32 inches \\
Arching action occurs (not considered conservatively) 

\subsubsection{Check concrete masonry lintel - strenght design}
Maximum bending moment due to lintel self weigth=  2100.53 lb-ft \\
Maximum bending moment due to wall self weigth=  -2379.94 lb-ft \\
Maximum bending moment due to superimposed dead load=  8194.89 lb-ft \\
Maximum bending moment due to live load=  10926.52 lb-ft \\
Maximum bending moment due to snow load=  5736.42 lb-ft \\
Maximum bending moment ULS01=  11081.67 lb-ft \\
Maximum bending moment ULS02=  29849.23 lb-ft \\
Maximum bending moment ULS03=  24140.12 lb-ft \\
Maximum bending moment=  29849.23 lb-ft \\
Bending moment provided= 40316.08 lb-ft (see fig. \ref{8_24})\\
Maximum shear force due to lintel self weigth=  3150.39 lb \\
Maximum shear force due to wall self weigth=  -3569.46 lb \\
Maximum shear force due to superimposed dead load=  12290.8 lb \\
Maximum shear force due to live load=  16387.74 lb \\
Maximum shear force due to snow load=  8603.56 lb \\
Maximum shear force ULS01=  16620.43 lb \\
Maximum shear force ULS02=  44768.24 lb \\
Maximum shear force ULS03=  36205.65 lb \\
Maximum shear force=  44768.24 lb $\rightarrow$ \#3 at 16 in.\\

\begin{figure}
  \begin{center}
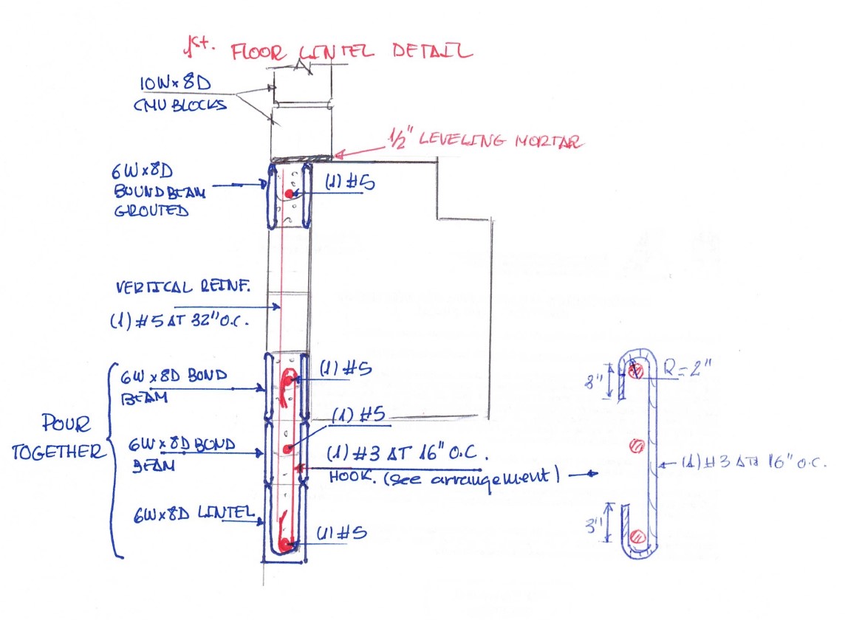
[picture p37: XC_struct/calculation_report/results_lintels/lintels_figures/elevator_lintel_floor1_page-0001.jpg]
  
  \end{center}
  \caption{1st floor lintel detail}\label{elevator_lintel_floor1.jpg}
\end{figure}

\begin{figure}
  \begin{center}
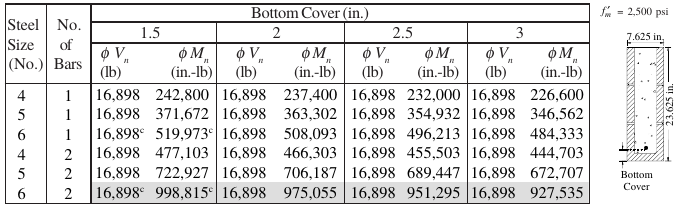
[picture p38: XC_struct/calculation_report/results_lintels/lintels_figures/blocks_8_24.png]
  
  \end{center}
  \caption{Design shear and moment capacity for nominal 8 x 24 in. concrete masonry lintels}\label{8_24}
\end{figure}

\subsubsection{Check lintel deflection}
Modulus of elasticity E=  30000000000.0  psf \\
Moment of inertia I=$  0.0031255875$ $ft^4$
$\Delta_{max,dead} =$  0.00075  in \\
$\Delta_{max,live} =$  0.00104  in \\
$\Delta_{max,snow}$ =  0.00054  in \\
$\Delta_{max} =$  0.00233  in \\
$\Delta_{max,allowed} =$  0.05334  in \\
$\Delta_{max} =$  0.00233  < $\Delta_{max,allowed} =$  0.05334  ok \\

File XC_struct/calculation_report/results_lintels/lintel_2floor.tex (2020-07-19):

\begin{figure}
  \begin{center}
  
  \end{center}
  \caption{Elevator lintels}\label{elevator_lintels.pdf}
\end{figure}

\subsection{Lintel 3rd and 2nd floor}
\subsubsection{Geometry data}
Clear span=  4 feet 10 inches \\
Bearing length (at each extremity)=  21/32 inches \\
Height of masonry above the opening=  3 and 11/32 inches \\
Mmax=  1910.65 lb-ft = 22927.80  lb-in \\
Vmax=  1389.56 lb \\
\subsubsection{Load data}
Lintel self-weight=  59  $\frac{lb}{ft}$ \\
Wall self weight=  47 $\frac{lb}{ft^2}$ \\
Superimposed dead uniform load=  64.17 $\frac{lb}{ft}$ \\
Live uniform load=  128.33 $\frac{lb}{ft}$ \\
Snow uniform load=  0 $\frac{lb}{ft}$ \\
\vspace{0.25 cm}
\subsubsection{Check for arching action}
Effective span l=  5 feet 5 and 1 inches \\
Height of masonry required above the lintel for arching action to occur=  3 and 13/32 inches \\
Arching action occurs (not considered conservatively) \\
\subsubsection{Check concrete masonry lintel - strenght design}
Maximum bending moment due to lintel self weigth=  223.09 lb-ft \\
Maximum bending moment due to wall self weigth=  479.47 lb-ft \\
Maximum bending moment due to superimposed dead load=  242.63 lb-ft \\
Maximum bending moment due to live load=  485.26 lb-ft \\
Maximum bending moment due to snow load=  0.0 lb-ft \\
Maximum bending moment ULS01=  1323.27 lb-ft \\
Maximum bending moment ULS02=  1910.65 lb-ft \\
Maximum bending moment ULS03=  1376.86 lb-ft \\
Maximum bending moment=  1910.65 lb-ft \\
Bending moment provided= 5165.00 lb-ft (see fig \ref{8x8}) \\
Maximum shear force due to lintel self weigth=  162.25 lb \\
Maximum shear force due to wall self weigth=  348.71 lb \\
Maximum shear force due to superimposed dead load=  176.46 lb \\
Maximum shear force due to live load=  352.92 lb \\
Maximum shear force due to snow load=  0.0 lb \\
Maximum shear force ULS01=  962.38 lb \\
Maximum shear force ULS02=  1389.56 lb \\
Maximum shear force ULS03=  1001.36 lb \\
Maximum shear force=  1389.56 lb \\
Shear force provided= 5232.00 lb (see fig \ref{8x8}) \\

%% \begin{table}[h]
%%   \begin{center}
%%    \caption{\textbf{Allowable Shear and Moment for Nominal 8 x 8 in. Concrete Masonry Lintels}} \label{8x8}
%%    \begin{tabular}{llllllllll}
%%       Steel & No. & & & & Bottom Cover (in.) & & & \\
%%       \arrayrulecolor{gray}\hline
%%       Size & of & 1.5 & & 2 & & 2.5 & & 3 & \\
%%       \arrayrulecolor{gray}\hline
%%       (No.) & Bars & $V_{all}$ & $M_{all}$ & $V_{all}$ & $M_{all}$ & $V_{all}$ & $M_{all}$ & $V_{all}$ & $M_{all}$ \\
%%       & & lb & in.-lb & lb & in.-lb & lb & in.-lb & lb & in.-lb \\
%%       \hlineB{2}
%%       4 & 1 & 1734 & 20464 & 1587 & 17651 & 1439 & 14997 & 1292 & 12509 \\
%%       \arrayrulecolor{gray}\hline
%%       5 & 1 & 1716 & 23176 & 1568 & 19898 & 1421 & 16816 & 1273 & 13938 \\
%%       \arrayrulecolor{gray}\hline
%%       6 & 1 & 1698 & 25219 & 1550 & 21557 & 1402 & 18125 & 1255 & 14933 \\
%%       \arrayrulecolor{gray}\hline
%%       4 & 2 & 1734 & 25468 & 1587 & 21866 & 1439 & 18481 & 1292 & 15323 \\
%%       \arrayrulecolor{gray}\hline
%%       5 & 2 & 1716 & 28142 & 1568 & 24036 & 1421 & 20194 & 1273 & 16628 \\
%%       \arrayrulecolor{gray}\hline
%%       6 & 2 & 1698 & 29973 & 1550 & 25478 & 1402 & 21289 & 1255 & 17418 \\
%%       \hlineB{2}
%%   \end{tabular}
%%   \end{center}
%% \end{table}
\begin{figure}
  \begin{center}
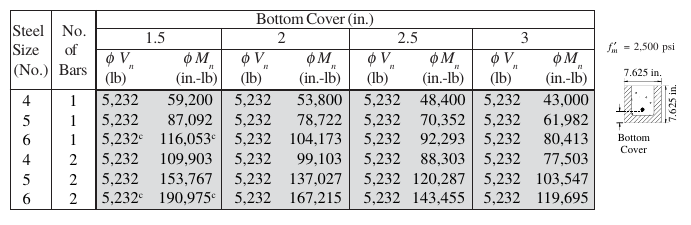
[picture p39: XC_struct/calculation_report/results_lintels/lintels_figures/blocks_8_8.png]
  
  \end{center}
  \caption{Design shear and moment capacity for nominal 8 x 8 in. concrete masonry lintels}\label{8x8}
\end{figure}

\subsubsection{Check lintel deflection}
Modulus of elasticity E=  194400000.0  psf \\
Moment of inertia I=$  0.0135847972744$  $ft^4 $
$\Delta_{max,dead} =$  0.01353  in \\
$\Delta_{max,live} =$  0.00695  in \\
$\Delta_{max,snow} =$  0.0  in \\
$\Delta_{max} =$  0.02048  in \\
$\Delta_{max,allowed} =$  0.11  in \\
$\Delta_{max} =$  0.02048  < $\Delta_{max,allowed} =$  0.11  ok \\

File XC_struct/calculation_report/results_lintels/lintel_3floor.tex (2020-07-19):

\subsection{Lintel 3rd floor}
\subsubsection{Geometry data}
Clear span=  4 feet 10 inches \\
Bearing length (at each extremity)=  21/32 inches \\
Height of masonry above the opening=  3 and 11/32 inches \\
Mmax=  1910.64986979 lb-ft = 22927.7984375  lb-in \\
Vmax=  1389.56354167 lb \\
\subsubsection{Load data}
Lintel self-weight=  59  $\frac{lb}{ft}$ \\
Wall self weight=  47 $\frac{lb}{ft^2}$
Superimposed dead uniform load=  64.1666666667 $\frac{lb}{ft}$ \\
Live uniform load=  128.333333333 $\frac{lb}{ft}$ \\
Snow uniform load=  0 $\frac{lb}{ft}$ \\
\vspace{0.25 cm}
Check for arching action \\
Effective span l=  5 feet 5 and 1 inches \\
Height of masonry required above the lintel for arching action to occur=  3 and 13/32 inches \\
Arching action occurs (not considered conservatively \\
Check concrete masonry lintel - strenght design \\
Maximum bending moment due to lintel self weigth=  223.09 lb-ft \\
Maximum bending moment due to wall self weigth=  479.47 lb-ft \\
Maximum bending moment due to superimposed dead load=  242.63 lb-ft \\
Maximum bending moment due to live load=  485.26 lb-ft \\
Maximum bending moment due to snow load=  0.0 lb-ft \\
Maximum bending moment ULS01=  1323.27 lb-ft \\
Maximum bending moment ULS02=  1910.65 lb-ft \\
Maximum bending moment ULS03=  1376.86 lb-ft \\
Maximum bending moment=  1910.65 lb-ft \\
Bending moment provided= 13938 lb-ft (see table \ref{8x8}) \\
Maximum shear force due to lintel self weigth=  162.25 lb \\
Maximum shear force due to wall self weigth=  348.71 lb \\
Maximum shear force due to superimposed dead load=  176.46 lb \\
Maximum shear force due to live load=  352.92 lb \\
Maximum shear force due to snow load=  0.0 lb \\
Maximum shear force ULS01=  962.38 lb \\
Maximum shear force ULS02=  1389.56 lb \\
Maximum shear force ULS03=  1001.36 lb \\
Maximum shear force=  1389.56 lb \\
Shear force provided= 1273 lb (see table \ref{8x8}) \\
Check lintel deflection \\
Modulus of elasticity E=  194400000.0  psf \\
Moment of inertia I=$  0.0135847972744$  $ft^4 $
$\Delta_{max,dead} =$  0.01353  in \\
$\Delta_{max,live} =$  0.00695  in \\
$\Delta_{max,snow} =$  0.0  in \\
$\Delta_{max} =$  0.02048  in \\
$\Delta_{max,allowed} =$  0.11  in \\
$\Delta_{max} =$  0.02048  < $\Delta_{max,allowed} =$  0.11  ok \\

\begin{table}[h]
  \begin{center}
   \caption{\textbf{Allowable Shear and Moment for Nominal 8 x 8 in. Concrete Masonry Lintels}} \label{8x8}
   \begin{tabular}{llllllllll}
      Steel & No. & & & & Bottom Cover (in.) & & & \\
      \arrayrulecolor{gray}\hline
      Size & of & 1.5 & & 2 & & 2.5 & & 3 & \\
      \arrayrulecolor{gray}\hline
      (No.) & Bars & $V_{all}$ & $M_{all}$ & $V_{all}$ & $M_{all}$ & $V_{all}$ & $M_{all}$ & $V_{all}$ & $M_{all}$ \\
      & & lb & in.-lb & lb & in.-lb & lb & in.-lb & lb & in.-lb \\
      \hlineB{2}
      4 & 1 & 1734 & 20464 & 1587 & 17651 & 1439 & 14997 & 1292 & 12509 \\
      \arrayrulecolor{gray}\hline
      5 & 1 & 1716 & 23176 & 1568 & 19898 & 1421 & 16816 & 1273 & 13938 \\
      \arrayrulecolor{gray}\hline
      6 & 1 & 1698 & 25219 & 1550 & 21557 & 1402 & 18125 & 1255 & 14933 \\
      \arrayrulecolor{gray}\hline
      4 & 2 & 1734 & 25468 & 1587 & 21866 & 1439 & 18481 & 1292 & 15323 \\
      \arrayrulecolor{gray}\hline
      5 & 2 & 1716 & 28142 & 1568 & 24036 & 1421 & 20194 & 1273 & 16628 \\
      \arrayrulecolor{gray}\hline
      6 & 2 & 1698 & 29973 & 1550 & 25478 & 1402 & 21289 & 1255 & 17418 \\
      \hlineB{2}
  \end{tabular}
  \end{center}
\end{table}

\begin{figure}
  \begin{center}
  
  \end{center}
  \caption{1st floor lintel detail}\label{elevator_lintels.pdf}
\end{figure}

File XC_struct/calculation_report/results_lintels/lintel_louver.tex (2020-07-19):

Linter louver \\
***Geometry data*** \\
Clear span=  4 feet 8 inches \\
Bearing length (at each extremity)=  21/32 inches \\
Height of masonry above the opening=  0 feet 0 inches \\
Mmax=  1380.84444444 lb-ft = 16570.1333333  lb-in \\
Vmax=  1035.63333333 lb \\
***Load data*** \\
Lintel self-weight=  59  $\frac{lb}{ft}$ \\
Wall self weight=  47 $\frac{lb}{ft^2}$
Superimposed dead uniform load=  77.5 $\frac{lb}{ft}$ \\
Live uniform load=  0 $\frac{lb}{ft}$ \\
Snow uniform load=  162.75 $\frac{lb}{ft}$ \\
 \\
Check for arching action \\
Effective span l=  5 feet 4 inches \\
Height of masonry required above the lintel for arching action to occur=  3 and 11/32 inches \\
Arching action occurs (not considered conservatively \\
Check concrete masonry lintel - strenght design \\
Maximum bending moment due to lintel self weigth=  209.78 lb-ft \\
Maximum bending moment due to wall self weigth=  -106.19 lb-ft \\
Maximum bending moment due to superimposed dead load=  275.56 lb-ft \\
Maximum bending moment due to live load=  0.0 lb-ft \\
Maximum bending moment due to snow load=  578.67 lb-ft \\
Maximum bending moment ULS01=  530.81 lb-ft \\
Maximum bending moment ULS02=  744.31 lb-ft \\
Maximum bending moment ULS03=  1380.84 lb-ft \\
Maximum bending moment=  1380.84 lb-ft \\
Bending moment provided= XXXXX lb-ft \\
Maximum shear force due to lintel self weigth=  157.33 lb \\
Maximum shear force due to wall self weigth=  -79.64 lb \\
Maximum shear force due to superimposed dead load=  206.67 lb \\
Maximum shear force due to live load=  0.0 lb \\
Maximum shear force due to snow load=  434.0 lb \\
Maximum shear force ULS01=  398.11 lb \\
Maximum shear force ULS02=  558.23 lb \\
Maximum shear force ULS03=  1035.63 lb \\
Maximum shear force=  1035.63 lb \\
Shear force provided= XXXXX lb \\
Check lintel deflection \\
Modulus of elasticity E=  194400000.0  psf \\
Moment of inertia I=$  0.0135847972744$  $ft^4$
$\Delta_{max,dead} =$  0.0051  in \\
$\Delta_{max,live} =$  0.0  in \\
$\Delta_{max,snow} =$  0.00779  in \\
$\Delta_{max} =$  0.0129  in \\
$\Delta_{max,allowed} =$  0.10667  in \\
$\Delta_{max} =$  0.0129  < $\Delta_{max,allowed} =$  0.10667  ok \\

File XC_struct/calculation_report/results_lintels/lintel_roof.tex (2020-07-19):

\subsection{Lintel roof}
\subsubsection{Geometry data}
Clear span=  8 feet 8 inches \\
Bearing length (at each extremity)=  21/32 inches \\
Height of masonry above the opening=  8 inches \\
Mmax=  8841.37 lb-ft = 106096.43  lb-in \\
Vmax=  3789.16 lb \\
\subsubsection{Load data}
Lintel self-weight=  118  $\frac{lb}{ft}$ \\
Wall self weight=  47 $\frac{lb}{ft^2}$\\
Superimposed dead uniform load=  64.1666666667 $\frac{lb}{ft}$ \\
Live uniform load=  0 $\frac{lb}{ft}$ \\
Snow uniform load=  134.75 $\frac{lb}{ft}$ \\

\subsubsection{Check for arching action}
Effective span l=  9 feet 4 inches \\
Height of masonry required above the lintel for arching action to occur=  5 and 11/32 inches \\
Arching action occurs (not considered conservatively) \\
Check concrete masonry lintel - strenght design \\
Maximum bending moment due to lintel self weigth=  1284.89 lb-ft \\
Maximum bending moment due to wall self weigth=  3427.84 lb-ft \\
Maximum bending moment due to superimposed dead load=  698.7 lb-ft \\
Maximum bending moment due to live load=  0.0 lb-ft \\
Maximum bending moment due to snow load=  1467.28 lb-ft \\
Maximum bending moment ULS01=  7576.01 lb-ft \\
Maximum bending moment ULS02=  7227.36 lb-ft \\
Maximum bending moment ULS03=  8841.37 lb-ft \\
Maximum bending moment=  30946.00 lb-ft \\
Bending moment provided= 80862 lb-ft (see fig \ref{8x16}) \\
Maximum shear force due to lintel self weigth=  550.67 lb \\
Maximum shear force due to wall self weigth=  1469.08 lb \\
Maximum shear force due to superimposed dead load=  299.44 lb \\
Maximum shear force due to live load=  0.0 lb \\
Maximum shear force due to snow load=  628.83 lb \\
Maximum shear force ULS01=  3246.86 lb \\
Maximum shear force ULS02=  3097.44 lb \\
Maximum shear force ULS03=  3789.16 lb \\
Maximum shear force=  3789.16 lb \\
Shear force provided= 10722.00 lb (see fig \ref{8x16}) \\

\begin{figure}
  \begin{center}
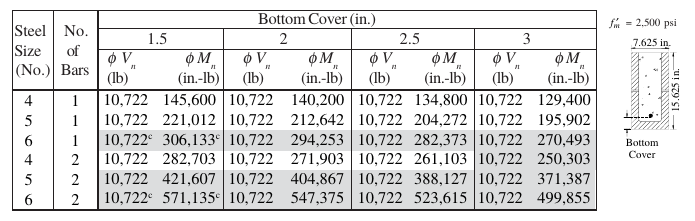
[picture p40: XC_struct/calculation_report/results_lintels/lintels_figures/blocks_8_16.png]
  
  \end{center}
  \caption{Design shear and moment capacity for nominal 8 x 8 in. concrete masonry lintels}\label{8x16}
\end{figure}

%% \begin{table}[h]
%%   \begin{center}
%%    \caption{\textbf{Allowable Shear and Moment for Nominal 8 x 16 in. Concrete Masonry Lintels}} \label{8x16}
%%    \begin{tabular}{llllllllll}
%%       Steel & No. & & & & Bottom Cover (in.) & & & \\
%%       \arrayrulecolor{gray}\hline
%%       Size & of & 1.5 & & 2 & & 2.5 & & 3 & \\
%%       \arrayrulecolor{gray}\hline
%%       (No.) & Bars & $V_{all}$ & $M_{all}$ & $V_{all}$ & $M_{all}$ & $V_{all}$ & $M_{all}$ & $V_{all}$ & $M_{all}$ \\
%%       & & lb & in.-lb & lb & in.-lb & lb & in.-lb & lb & in.-lb \\
%%       \hlineB{2}
%%       4 & 1 & 4097 & 61110 & 3949 & 58824 & 3802 & 56540 & 3654 & 54258 \\
%%       \arrayrulecolor{gray}\hline
%%       5 & 1 & 4079 & 92558 & 3931 & 89057 & 3783 & 85560 & 3636 & 80862 \\
%%       \arrayrulecolor{gray}\hline
%%       6 & 1 & 4060 & 109743 & 3912 & 103212 & 3765 & 96832 & 3617 & 90604 \\
%%       \arrayrulecolor{gray}\hline
%%       4 & 2 & 4097 & 107759 & 3949 & 101428 & 3802 & 95241 & 3654 & 89200 \\
%%       \arrayrulecolor{gray}\hline
%%       5 & 2 & 4079 & 123963 & 3931 & 116517 & 3783 & 109247 & 3636 & 102156 \\
%%       \arrayrulecolor{gray}\hline
%%       6 & 2 & 4060 & 137015 & 3912 & 128617 & 3765 & 120426 & 3617 & 112446 \\
%%       \hlineB{2}
%%   \end{tabular}
%%   \end{center}
%% \end{table}

\subsubsection{Check lintel deflection }
Modulus of elasticity E=  194400000.0  psf \\
Moment of inertia I=$  0.116894397225$  $ft^4$
$\Delta_{max,dead} =$  0.02593  in \\
$\Delta_{max,live} =$  0.0  in \\
$\Delta_{max,snow} =$  0.00703  in \\
$\Delta_{max} =$  0.03296  in \\
$\Delta_{max,allowed} =$  0.18667  in \\
$\Delta_{max} =$  0.03296  < $\Delta_{max,allowed} =$  0.18667  ok \\

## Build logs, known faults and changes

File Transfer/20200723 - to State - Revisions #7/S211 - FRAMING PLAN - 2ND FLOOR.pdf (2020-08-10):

1 | 2 | 3 | 4 | 5

A

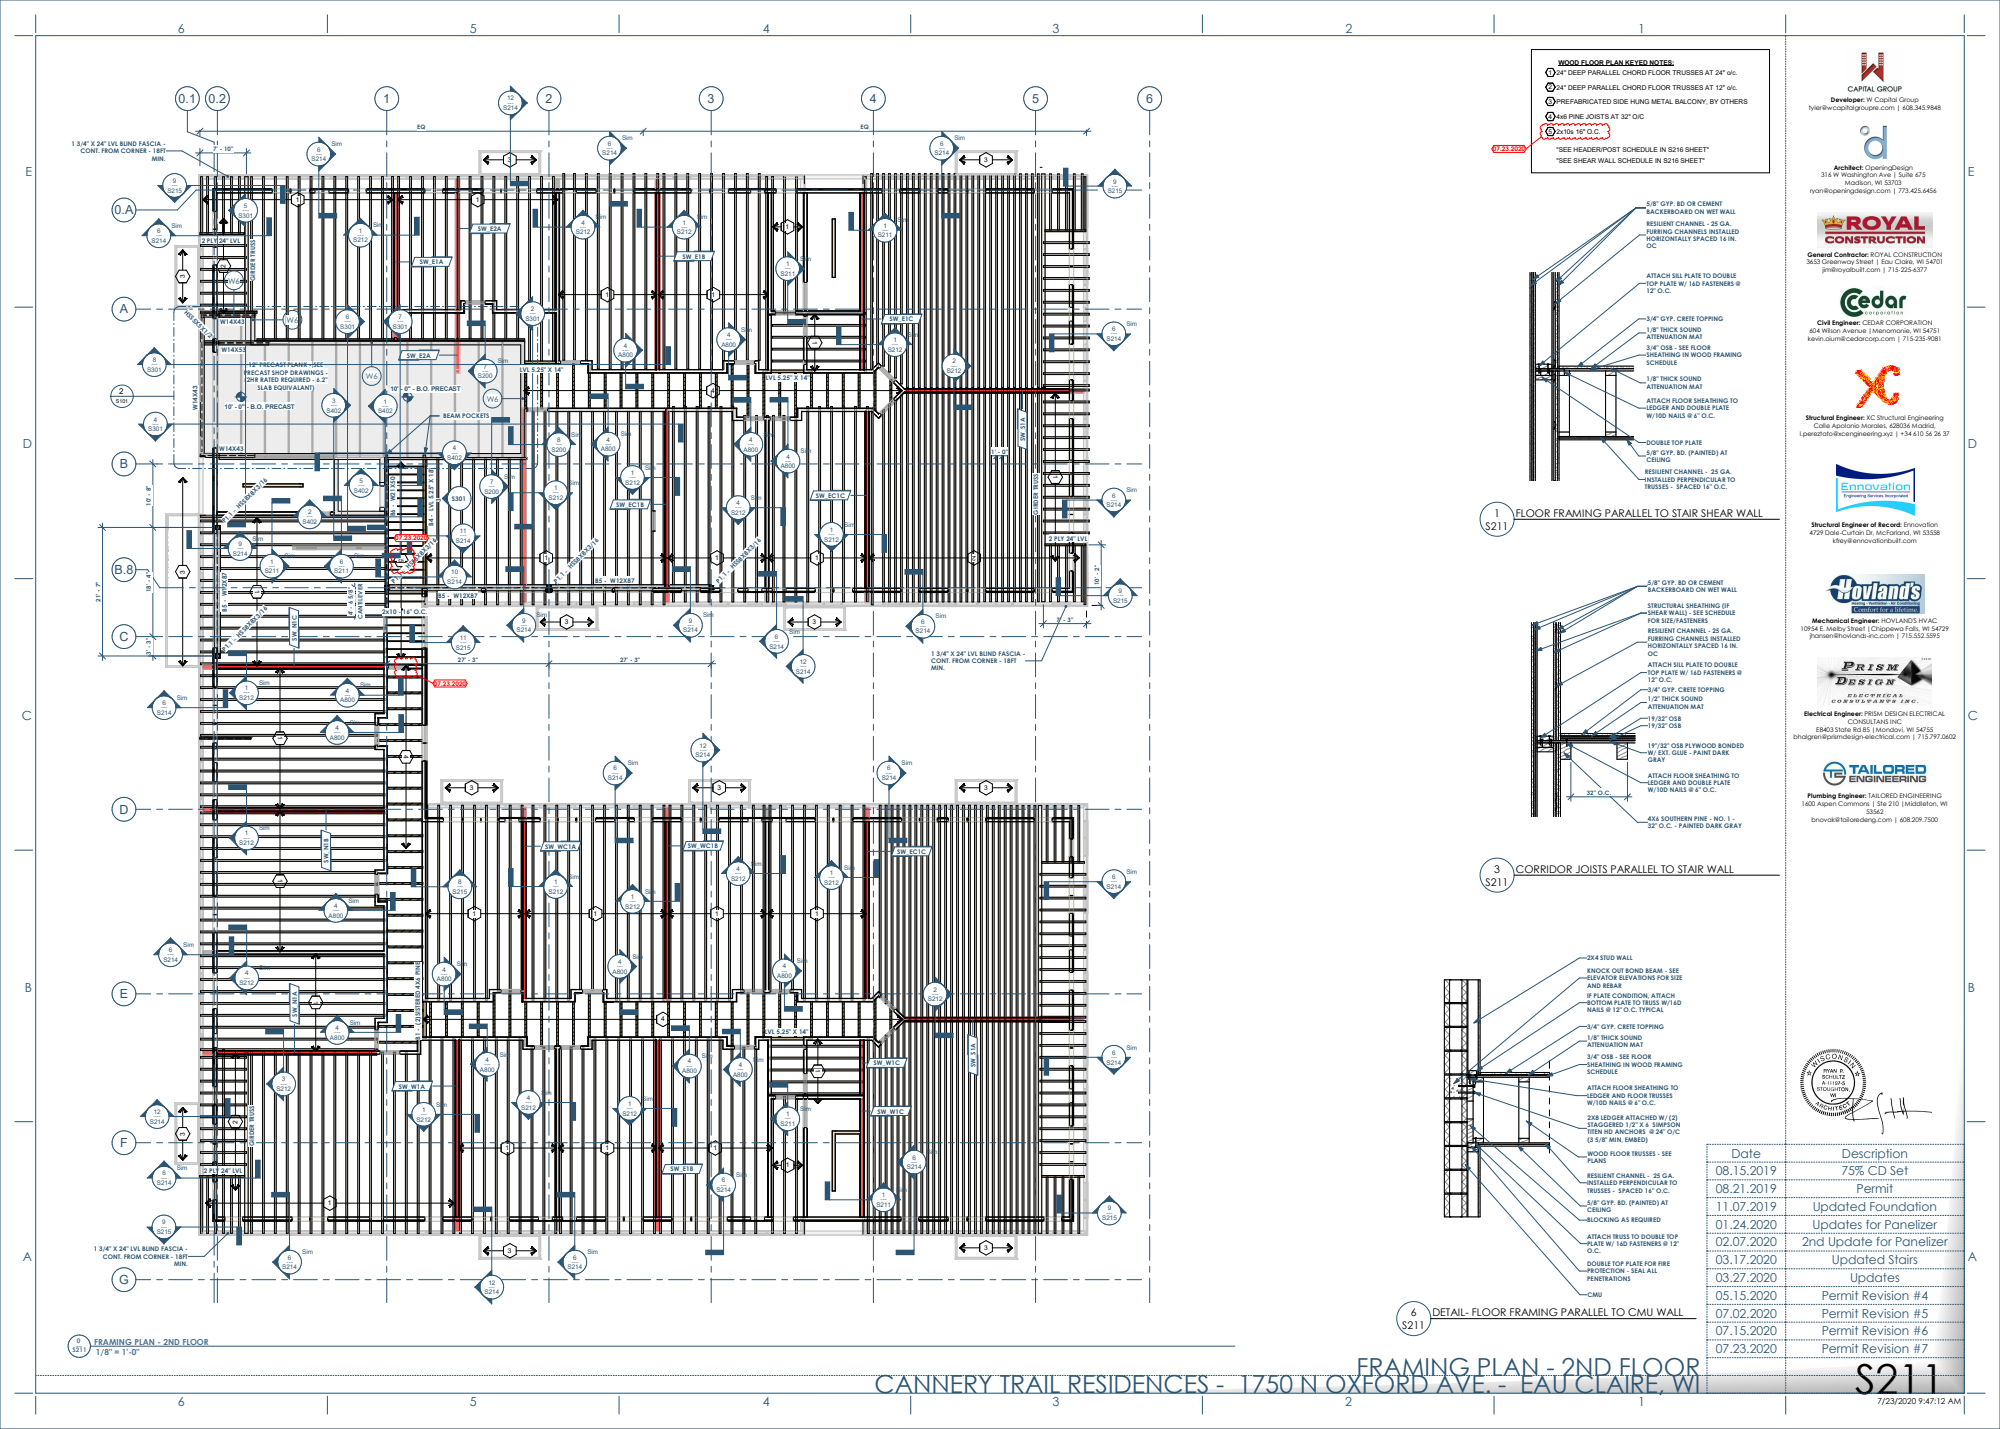
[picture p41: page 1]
Sim; P1.1 - HSS8X8X3/16; P1.1 - HSS8X8X3/16 B5 - W12X87; B4 - LVL 5.25" X 18"; PRECAST SHOP; DRAWINGS -; SLAB EQUIVALANT); PRECAST; 2 PLY 24" LVL; GIRDER TRUSS; HSS5X5X1/2; LVL 5.25" X 14"; B1 - (2)SISTERED 4X6 PINE; BEAM POCKETS; NTILEVER; MIN.; CMU; 2X4 STUD WALL; 1/8" THICK SOUND ATTENUATION MAT; W/10D NAILS @ 6" O.C. 32" O.C.; 19/32" OSB 19/32" OSB; Madison, WI 53703; CONSULTANS INC; 0 FRAMING PLAN - 2ND FLOOR; Date; Description

WOOD FLOOR PLAN KEYED NOTES:
24'' DEEP PARALLEL CHORD FLOOR TRUSSES AT 24'' o/c.

24'' DEEP PARALLEL CHORD FLOOR TRUSSES AT 12'' o/c.

Developer: W Capital Group

PREFABRICATED SIDE HUNG METAL BALCONY, BY OTHERS

tyler@wcapitalgroupre.com | 608.345.9848

4x6 PINE JOISTS AT 32" O/C

1 3/4" X 24" LVL BLIND FASCIA -
CONT. FROM CORNER - 18FT

"SEE HEADER/POST SCHEDULE IN S216 SHEET"

"SEE SHEAR WALL SCHEDULE IN S216 SHEET"

Architect: OpeningDesign
316 W Washington Ave | Suite 675

ryan@openingdesign.com | 773.425.6456

5/8" GYP. BD OR CEMENT
BACKERBOARD ON WET WALL

RESILIENT CHANNEL - 25 GA.
FURRING CHANNELS INSTALLED
HORIZONTALLY SPACED 16 IN.

General Contractor: ROYAL CONSTRUCTION
3653 Greenway Street | Eau Claire, WI 54701
jim@royalbuilt.com | 715-225-6377

ATTACH SILL PLATE TO DOUBLE
TOP PLATE W/ 16D FASTENERS @

3/4" GYP. CRETE TOPPING
1/8" THICK SOUND
ATTENUATION MAT
3/4" OSB - SEE FLOOR
SHEATHING IN WOOD FRAMING
SCHEDULE

Civil Engineer: CEDAR CORPORATION
604 Wilson Avenue |Menomonie, WI 54751
kevin.oium@cedarcorp.com | 715-235-9081

12" PRECAST PLANK - SEE
(2HR RATED REQUIRED - 6.2"

ATTACH FLOOR SHEATHING TO
LEDGER AND DOUBLE PLATE
W/10D NAILS @ 6" O.C.

Structural Engineer: XC Structural Engineering
Calle Apolonio Morales, 628036 Madrid,
l.pereztato@xcengineering.xyz | +34 610 56 26 37

DOUBLE TOP PLATE
5/8" GYP. BD. (PAINTED) AT
CEILING

INSTALLED PERPENDICULAR TO
TRUSSES - SPACED 16" O.C.

1 FLOOR FRAMING PARALLEL TO STAIR SHEAR WALL

Structural Engineer of Record: Ennovation
4729 Dale-Curtain Dr, McFarland, WI 53558

kfrey@ennovationbuilt.com

STRUCTURAL SHEATHING (IF
SHEAR WALL) - SEE SCHEDULE
FOR SIZE/FASTENERS

Mechanical Engineer: HOVLAND'S HVAC
10954 E. Melby Street |Chippewa Falls, WI 54729
jhansen@hovlands-inc.com | 715.552.5595

MIN.

1/2" THICK SOUND

Electrical Engineer: PRISM DESIGN ELECTRICAL

E8403 State Rd 85 |Mondovi, WI 54755

bhalgren@prismdesign-electrical.com | 715.797.0602

19"/32" OSB PLYWOOD BONDED
W/ EXT. GLUE - PAINT DARK
GRAY

Plumbing Engineer: TAILORED ENGINEERING
1600 Aspen Commons | Ste 210 |Middleton, WI

4X6 SOUTHERN PINE - NO. 1 -
32" O.C. - PAINTED DARK GRAY

bnovak@tailoredeng.com | 608.209.7500

3 CORRIDOR JOISTS PARALLEL TO STAIR WALL

KNOCK OUT BOND BEAM - SEE
ELEVATOR ELEVATIONS FOR SIZE
AND REBAR
IF PLATE CONDITION, ATTACH
BOTTOM PLATE TO TRUSS W/16D
NAILS @ 12" O.C. TYPICAL

LEDGER AND FLOOR TRUSSES

2X8 LEDGER ATTACHED W/ (2)
STAGGERED 1/2" X 6 SIMPSON
TITEN HD ANCHORS @ 24" O/C
(3 5/8" MIN, EMBED)

WOOD FLOOR TRUSSES - SEE
PLANS

08.15.2019 75% CD Set
08.21.2019 Permit
11.07.2019 Updated Foundation
01.24.2020 Updates for Panelizer
02.07.2020 2nd Update for Panelizer
03.17.2020 Updated Stairs
03.27.2020 Updates
05.15.2020 Permit Revision #4
07.02.2020 Permit Revision #5
07.15.2020 Permit Revision #6
07.23.2020 Permit Revision #7

BLOCKING AS REQUIRED

ATTACH TRUSS TO DOUBLE TOP
PLATE W/ 16D FASTENERS @ 12"

DOUBLE TOP PLATE FOR FIRE
PROTECTION - SEAL ALL
PENETRATIONS

6 DETAIL- FLOOR FRAMING PARALLEL TO CMU WALL
FRAMING PLAN - 2ND FLOOR

CANNERY TRAIL RESIDENCES - 1750 N OXFORD AVE. - EAU CLAIRE, WI

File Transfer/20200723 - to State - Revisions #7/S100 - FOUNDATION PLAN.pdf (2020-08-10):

1 | 2 | 3 | 4 | 5

A

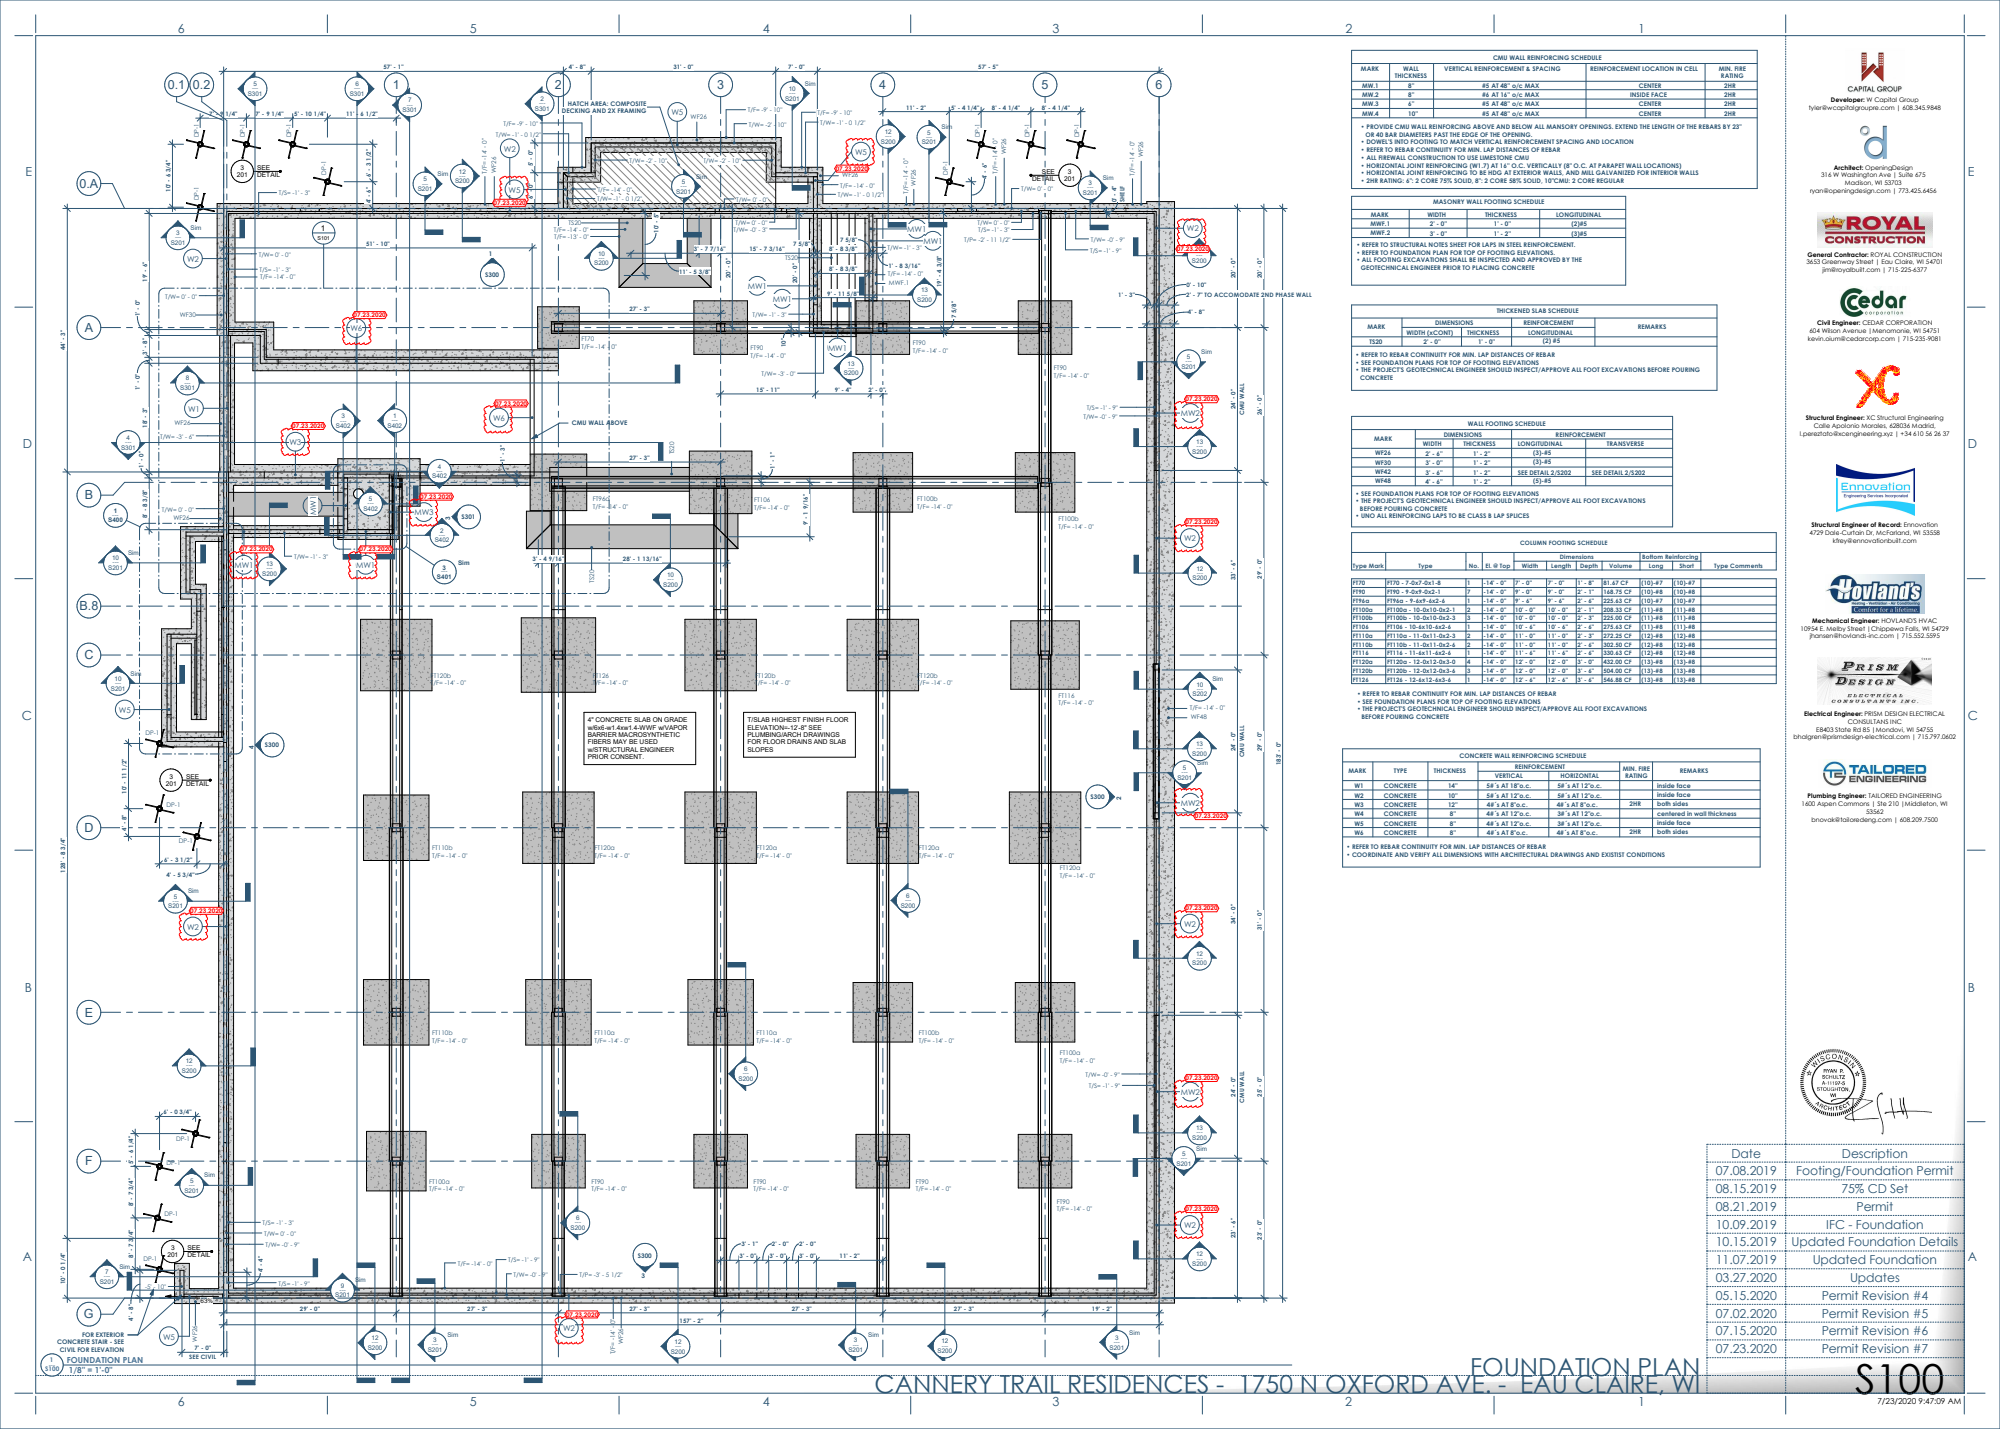
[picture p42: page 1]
SEE; DETAIL; T/F= -14' - 0" MWF.1; CMU WALL; SHELF; Sim; SEE CIVIL; FOR EXTERIOR; WIDTH; THICKNESS; LONGITUDINAL (2)#5; MWF.2; MARK; WALL; VERTICAL REINFORCEMENT & SPACING; REINFORCEMENT LOCATION IN CELL; #6 AT 16'' o/c MAX; INSIDE FACE; #5 AT 48'' o/c MAX; CENTER; MIN. FIRE RATING; DIMENSIONS; WIDTH (xCONT); LONGITUDINAL; REINFORCEMENT; REMARKS; TRANSVERSE; SEE DETAIL 2/S202; CONCRETE; VERTICAL; inside face; TYPE; HORIZONTAL 5#´s AT 12"o.c.; centered in wall thickness; both sides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

CMU WALL REINFORCING SCHEDULE

Developer: W Capital Group

HATCH AREA: COMPOSITE
DECKING AND 2X FRAMING

tyler@wcapitalgroupre.com | 608.345.9848

• PROVIDE CMU WALL REINFORCING ABOVE AND BELOW ALL MANSORY OPENINGS. EXTEND THE LENGTH OF THE REBARS BY 23"
OR 40 BAR DIAMETERS PAST THE EDGE OF THE OPENING.
• DOWEL'S INTO FOOTING TO MATCH VERTICAL REINFORCEMENT SPACING AND LOCATION
• REFER TO REBAR CONTINUITY FOR MIN. LAP DISTANCES OF REBAR
• ALL FIREWALL CONSTRUCTION TO USE LIMESTONE CMU
• HORIZONTAL JOINT REINFORCING (W1.7) AT 16'' O.C. VERTICALLY (8" O.C. AT PARAPET WALL LOCATIONS)
• HORIZONTAL JOINT REINFORCING TO BE HDG AT EXTERIOR WALLS, AND MILL GALVANIZED FOR INTERIOR WALLS

Architect: OpeningDesign
316 W Washington Ave | Suite 675

• 2HR RATING: 6": 2 CORE 75% SOLID, 8": 2 CORE 58% SOLID, 10"CMU: 2 CORE REGULAR

ryan@openingdesign.com | 773.425.6456

MASONRY WALL FOOTING SCHEDULE

MARK
MWF.1
• REFER TO STRUCTURAL NOTES SHEET FOR LAPS IN STEEL REINFORCEMENT.
• REFER TO FOUNDATION PLAN FOR TOP OF FOOTING ELEVATIONS.
• ALL FOOTING EXCAVATIONS SHALL BE INSPECTED AND APPROVED BY THE

General Contractor: ROYAL CONSTRUCTION
3653 Greenway Street | Eau Claire, WI 54701
jim@royalbuilt.com | 715-225-6377

GEOTECHNICAL ENGINEER PRIOR TO PLACING CONCRETE

2' - 7" TO ACCOMODATE 2ND PHASE WALL

THICKENED SLAB SCHEDULE

Civil Engineer: CEDAR CORPORATION
604 Wilson Avenue |Menomonie, WI 54751
kevin.oium@cedarcorp.com | 715-235-9081

• SEE FOUNDATION PLANS FOR TOP OF FOOTING ELEVATIONS
• THE PROJECT'S GEOTECHNICAL ENGINEER SHOULD INSPECT/APPROVE ALL FOOT EXCAVATIONS BEFORE POURING
CONCRETE

Structural Engineer: XC Structural Engineering
Calle Apolonio Morales, 628036 Madrid,
l.pereztato@xcengineering.xyz | +34 610 56 26 37

CMU WALL ABOVE

WALL FOOTING SCHEDULE

• THE PROJECT'S GEOTECHNICAL ENGINEER SHOULD INSPECT/APPROVE ALL FOOT EXCAVATIONS
BEFORE POURING CONCRETE
• UNO ALL REINFORCING LAPS TO BE CLASS B LAP SPLICES

Structural Engineer of Record: Ennovation
4729 Dale-Curtain Dr, McFarland, WI 53558

COLUMN FOOTING SCHEDULE

kfrey@ennovationbuilt.com

Mechanical Engineer: HOVLAND'S HVAC
10954 E. Melby Street |Chippewa Falls, WI 54729
jhansen@hovlands-inc.com | 715.552.5595

Electrical Engineer: PRISM DESIGN ELECTRICAL

4" CONCRETE SLAB ON GRADE
w/6x6-w1.4xw1.4-WWF w/VAPOR
BARRIER MACROSYNTHETIC
FIBERS MAY BE USED
w/STRUCTURAL ENGINEER
PRIOR CONSENT.

T/SLAB HIGHEST FINISH FLOOR
ELEVATION=-12'-8" SEE
PLUMBING/ARCH DRAWINGS
FOR FLOOR DRAINS AND SLAB
SLOPES

E8403 State Rd 85 |Mondovi, WI 54755

bhalgren@prismdesign-electrical.com | 715.797.0602

CONCRETE WALL REINFORCING SCHEDULE

Plumbing Engineer: TAILORED ENGINEERING
1600 Aspen Commons | Ste 210 |Middleton, WI

bnovak@tailoredeng.com | 608.209.7500

• COORDINATE AND VERIFY ALL DIMENSIONS WITH ARCHITECTURAL DRAWINGS AND EXISTIST CONDITIONS

07.08.2019 Footing/Foundation Permit
08.15.2019 75% CD Set
08.21.2019 Permit
10.09.2019 IFC - Foundation
10.15.2019 Updated Foundation Details
11.07.2019 Updated Foundation

Sim
CANNERY TRAIL RESIDENCES - 1750 N OXFORD AVE. - EAU CLAIRE, WI

CONCRETE STAIR - SEE
CIVIL FOR ELEVATION
1 FOUNDATION PLAN

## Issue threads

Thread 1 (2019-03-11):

Utility Room

theoryshaw, 2019-03-11:
*   Utility room on the north of the building, if coming on oxford than we should put next to oxford on west side of building.

    *   Hot water heaters will be in the utility room correct?

Closed 2019-04-30.

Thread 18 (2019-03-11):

redesign 2 bedrooms

theoryshaw, 2019-03-11:
*   Redesign the two bedrooms to flow better and have the living rooms on the corners not the bedrooms. You never get a second chance to make a first impression. We don’t want them to walk immediately into a wall when entering those units.

Closed 2019-04-30.

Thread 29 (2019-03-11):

Combine closets (currently back-to-back) in 1-bedroom units for a larger bedroom closet

theoryshaw, 2019-03-11:
Combine closets (currently back-to-back) in 1-bedroom units for a larger bedroom closet

theoryshaw, 2019-04-30:
fyi.. we switched these back to back/back... Didn't work that great the other way around.

Closed 2019-04-30.

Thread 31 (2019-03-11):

Studio transom

theoryshaw, 2019-03-11:
Translucent transom in studio, where the gap would be on the top of the wall facing the outdoor windows from living room. This will help a little more light to get through to the bedroom but also aid in the privacy. Furthermore, see if we can add a sliding “barn” door to the entrance of the studio bedrooms.

bdmock, 2019-03-14:
Is the transom the polycarbonate material?

theoryshaw, 2019-03-14:
you could put that as a placeholder, yes

theoryshaw, 2019-03-14:
you could make it a different 'type'.. so it's easy to swap, if and when it changes.

Closed 2019-10-28.

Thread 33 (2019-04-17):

Research on Modular Stairs

theoryshaw, 2019-04-17:
https://pacificstair.com/

chopinregis, 2019-04-17:
- email Tracy (vp of sales) from Pacificstair.com at tracy@pacificstair.com

chopinregis, 2019-04-17:
Scott Sullivan - Sales representative for WI
erectastep.com
843-359-8755
ssullivan@erectastep.com

--------------------------------
lapeyrestair.com
Ls.sales@LapeyreStair.com
504-733-6009

--------------------------------

chopinregis, 2019-04-17:
www.ezaccess.com/commercial
installed as needed
ksoyring@ezaccess.com
Kim Soy Ring
800 258 8503 option 3
takes either today or later in morning for a quote.

chopinregis, 2019-04-17:
Questions to ask about stairs to company rep
- commerical grade.. within a fire stair aka ehavy duty
- Are these stairs self supporting, or can they be supported off the CMU wall?
- Is there an ideal floor to floor dimensions?
- Are they welded or bolted?

chopinregis, 2019-04-18:
got a call from
Scott Sullivan - Sales representative for WI
erectastep.com
843-359-8755
ssullivan@erectastep.com

According to him his stairs are all modular, will be bolted, made of steel.
They do no provide anchoring specs, but if we need anchoring specs, he can get his engineers to design them for extra fees.
He will get the quotes by monday as Friday is public holiday.

Closed 2019-10-28.

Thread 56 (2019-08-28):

roof drainage

theoryshaw, 2019-08-28:
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

theoryshaw, 2019-08-28:
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

theoryshaw, 2019-08-29:
@chopinregis can you add roof drains to the roof plan?  You can use the same revit family that was used on the courtyard deck.

Also, please callout the 'OVERFLOW SCUPPERS' on the elevations, if they are not already called out.

Closed 2019-10-28.

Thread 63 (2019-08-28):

3 ADA stalls

theoryshaw, 2019-08-28:
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

Closed 2019-10-28.

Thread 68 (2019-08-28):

Type A - A471 - maneuvering clearance

theoryshaw, 2019-08-28:
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

bdmock, 2019-09-05:
Caused the creation of a new door type (3' width) with tag U18
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

theoryshaw, 2019-09-05:
no need to change the door. They mean this...
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

bdmock, 2019-09-05:
Then the unit doesn't have a closet, what about something like this?

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

theoryshaw, 2019-09-05:
have to say these ADA bathrooms are a PITA.
How about this?...
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

theoryshaw, 2019-09-06:
Let's do the overlap exception there, will removable cabinets doors.
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

Closed 2019-09-06.

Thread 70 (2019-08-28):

Type A - A471 - clear space at bathtub

theoryshaw, 2019-08-28:
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

bdmock, 2019-09-05:
Should we make this bath a one vanity bath, or scrunch the two together?

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

bdmock, 2019-09-05:
For the 1BD, what do you think of this approach?

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

theoryshaw, 2019-09-05:
How about this?...
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

theoryshaw, 2019-09-05:
How about this?...
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

theoryshaw, 2019-09-05:
Also, in general, let's not show the grab bars.  Let's just indicated there will be blocking in certain locations,  per that xx/xxx details we'll call out on the elevations.

Closed 2019-09-06.

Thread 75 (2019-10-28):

update top of wall details to accommodate lateral loads per conversation with Grant

theoryshaw, 2019-10-28:
@lcpt to provide updated sketch.

theoryshaw, 2019-10-28:
@lcpt to provide updated sketch.

lcpt, 2019-10-29:
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

There you have the modification for the details 3/S201 and 5/S201 to resist the lateral loads of the precast planks. The modifications are as follows:

- The bars drilled thru the precast planks are 2 inches (ca. 5 cm) longer to assure that the pass behind the longitudinal reinforcement (#4 horizontal bar in the sketch).
- There are two new #4 horizontal bars on the top of the wall. Those bars can resist the diaphragm forces introduced by the planks.
- The vertical hairpins become single bars of smaller diameter (#4→#3) because they don't connect the wall with the topping anymore. Two more #3 horizontal bars on this part of the wall ensure the concrete cracking control here.
- The wood framing walls are supported directly on the reinforced concrete.

theoryshaw, 2019-10-29:
Thanks Luis,
@chopinregis do you want to take a stab at updating 3/S201 and 5/S201?

theoryshaw, 2019-10-29:
@lcpt, can we put that top rebar 4" down from the top of the wall?

As you can see below, we're looking to hold the wall down 3" at the door locations.
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

chopinregis, 2019-10-30:
> Thanks Luis,
> @chopinregis do you want to take a stab at updating 3/S201 and 5/S201?

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

How do these look?

theoryshaw, 2019-10-30:
i'll markup in the FD.

lcpt, 2019-10-31:
Thanks @chopinregis. I've left my comments [here](http://dev.first-draft.xyz/d/20tj2lq4k.

Closed 2019-11-25.

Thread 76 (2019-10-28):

Beams and columns at north end of ramp.

theoryshaw, 2019-10-28:
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

anaiortega, 2019-11-06:
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

theoryshaw, 2019-11-06:
Thanks @anaiortega!

@chopinregis can you take a stab at detailing these out?

Start with putting the correct beams in the floor plans, at at the correct elevation.  Just put the beams in the floor plans, no details.

Next, you can model up these details.

Thx.

theoryshaw, 2019-11-06:
@chopinregis you don't have to put voids for bolts holes, you can use the following bolt family..
https://github.com/OpeningDesign/BIM_Objects/blob/master/Revit_Objects/06%20-%20Wood,%20Plastics,%20and%20Composites/050523%20-%20W_P_C%20-%20Fastenings%20-%20Lag%20Bolt%20or%20Thru%20Bolt.rfa

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
for this base plate you can use:
https://github.com/OpeningDesign/BIM_Objects/blob/master/Revit_Objects/05%20-%20Metals/051200%20-%20Structural%20Steel%20Framing/051200%20-%20Structural%20Steel%20Fr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
For this baseplate you can start a new family, from the (4) bolt family above.

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
for this angle, try to create a family like the previous ones.

theoryshaw, 2019-11-06:
Remember to try and avoid 'voids' and 'cuts'.. they don't translate in our Freemvd workflow.

https://github.com/OpeningDesign/FreeMVD_WorkFlow/blob/master/Workflow/Workflow.md

theoryshaw, 2019-11-07:
@anaiortega

Per the sketch below, how were you thinking this plate would engage the 8" concrete wall beyond?

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

anaiortega, 2019-11-07:
Sorry, do not go on with the modeling.  In this design, there are several geometrical and constructive incompatibilities that we must solve previously.

theoryshaw, 2019-11-07:
Sounds good.  We'll hold off.

theoryshaw, 2019-11-07:
Also, fyi, i changed the wall circled (red) below to 12" all the way up to accommodate that 10" wide base plate, if you still think that solution the best.

The other wall, however, circled in blue, is still 8" above.

Latest drawings submitted to GC: CTR\Transfer\20191107 - to GC -Updated Foundation

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

anaiortega, 2019-11-08:
Thickening the wall doesn't fix the problem, because, even if we'd place the hollow core over the steel beams, we still need some wall highness over the beam to allow room for the plate and upper anchors. We propose two possible solutions: the first one (option 1 in the sketch), by extending the steel beam over the RC wall; the 2nd (option 2) would be an RC solution, cantilevering a  concrete slab instead of the hollow-core.
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

theoryshaw, 2019-11-08:
Hi @anaiortega, could we do something like this?...
https://www.dropbox.com/s/q86os7e90j3yrsp/JQZYiraqAX.mp4?dl=0

This approach helps with fire separation too.

anaiortega, 2019-11-11:
All right then, we design the bearing plates and anchors for that solution.

anaiortega, 2019-11-12:
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
This is the detail for bearing the steel beams on the ramp walls. It replaces the detail depicted in section 2-2 of the sketches sent on 11/06.

theoryshaw, 2019-11-14:
Hi @anaiortega can we push these off center?  If so, what's the max delta?
Just want to create more 'fire separation' between the garage and the residences.

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

anaiortega, 2019-11-15:
Hi @theoryshaw ,
I'm not sure if I've understood the question right. In this approach, we have the steel column and the central beam (W14x53) in direct contact with the garage space, and, therefore, some kind of passive fire protection material must be applied. Isn't it possible to use the same coating for the lateral beams?. We have very little margin to push the beams off-center since the walls are 8" thickness and the beam flanges (W14x30) are 6.730" width. Perhaps we could give a try to change these last beams to a "C" profile, but not sure it's well-suited to the problem. Maybe, if it does not pose other constructive difficulties, to replace all the steel structure by a cast-in-place slab should work.

theoryshaw, 2019-11-15:
Thanks Ana!... we'll just go with what you have drafted.

theoryshaw, 2019-11-19:
@anaiortega

For those (2) end beams, can we use  w14x43's instead of w14x30's?

It has a wider flange, and will make welding more accessible, or easier to get at.  Also, provides a wider bearing.

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
****

anaiortega, 2019-11-19:
From a resistance standpoint, there is no problem, since the resistant capacity of the W14x43 is bigger than that of the W14x30. The only thing could be the clearance between the top of the hollow core and the top of the beam top flange (13.66-2*0.53*12=0.6""). Usually, the minimum clearance required in order to grout the topping is 3/4", so, in that case, the top of the hollow core should be dapped (the same applies to the central beam W14x53)

anaiortega, 2019-11-19:
(13.66-2*0.53-12=0.6"") *

Closed 2019-11-25.

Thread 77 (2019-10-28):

update foundation relative to new precast beam along south wall between C and D

theoryshaw, 2019-10-28:
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

theoryshaw, 2019-10-28:
we need Grant to size beam, first I would assume.

lcpt, 2019-10-28:
We can make some assumptions without having precise data about the lintel, but we cannot finish without them.

theoryshaw, 2019-11-05:
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

@lcpt is this what we want to propose to Grant?

lcpt, 2019-11-05:
Yes. Thanks Ryan.

theoryshaw, 2019-11-07:
Hi Luis, i would say this one is priority to finalize. Thx.

lcpt, 2019-11-07:
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
OK, I'll design this detail and draw the sketches of the whole thing.

theoryshaw, 2019-11-07:
Thanks Luis.

Can you also look at this?

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

lcpt, 2019-11-08:
Yes, I'm redefining the whole thing.

lcpt, 2019-11-11:
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

lcpt, 2019-11-11:
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

lcpt, 2019-11-11:
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

theoryshaw, 2019-11-11:
I think they formed and poured the footings already.

We might have to modify this relative to that.  Maybe a greater bearing distance than 1ft?

I think they are forming and rebaring the walls right now.

I just asked the GC for an update on where they are at.

theoryshaw, 2019-11-11:
Yes, the footings are all poured around the perimeter of the building.

So they have a WF48 along the entirely of that south wall with the following dimensions...

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

The south wall, however has not been formed or rebared yet, but they are going to do that shorty.

lcpt, 2019-11-12:
We can reinforce both faces of the wall in that zone and take advantage of the load diffusion on the wall:
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
I'll send you a sketch today.

lcpt, 2019-11-12:
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

Can we do this?

theoryshaw, 2019-11-12:
Yes, i think.  Thanks!

Closed 2019-11-15.

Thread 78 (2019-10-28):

Clarify corner cantilever condition.

theoryshaw, 2019-10-28:
Luis to provide OD with a clarifying sketch.

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

lcpt, 2019-11-14:
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
This is the solution I imagine for the cantilevers on the corners.

lcpt, 2020-01-09:
We adopted the solution proposed by Kurt. See 'Transfer/20191203 - from SEO - sketch of cantilever conditions'

Closed 2020-01-09.

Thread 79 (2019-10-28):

update the following details per the new change to concrete walls.

theoryshaw, 2019-10-28:
@lcpt to provide sketch to change the following details...

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

theoryshaw, 2019-10-31:
Hi @lcpt possible get these sketches by tomorrow?

lcpt, 2019-10-31:
Yes, I'm working on it.

lcpt, 2019-11-02:
[ramp_RC_wall_schedule.pdf](https://github.com/OpeningDesign/CTR/files/3800659/ramp_RC_wall_schedule.pdf)

Find attached the reinforcement schedule for the new RC walls for the ramp.

lcpt, 2019-11-02:
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
This is the detail for the wall on the west side (see plan view). The detail for the East wall will be very similar.

theoryshaw, 2019-11-03:
Hi Luis,
Could we simplify this detail with an steel angle, if necessary?  Something like the following image (with concrete obviously).
I just think this will be easier for the concrete sub, than forming that corbel--which would be a lot of form work.

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

---

Or maybe we could bear those 2nd floor trusses on the top of the concrete wall, so we wouldn't need this corbel (or steel angle) for load bearing.  We would only need a lateral connection at this point.

lcpt, 2019-11-04:
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
I've tried to explain the reason to put those corbels in the attached file. The formwork is more complicated but I don't find a simpler solution. I'll put an alternative solution here but I think it's not simpler than this one.

lcpt, 2019-11-04:
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

This is the solution I was talking about. The topping will be installed on a second phase so, if we want to use this detail it will need some modifications.

theoryshaw, 2019-11-04:
Good morning. Thanks for those sketches.

Ultimately defer to you on this.  But wanted to ask again, just to make sure.... a steel angle, like below, would not work in this condition?

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

lcpt, 2019-11-04:
No, it's not strong enough.

theoryshaw, 2019-11-04:
Okay, sounds good. Thx! We'll move forward with the corbel.

theoryshaw, 2019-11-04:
Just to ask the question.  How about using a 12" wall from the basement to 1st floor, and then an 8" wall from the 1st to the 2nd?
Would give us a 4" ledge to bear the precast on.
Could something like that work?

I just trying to head off GC's questions to simplify.

theoryshaw, 2019-11-04:
Also too, sorry.  Could we get the precast guys to size these planks to support these truss loads?  So we could do without the corbel and would only need a lateral connection at these points.

lcpt, 2019-11-04:
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

This could work.

lcpt, 2019-11-04:
> Also too, sorry. Could we get the precast guys to size these planks to support these truss loads? So we could do without the corbel and would only need a lateral connection at these points.

The truss loads are not a problem, the structural integrity of the planks at their connections with the ramp wall (as shown in the previous sketch) is. It was Grant who asked us to take care of this problem during our last telephone, so I think there is no chance they can help us.

theoryshaw, 2019-11-04:
> The truss loads are not a problem, the structural integrity of the planks at their connections with the ramp wall (as shown in the previous sketch) is. It was Grant who asked us to take care of this problem during our last telephone, so I think there is no chance they can help us.

Okay sounds good.  I'm going to ping Eric in here, to see if he has a preference between a 12" wall or a corbel.

Thanks, Ryan

theoryshaw, 2019-11-05:
from gc:
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

@lcpt, if you could, please move forward with a 12" wall, verses using a corbel.

lcpt, 2019-11-05:
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
OK. We'll remove the corbel and update the foundations and wall details.

lcpt, 2019-11-05:
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

theoryshaw, 2019-11-05:
Thanks Luis!  @chopinregis can you draft this up?  Keep the other corbel detail, however.

chopinregis, 2019-11-06:
> Thanks Luis! @chopinregis can you draft this up? Keep the other corbel detail, however.

Here is the update
https://71-thumbnail-images.first-draft.xyz/d/20191106_CTR_Structural_Detail/
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

theoryshaw, 2019-11-06:
@lcpt i took the first stab at markups.  We'll refine these and ping you later for a review.

lcpt, 2019-11-06:
OK.

Closed 2019-11-25.

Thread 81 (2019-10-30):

Update top of wall details around ramp

theoryshaw, 2019-10-30:
Hi @lcpt,
With the ramps walls concrete now, can you sketch up some amendments to the following details?

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

theoryshaw, 2019-10-31:
@lcpt ... also possible get these sketches by tomorrow?

lcpt, 2019-10-31:
Yes, we'll have it done by tomorrow.

lcpt, 2019-11-01:
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

theoryshaw, 2019-11-01:
@chopinregis want to take a stab at this detail?  Let's model this detail, per the others.  That is, instead of changing the line work of the existing detail.

lcpt, 2019-11-01:
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

chopinregis, 2019-11-03:
Hereis the Update
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
[http://dev.first-draft.xyz/d/20191102_CTR_Structural_Detail/](url)

lcpt, 2019-11-03:
Hi.

Those anchors are simply a piece of threaded steel drilled into the wall concrete and fixed with a resin. You can use a washer and a nut to fix the piece of wood.

On the other hand, I've put the 10" dimension in my sketches for the inverted U-shaped rebar I've placed at the top of the wall (Swiss style of reinforcing :). If you bend the vertical reinforcement  of the wall (which is also fine) you don't need those 10", you can cut the bar at the opposite corner as usual.

lcpt, 2019-11-05:
Concerning the wood piece under the ladder truss I think it must be thicker (1/2" more) to make sure there is risk of loosing support due to thermal actions.

On the other hand I'll search for the equivalent Titan screws to replace current anchors.

Closed 2020-01-27.

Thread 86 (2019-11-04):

Construction joints in basement walls.

lcpt, 2019-11-04:
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

anaiortega, 2019-11-04:
To control cracking in foundation walls, two types of joints are used:
- Vertical contraction joints (see detail 3/S200), spaced 25' at most.
- Vertical construction joints (see detail 4/S200) separating adjacent placements of concrete, that also work as contraction joints.
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

Closed 2019-11-20.

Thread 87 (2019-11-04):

Signage update

theoryshaw, 2019-11-04:
from owner:
>The official name of the community is going to be "The Current".
> Can you design signage on the top of the building facing east towards the river with the word "Current"? The letters would be large and blue and we would need spotlights shining on the letters so that it can be seen from across the river. The lights would be on a timer to turn on in the evening and off in the morning.

bdmock, 2019-12-20:
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

Closed 2020-01-27.

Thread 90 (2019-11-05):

Titan screw anchors at exterior wall

theoryshaw, 2019-11-05:
From GC:
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

theoryshaw, 2019-11-05:
Eric, I assume this is what you're looking at?...
https://www.strongtie.com/mechanicalanchors_mechanicalanchoringproducts/thd_anchor/p/titen-hd

@lcpt could you let Eric know the size/spacing for using titan screws in place of anchor bolts?

theoryshaw, 2019-11-05:
Just for clarity, i think Eric is talking about the condition below...

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

lcpt, 2020-01-23:
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

Closed 2020-01-23.

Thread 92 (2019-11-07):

lintels in elevator tower

theoryshaw, 2019-11-07:
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

anaiortega, 2019-11-14:
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

theoryshaw, 2019-12-27:
Hi Ana,

Hope you had a nice Christmas/Hanukkah/Kwanzaa break! :)

Now that we know what that precast beam will be through the elevator, I just wanted to verify what that lintel condition needs to be at the CMU wall.  See sketch below.

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

anaiortega, 2019-12-30:
Thanks, Ryan, wish you all the best for the new year.
In order to design a solution for this lintel, we need to know the stage of the construction at the present time, specifically if the concrete basement wall, column and CMU elevator wall are already built.

theoryshaw, 2019-12-30:
Hi Ana, only the footings for these areas are being formed, and poured.  They have not started on the ramp walls, or the concrete column near the elevator yet.

I would assume it will be formed how we design it.

anaiortega, 2020-01-03:
Hi Ryan,
For the lintel on the 1st floor, we are working on this kind of solution. Can you see any constructive problem?
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

theoryshaw, 2020-01-07:
Hi @anaiortega,

They don't make a CMU that size.

Since this CMU will be exposed to the finish space, would it be possible to do something like this?

http://dev.first-draft.xyz/d/20200107_Elevator_Lintels2/

As you saw from the GC's email this is probably priority now.

Thanks!

anaiortega, 2020-01-08:
Hi Ryan,
By no means we can reduce the column cross-section. Would it be possible to do something like this?
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

anaiortega, 2020-01-08:
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
Revision of sketch sent on Nov. 14, 2019. Revision clouds in blue.

theoryshaw, 2020-01-08:
> Hi Ryan,
> By no means we can reduce the column cross-section. Would it be possible to do something like this?
> 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

Yes, we can do something like this.  We'll draft it up.

theoryshaw, 2020-01-09:
Hi @anaiortega, can you review the following pdf?
CTR\Transfer\20200108 - to STRUCT - review of elevator elevation\CTR - elevator elevations.pdf

Thanks, Ryan

anaiortega, 2020-01-09:
Hi @theoryshaw,
Find attached my review
[20200109_elevator_lintels_review.pdf](https://github.com/OpeningDesign/CTR/files/4040811/20200109_elevator_lintels_review.pdf)

anaiortega, 2020-01-09:
Hi @chopinregis,
Find review of elevator elevation:
CTR\Transfer\20200109_toARCH_review_elevator_elevation\20200109_elevator_lintels_review.pdf

chopinregis, 2020-01-09:
thank you @anaiortega

anaiortega, 2020-01-14:
Hi @chopinregis ,
If you don't mind, please send me the plan for review when all the corrections are made.
Tanks, Ana

chopinregis, 2020-01-14:
> Hi @chopinregis ,
> If you don't mind, please send me the plan for review when all the corrections are made.
> Tanks, Ana

Hello @anaiortega
You will the drawings here
CTR\Transfer\20200114 - to STRUCT - Internal Review

anaiortega, 2020-01-14:
Thanks @chopinregis,
My review:
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

chopinregis, 2020-01-14:
hello @anaiortega , i've updated your markups, they are in the same folder as
CTR\Transfer\20200114 - to STRUCT - Internal Review

anaiortega, 2020-01-14:
Hi  @chopinregis,
the last detail was missing in the previous review
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

anaiortega, 2020-01-14:
> hello @anaiortega , i've updated your markups, they are in the same folder as
> CTR\Transfer\20200114 - to STRUCT - Internal Review

It's OK by me

chopinregis, 2020-01-14:
alright @anaiortega the 1st floor Lintel detail 4/S400 has been updated at same location
CTR\Transfer\20200114 - to STRUCT - Internal Review

anaiortega, 2020-01-15:
Hi @chopinregis . The checking of the 1st floor Lintel detail:
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

theoryshaw, 2020-01-15:
A 4" radius would touch the inside edges of the CMU block. Is that OK? Would 3" radius work?

---

  We fixed the cadding note on the latest drawing.

anaiortega, 2020-01-15:
It's 2" radius

theoryshaw, 2020-01-15:
Sorry, meant 4" diameter, would touch the outside edge of cmu..  That okay?

anaiortega, 2020-01-15:
Then 1 1/2" radius, 3" diameter will ok ;-)

theoryshaw, 2020-01-15:
Hi @anaiortega ,

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

---

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

anaiortega, 2020-01-15:
Hi @theoryshaw,
For the second one (9 ft), no problem.
For the first one (opening 60.5"), I think it will be ok, since the load is low. Nevertheless, I'll verify it tomorrow morning.

anaiortega, 2020-01-16:
Hi @theoryshaw ,
For the opening for louver, ok as well

anaiortega, 2020-01-16:
Hi @theoryshaw ,
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

If finally, the current design of the elevator shaft is viable for the elevator installation, we should add a couple of ties between the column and the 6" CMU wall to ensure the stability of the latter.

anaiortega, 2020-01-16:
On the other hand, I would like to add a bond beam under the opening for louver
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

Closed 2020-01-27.

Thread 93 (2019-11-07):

size steel angle and fasteners size/spacing at ada ramp

theoryshaw, 2019-11-07:
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

anaiortega, 2020-01-15:
Hi @chopinregis,
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

In this detail we should express the ramp thickness dimension, that is equal to 6"
Thanks

chopinregis, 2020-01-15:
@anaiortega is this what you mean?
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

anaiortega, 2020-01-15:
Yes, thanks @chopinregis !

anaiortega, 2020-01-20:
Hi @theoryshaw @chopinregis ,
Here  it's the detail for anchorage or the ADA ramp slab to the basement wall
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

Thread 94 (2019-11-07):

Detail of built up curb and floor

theoryshaw, 2019-11-07:
Need a detail of the condition below.

This is the GC's sketch.

@lcpt, Defer to you on best approach.

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

lcpt, 2019-11-12:
This is the reinforcement I propose for this element:
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

Concerning the structural filling at left, any lightweight structural filling will do. We can put a 6" EPS layer and the 3" topping over it.

theoryshaw, 2019-11-21:
@lcpt what psi EPS insulation would you recommend under the topping?

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

theoryshaw, 2019-11-22:
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

Also, what's the O.C. spacing of that?

lcpt, 2019-11-22:
Sorry it was #4 1'-0" o/c. I've not calculated its length but an embedment of 8 inches (ca. 20 cm) will be enough.

lcpt, 2019-11-24:
> @lcpt what psi EPS insulation would you recommend under the topping?
>
> 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
40 psi will do.

theoryshaw, 2019-11-24:
Can 25psi work?

lcpt, 2019-11-25:
Not really. The elastic modulus of the EPS drops with its compressive strength, and we a have a relatively thick (6 inches (ca. 15 cm)) EPS layer. If we put a softer material we risk having some cracks in the topping.

lcpt, 2019-11-25:
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

Closed 2019-11-25.

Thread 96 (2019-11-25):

Please provide a detail for how holddowns will connect to the plank.

theoryshaw, 2019-11-25:
From Precast supplier

> Please provide a detail for how holddowns will connect to the plank.  Attached is a detail we have used on similar projects.

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

lcpt, 2019-12-03:
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

theoryshaw, 2019-12-03:
Thanks Luis,

Are you suggesting the contractor can choose from the following 3 hold down options?

- Simpson hdu4
- Simpson hd19
- Simpson hdu4-sds2.5

Thanks, Ryan

theoryshaw, 2019-12-03:
Nevermind, i see they are referenced back to the shear wall schedule.
Thanks.

lcpt, 2019-12-03:
Correct.

Closed 2020-01-22.

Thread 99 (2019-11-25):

Lintel condition at east intake.

theoryshaw, 2019-11-25:
October 8th sketch from @anaiortega

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

Photo a couple days ago...

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

Proposed sketch..

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

Existing condition...

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

lcpt, 2019-11-26:
Sorry, it's my fault. Ana has explained to me that you have made a change for this lintel and yesterday I've picked the old version sketch. The good one is the sketch sent by Ana you have put in first place.

lcpt, 2019-11-26:
On the other hand, in the photo the three rebars at bottom seem too tight together, maybe it's only the perspective.

Closed 2019-11-26.

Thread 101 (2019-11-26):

Review precaster's details at south wall beam

theoryshaw, 2019-11-26:
Details:
CTR\_closed_cannery district - eau claire\Building Products\03 - Concrete\03 40 00 Precast Concrete\20191126 - from Precast Eng - Details at Precast Beam - for review

from precast supplier

> Here is the connection design for the exterior LB beam along grid 6 at the knock-out cmu wall. Please review and comment if needed.

> Take note of the top of CIP pier elevation and the cip blockout to accommodate beam height and beam bearing distances.

> Also note the required 1” gap joint from beam end to cip wall edge. All this maintains the 24’-0” clear i.s. to i.s. at the temporary cmu wall opening.

theoryshaw, 2019-11-26:
@lcpt i'll take an initial stab at reviewing.

theoryshaw, 2019-11-27:
@lcpt

Here's my review...
CTR\_closed_cannery district - eau claire\Building Products\03 - Concrete\03 40 00 Precast Concrete\20191127 - from ARCH to STRUCT - reviewed precast beam details\20191127 - precast beam at south wall - OD reviewed.pdf

If you can, please take a quick review as well.

Thanks, Ryan

lcpt, 2019-11-27:
OK. I'll do it now.

lcpt, 2019-11-27:
Here's mine:

_CLOSED_Cannery District - Eau Claire/Building Products/03 - Concrete/03 40 00 Precast Concrete/20191127 - from STRUCT to ARCH - reviewed precast beam details

Closed 2019-11-27.

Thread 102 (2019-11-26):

1st floor wall at the south of the ramp

theoryshaw, 2019-11-26:
@lcpt Possible to sketch up the condition below?

The precast supplier was asking.

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

lcpt, 2019-11-27:
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
I think this can work.

theoryshaw, 2019-11-27:
Thanks Luis, do we need starter rebar drilled into the plank, that would extend up into the RC wall?

lcpt, 2019-11-27:
The wall doesn't need to bear into the precast floor which, in turn is not intended to support the wall. If we join them we don't master the way they work. I think it's better to let them "mechanically" apart.

theoryshaw, 2019-11-27:
i gotcha, so that RC wall is a big beam essentially.

theoryshaw, 2019-11-27:
I have a feeling, however, they might want to use CMU at this condition.

lcpt, 2019-11-27:
Yeah, it's a big beam which help us resist horizontal forces coming from 1st floor too. I feel very comfortable having this RC wall there :). Specially after all the discussions about the topping and the diaphragm forces with Reigstad.

theoryshaw, 2019-11-27:
Sounds good. We'll push for that then. Thanks!

Closed 2019-11-27.

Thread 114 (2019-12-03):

Shear wall near gridline (2) at 2nd and 3rd floor

theoryshaw, 2019-12-03:
@lcpt,
Did you intend for the wall, circiled below, at the 2nd and 3rd floors, to a shear wall?

There is no shear wall at that location on the 1st floor, because of the community room.

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

lcpt, 2019-12-04:
My idea is (and was) to attach it to the south wall of the ramp: EC1A
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

theoryshaw, 2019-12-13:
sounds good.  Will the attachment at that condition circled below be unique?  Or just called out in the shear wall schedule?
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

lcpt, 2019-12-16:
I think it's enough to call it out on the shear wall schedule.

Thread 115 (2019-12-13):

(non-bearing) party walls between the units go with 2x6's 24" o.c.?

theoryshaw, 2019-12-13:
Hi @lcpt,

At the (non-bearing) party walls between the units, the GC was wondering if they could go with 2x6's at 24" o.c.

Okay?

Thanks, Ryan
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

lcpt, 2019-12-16:
OK for those that are not shear walls:
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

Closed 2020-01-16.

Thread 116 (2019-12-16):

Stud spacement in shear walls S2A and S2B

lcpt, 2019-12-16:
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
There is an error in the bearing wall schedule for those walls in the second floor. The spacing there must be 12 inches (ca. 30 cm):

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

theoryshaw, 2019-12-17:
sounds good.  Will update plans.

Closed 2020-01-27.

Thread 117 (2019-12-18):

(2) 2x12's rim boards for the floor trusses

theoryshaw, 2019-12-18:
@lcpt

Instead of LVL rim boards for the floor trusses, the GC would like to use (2) 2x12's instead.

Would this be okay?

lcpt, 2019-12-19:
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

As you can see it's not a standard design. I think it's not a good idea.

theoryshaw, 2019-12-19:
...as you would expect from a institution for engineered wood, would say. ;)

lcpt, 2019-12-19:
Yeah, it's not always a good idea to ask your hairdresser if you need a hair cut. But it's also true that the shear stress can't go through the joint between the panels. You can always make a calculation like the one we did for the corridor joists to see what happens but this takes time...

Closed 2019-12-30.

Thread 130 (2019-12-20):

Changes in 2bd

theoryshaw, 2019-12-20:
Master Bath in 2BD
- change tub to shower
- remove door from hallway to master bath
- remove small linen closets (convert this space to an alcove next to the unit's entry)

Smaller Bath in 2BD
- change shower to tub
- add door from hallway to bath
- remove small linen closets

bdmock, 2020-01-04:
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
(pg 9 https://www.bozeman.net/Home/ShowDocument?id=60)

bdmock, 2020-01-04:
The bozeman document shows this as the only option for showers in the Type A bathrooms

bdmock, 2020-01-04:
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

This seems the way to go. Am I right in thinking so?

bdmock, 2020-01-04:
at least in the Type A 2bd master bath

theoryshaw, 2020-01-04:
I think we can get away with this...

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

---

1.
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

bdmock, 2020-01-04:
http://dev.first-draft.xyz/d/20191230_CTR_Unit_Revisions/

bdmock, 2020-01-04:
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
The smaller bath doesn't really allow for a forward door approach to the hallway door.

bdmock, 2020-01-04:
http://dev.first-draft.xyz/d/20200104_CTR_Unit_Revisions/

Closed 2020-01-27.

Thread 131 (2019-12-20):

Relocate washer/dryer

theoryshaw, 2019-12-20:
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

https://www.dropbox.com/s/cnkkv1c6n295w4p/bxKC83saIB.mp4?dl=0

Do this for all the STs on all the floors

bdmock, 2019-12-20:
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
Can you catch the view template adjustment? It's not supported in LT.

theoryshaw, 2019-12-20:
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

haha

Closed 2020-01-27.

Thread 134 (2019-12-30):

hold down detail at shear wall at Grid 1, 0-A.1

theoryshaw, 2019-12-30:
hold down detail at shear wall at Grid 1, 0-A.1

lcpt, 2020-01-02:
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
This is the sketch sent by Grant. The wall is already poured, isn't it?

theoryshaw, 2020-01-02:
Yes it is poured.

lcpt, 2020-01-10:
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

theoryshaw, 2020-01-10:
seems good to me. Were you planning on forwarding this to Grant?

lcpt, 2020-01-13:
I sent it Friday evening.

Closed 2020-01-13.

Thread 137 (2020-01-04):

update the plans relative to speced washer/dryer

theoryshaw, 2020-01-04:
heres' the specs..
CTR/_closed/Products/22 - Plumbing/224000 - Plumbing Fixtures/Stacked Washer Specs.pdf

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

theoryshaw, 2020-01-04:
you need to create a new door type too.

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

The offset pivot doors probably won't make the budget, but let's propose this for now.

bdmock, 2020-01-04:
ok

theoryshaw, 2020-01-04:
Probably makes sense if that's a 2x6 wall.
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

bdmock, 2020-01-07:
Swept through all units

Closed 2020-01-27.

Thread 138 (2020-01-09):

South basement wall infill reinforcement.

lcpt, 2020-01-09:
The vertical reinforcement of the CMU walls doesn't reach the CIP lintels.

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

theoryshaw, 2020-01-14:
On that email with the GC, they indicated they did include the vertical reinforcing at that location. I would assume we just need to work on a detail at the CMU and concrete interface.  Similar to this one...

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

lcpt, 2020-01-20:
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
If the vertical reinforcement has not been extended into the top of the wall (see image) we'll need to find some other way to transfer the loads to the first floor.

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

The problem with the steel angle solution is that we don't have the HSS struts which transfer the horizontal loads from the CIP lintel bottom to the precast planks.

anaiortega, 2020-02-10:
Hi @theoryshaw ,
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

The two lateral retaining basement walls in the South façade have been modelled supposing the stem laterally supported at the top and fixed at foundation (it acts as a fixed-pin beam). The earth pressure is applied using the at-rest Ko coefficient and surcharge loads are acting on it. To adopt this structural behavior assumption, the vertical section of the wall must be continuous in order to transfer horizontal loads to the precast slab, so the wall can be considered restrained at the top.

For the way in which it has been built, continuity is broken between the CMU wall and the lintel, since the reinforcement of the blocks has not been extended through the concrete lintel. It forces the CMU structure to work as a cantilevered wall, which is much unfavourable than the working hypothesis for which it has been designed.

The proposed solution is to build a new CMU wall on the side in contact with the ground, whose height extends from the foundation to the precast slab level. The contact with the existing wall and lintel is provided at slab-on-ground and precast-slab levels to ensure the transfer of loads to those elements.

anaiortega, 2020-02-11:
Hi Ryan,
Find sketched two possible solutions to transfer the loads to the precast planks from the South CMU basement walls. The first one can raise the problem of interference between anchors and the lintel bottom reinforcement, so, if selected, we should probably use a WT profile with a wider wing. We also must size the anchorage once the solution is established.
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

anaiortega, 2020-02-11:
Hi Ryan,
Find sketched two possible solutions to transfer the loads to the precast planks from the South CMU basement walls. The first one can raise the problem of interference between anchors and the lintel bottom reinforcement, so, if selected, we should probably use a WT profile with a wider wing. We also must size the anchorage once the solution is established.
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

theoryshaw, 2020-02-11:
Thanks Anna. Don't forget the CMU is 8" and the concrete wallowings 10" so we have a 2" gap on the inside of the wall

theoryshaw, 2020-02-11:
A 2 3/8" offset to be exact.

anaiortega, 2020-02-11:
OK, thanks

anaiortega, 2020-02-12:
Hi @theoryshaw
Here's the detail
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

theoryshaw, 2020-02-12:
I just found out that the top of grade will be 3ft below the courtyard elevation.  If that be the case, can we do away with these struts all together?  Could we just do something like this?...

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

There was a lot of growning on the site yesterday when I brought up this detail, even though they knew it was coming.

anaiortega, 2020-02-12:
I'm not very confident about that solution. Even if we can size the structural elements to meet the standards with that ground level, I think it's risky to assume that in the future the filling does not reach the top of the wall. We'll try to imagine another solution without affecting the precast.

theoryshaw, 2020-02-12:
If we have to put the structs in, so be it, but just wanted to ask the question--the gc would be happy if we could eliminate the structs.

anaiortega, 2020-02-13:
Hi @theoryshaw,
Sorry, we see no options other than:
- install another resisting wall (CMU, corrugated steel sheet, ...) on the side in contact with the ground. As it should almost reach the courtyard elevation, the solution is not very aesthetic if the ground level is 3 ft below.
- Install the struts as represented in the detail above.

theoryshaw, 2020-02-13:
@anaiortega sounds good.  Can I send your following sketch to the GC?...

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

anaiortega, 2020-02-13:
Yes, thank you
Le jeu. 13 févr. 2020 à 19:09, Ryan Schultz <notifications@github.com> a
écrit :

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

Closed 2020-02-14.

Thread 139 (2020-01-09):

Ramp wall corner detail

lcpt, 2020-01-09:
The reinforcement at the corner as represented in the plan was wrong.

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

lcpt, 2020-01-13:
[Z-03-Ramp_South_Wall-Additional_Rebar.pdf](https://github.com/OpeningDesign/CTR/files/4054235/Z-03-Ramp_South_Wall-Additional_Rebar.pdf)

lcpt, 2020-01-13:
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

The size of the fillet weld must be 1/4" or greater.

Closed 2020-01-13.

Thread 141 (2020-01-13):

Detail 6 on S215: height of the double plate.

lcpt, 2020-01-13:
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

Jeff Holm: "_detail 6 on S215 will need to be clarified as well, I do not see an actual height of the double top plate on the partially flush beam._"

lcpt, 2020-01-13:
This double plate is simply the double plate that runs over all the wall studs. Am I missing something?

theoryshaw, 2020-01-14:
I'm not sure either.

If we can, however, I think we should do something like this instead.

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  That is, instead of 'tucking' the header up into the truss.

Thanks, Ryan

lcpt, 2020-01-15:
OK, I agree.

Closed 2020-01-25.

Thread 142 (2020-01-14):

Design W-section under 2nd floor trusses at the following locations...

theoryshaw, 2020-01-14:
Design W-section under 2nd floor trusses at the following locations...

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

lcpt, 2020-01-18:
We can use a W16X57 for both beams.

theoryshaw, 2020-01-18:
Thanks Luis, possible to use a thicker W12 here?

We could use the head room, if possible.

theoryshaw, 2020-01-18:
Or a W14, if that's not possible.

lcpt, 2020-01-19:
> Thanks Luis, possible to use a thicker W12 here?
>
> We could use the head room, if possible.

Yes W12X87. In both cases (W12 or W16) the beams must be continuously braced. I would like to check the modified drawings.

theoryshaw, 2020-01-19:
Thanks, yes, I plan having you review the entire set in the next couple days.

Can you provide a sketch on what you mean by this cont. bracing?

lcpt, 2020-01-19:
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
The horizontal displacement of the upper flange must be constrained as in the picture (for example) to prevent lateral buckling.

theoryshaw, 2020-01-19:
I guess i'm still not following.

With the W12x87 we have this conditon, so far... (disregard the garage door spring)

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

lcpt, 2020-01-19:
Ah, OK. They go under the trusses. We need to attach the upper flange of the steel beam to the lower chord of the trusses. I'll seek for a suitable detail.
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

theoryshaw, 2020-01-19:
sounds good

anaiortega, 2020-01-22:
Hi @theoryshaw ,
We could use this kind of connectors:
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
http://advancedstructuralconnectors.com/product/ccqeccq-column-caps/

theoryshaw, 2020-01-22:
Below is how it's typically done, where a wood 2x sill is attached to the beam, and then the truss is attached to the sill.

Welding is too cumbersome and expensive.

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

theoryshaw, 2020-01-23:
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

anaiortega, 2020-01-23:
Yes, the idea of that solution with steel connectors was to minimize the total beam height so as not to take up more head room.

anaiortega, 2020-01-23:
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

Closed 2020-01-25.

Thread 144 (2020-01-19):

LVL near ramp on 2nd floor

theoryshaw, 2020-01-19:
@lcpt

This following beam circled below, seems undersized.  Can you verify?

Thanks, Ryan
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

theoryshaw, 2020-01-20:
This one seems undersized too, as it's bearing the 3rd and rooftop trusses through the 2nd and 3rd floor corridor walls.

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

lcpt, 2020-01-24:
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

There is a door over this header on the 3rd floor but I agree that it's better to make it more robust: 5.25×14"

lcpt, 2020-01-24:
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

Yes it was undersized. We can use also a  5.25×14" LVL header.

Closed 2020-01-25.

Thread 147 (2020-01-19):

Modify corridor floors assembly composition.

lcpt, 2020-01-19:
[20200117_0444_Ryan2Luis_corridor_floors.pdf](https://github.com/OpeningDesign/CTR/files/4083220/20200117_0444_Ryan2Luis_corridor_floors.pdf)

lcpt, 2020-01-20:
We can use 4x6 pine joists as follows:
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

theoryshaw, 2020-01-20:
Cool. Thx!  Are you still working on the substrate layer sandwich?

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

lcpt, 2020-01-20:
> Cool. Thx! Are you still working on the substrate layer sandwich?
>
> 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

Yes. For the structural point of view I prefer the first sandwich. But, on the other hand, I need to check the strength of the OSB panels. I'm currently working on this.

lcpt, 2020-01-21:
> Cool. Thx! Are you still working on the substrate layer sandwich?
>
> 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

Hi Ryan. In those sandwiches there is a missing OSB layer. We checked the floor sheathing with three 19/32 structural plywood layers:
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

theoryshaw, 2020-01-21:
Thats the question, essentially, can we go down to 2 layers? Perhaps (2) 3/4" layers? The gyp crete provides some fire resistant in these sandwiches, as well.

lcpt, 2020-01-21:
OK. Understood.

lcpt, 2020-01-21:
Then we need to put the Gypcrete between the two structural layers, otherwise there is no bearing layer in case of fire.

theoryshaw, 2020-01-21:
Sounds good.  If we do the following what's the minimum size of the OSB?

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

lcpt, 2020-01-21:
We can use a 19/32 OSB panel with the following design capacities:

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

theoryshaw, 2020-01-21:
Okay.  so to summarize...

We can do?...

4x6 no. 1 pine joists 32" o.c. with the following sandwich...
- 19/32" osb spanning 32" oc.
- 3/4" gyp crete
- acoustical mat
- 19/32" osb spanning 32" oc.

lcpt, 2020-01-22:
Yes, as long as the OSB panels have the capacities showed above.

theoryshaw, 2020-02-12:
@lcpt,

In our previous assembly, we had the following sandwich....

- 3/4" gyp crete
- acoustical mat
- 19/32" osb spanning 32" oc.
- 19/32" osb spanning 32" oc.
- 19/32" osb spanning 32" oc.

Is there anyway to go down to 2 layers like the following?...

- 3/4" gyp crete
- acoustical mat
- 3/4" (or thicker, if need be) osb spanning 32" oc.
- 3/4" (or thicker, if need be)  osb spanning 32" oc.

Sorry to ask this again, but the GC has expressed concerns on the constructability of the following sandwich

- 19/32" osb spanning 32" oc.
- 3/4" gyp crete
- acoustical mat
- 3/4" osb spanning 32" oc.

With this assembly, they would put that first layer of 3/4" down, and that would be the only sheathing during construction.  They are worried about large concentrated loads during construction, such as a cart full of drywall.

They also indicated that that top layer of 19/32" would be hard to nail down through the gyp. crete.

---

It would be ideal to do the following sandwich...

- 3/4" gyp crete
- acoustical mat
- 3/4" (or thicker, if need be) osb spanning 32" oc.
- 3/4" (or thicker, if need be)  osb spanning 32" oc.

..but if it's not possible to us (2) layers of OSB, I think we should just go back the following then.

- 3/4" gyp crete
- acoustical mat
- 19/32" osb spanning 32" oc.
- 19/32" osb spanning 32" oc.
- 19/32" osb spanning 32" oc.

lcpt, 2020-02-13:
Hi Ryan.

You can use:

- 3/4" gyp crete
- acoustical mat
- 1 1/8" osb spanning 32" oc.

or go back to the initial solution:

3/4" gyp crete
acoustical mat
19/32" osb spanning 32" oc.
19/32" osb spanning 32" oc.
19/32" osb spanning 32" oc.

lcpt, 2020-02-13:
We need to adapt detail 4/A800 consequently.

Closed 2020-02-14.

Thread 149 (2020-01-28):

Steel at precast cantilever

anaiortega, 2020-01-28:
Eliminate stiffener plate and replace bolts with full weld

anaiortega, 2020-01-28:
It's possible to eliminate the stiffener plates in the beam over the column, but only in the case that no other loads except the precast self-weight are  acting on the cantilever or the precast slab before the grout is in place.
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

lcpt, 2020-01-28:
It's also possible to weld the plate to the bottom web of the beam. You can also reduce the plate dimensions to 9×9 inches to leave some space to the weld bead.

Closed 2020-01-28.

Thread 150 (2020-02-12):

Callout the base/top plates for the remaining steel.

theoryshaw, 2020-02-12:
Callout the base/top plates for the remaining steel.

http://dev.first-draft.xyz/d/20200212_2nd_Floor_Steel/

theoryshaw, 2020-02-12:
I think we should sketch out the base plates, but I think we can just call out, with notes in a schedule, what the top plates (size, bolts, etc) are, as well as the the intersection of these steel next to the cantilever.

(just trying to save us time having to model up every single detail.  We can lean on the structural shops to draft these connections up, and we can review)

anaiortega, 2020-02-17:
Hi @theoryshaw ,
Here is the sketch
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

theoryshaw, 2020-02-17:
Thanks Ana, were you planning to sketch out the base plate conditions called out here?

http://dev.first-draft.xyz/d/20200212_2nd_Floor_Steel/

anaiortega, 2020-02-17:
Correction to previous sketch: all cap plates are 10x14x3/4
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

anaiortega, 2020-02-17:
I send the base plates in a few minutes

anaiortega, 2020-02-17:
All base plates are:
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

theoryshaw, 2020-02-17:
Can you coordinate your suggested base plate dimensions with the existing conditions of the curb and precast offset.

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

anaiortega, 2020-02-19:
Base plates North façade
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

anaiortega, 2020-02-19:
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

anaiortega, 2020-02-20:
Hi @theoryshaw ,
Can this be a suitable alternative?
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

theoryshaw, 2020-02-20:
Yes, this works.  Thanks.

theoryshaw, 2020-03-04:
okay.

Closed 2020-02-20.

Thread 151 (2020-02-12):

Head detail at walls between the corner 2bd units

theoryshaw, 2020-02-12:
Luis,
At those walls between the corner 2bd units, could we do something like the following?...

We're just trying to accommodate some large pipes that run up these walls.

Thanks, Ryan

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

lcpt, 2020-02-13:
If I'm not wrong those are the south facade shear walls.
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
There we need the rim board to transfer shear between floors, so we need it attached to walls above and below. We'll need to find another solution.

theoryshaw, 2020-02-13:
i think we'll just do a furred out plumbing wall, and be done with it.
Thanks.

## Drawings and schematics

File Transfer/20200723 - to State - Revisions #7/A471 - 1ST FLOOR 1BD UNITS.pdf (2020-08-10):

E
E

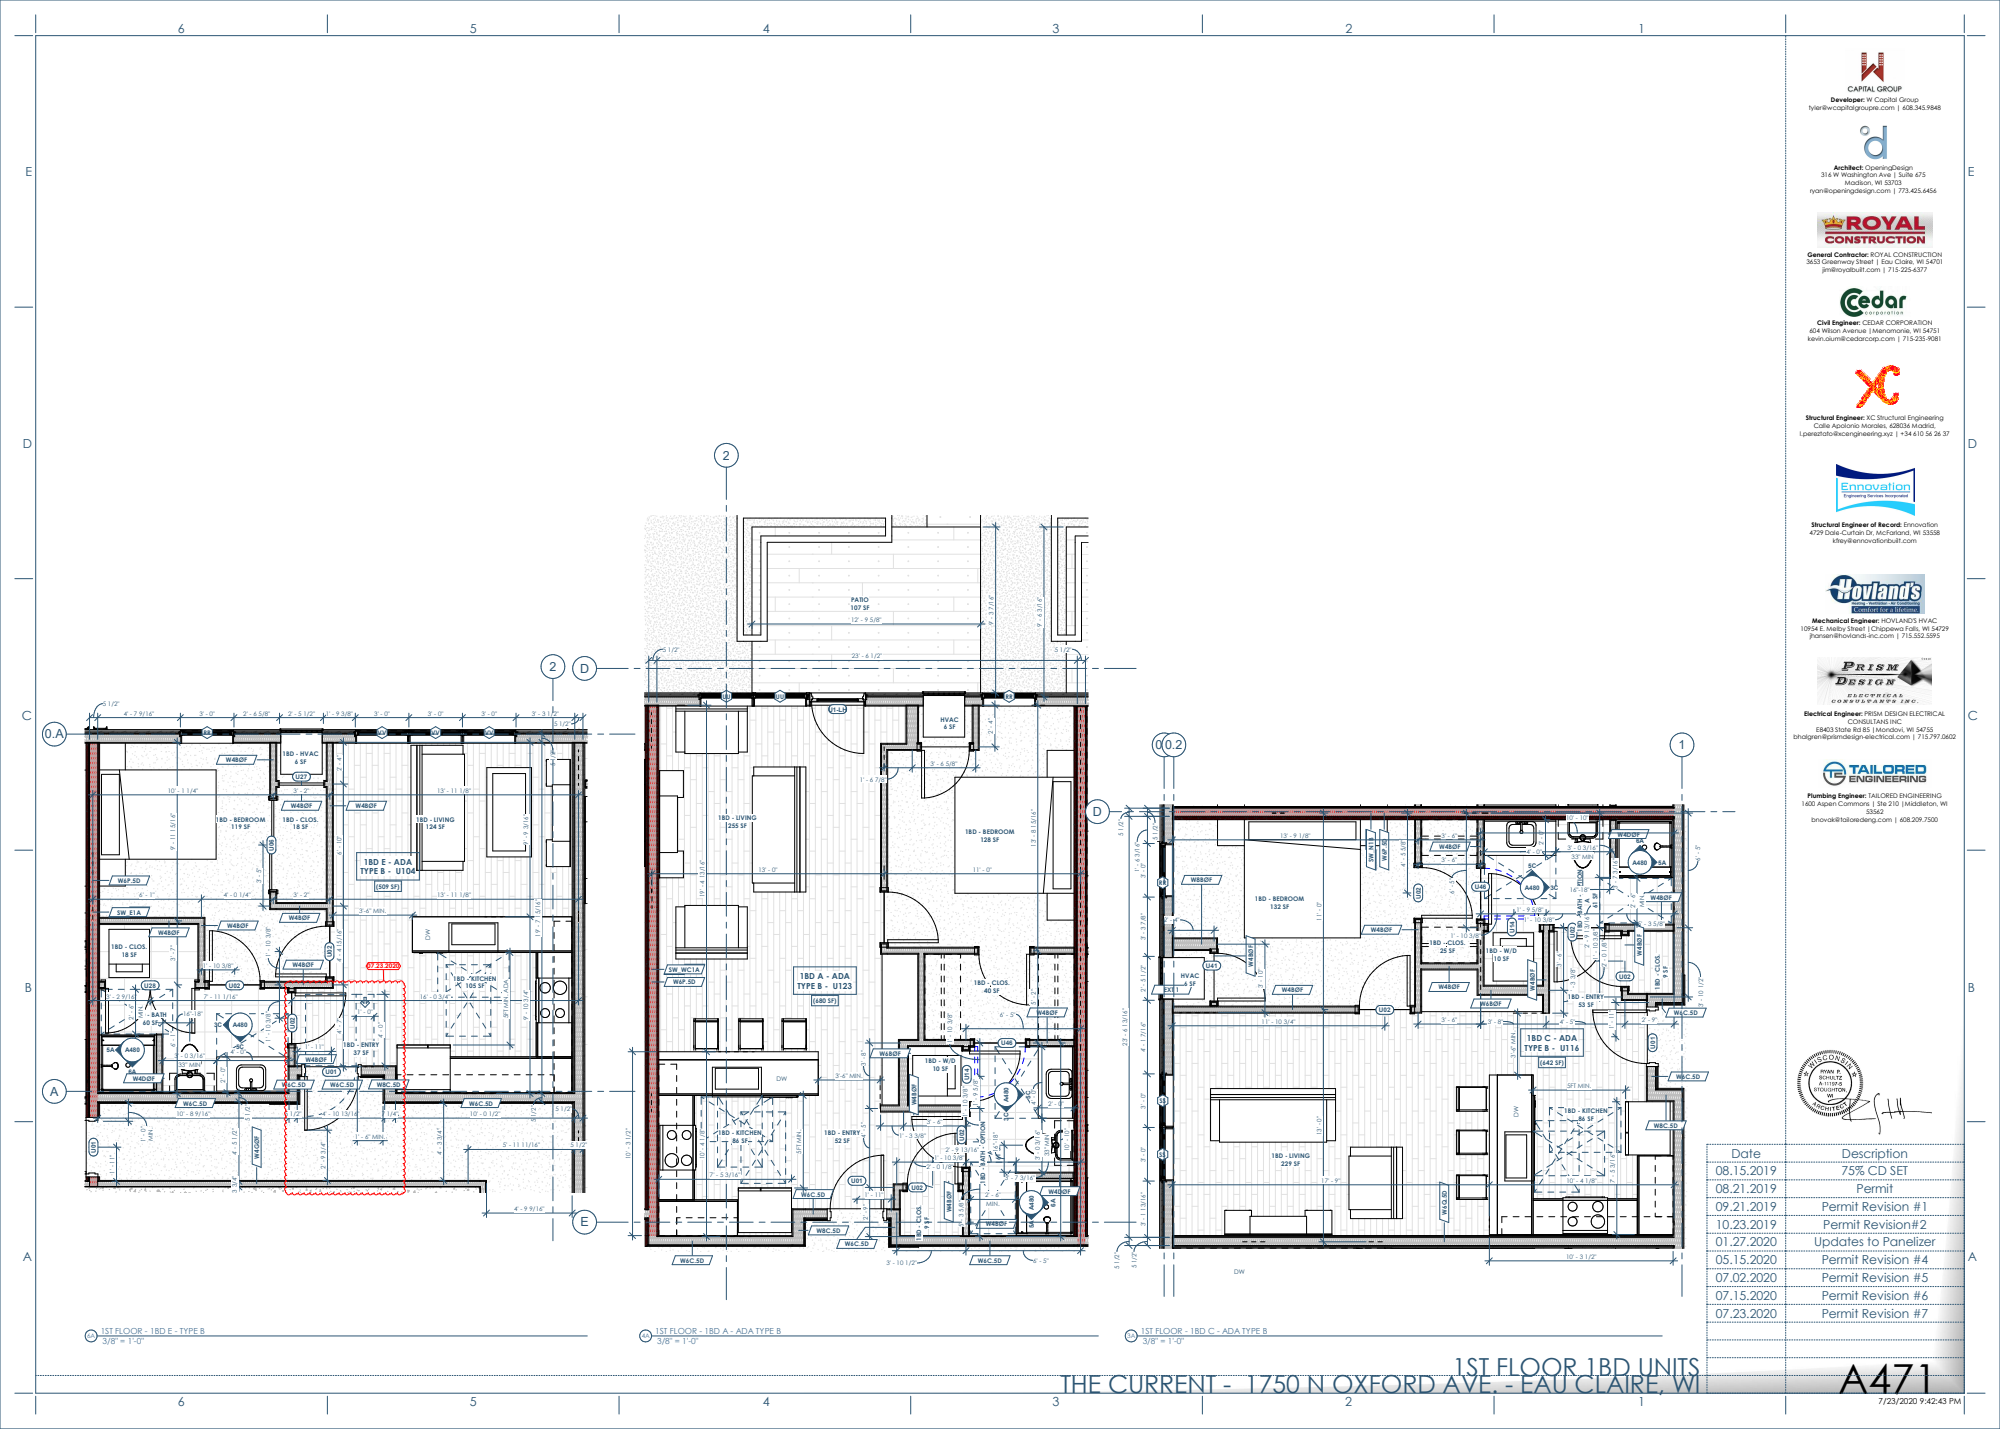
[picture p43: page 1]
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

Structural Engineer of Record: Ennovation
4729 Dale-Curtain Dr, McFarland, WI 53558

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

Electrical Engineer: PRISM DESIGN ELECTRICAL

E8403 State Rd 85 |Mondovi, WI 54755

bhalgren@prismdesign-electrical.com | 715.797.0602

Plumbing Engineer: TAILORED ENGINEERING
1600 Aspen Commons | Ste 210 |Middleton, WI

3/8" = 1'-0" ⁴A 1ST FLOOR - 1BD A - ADA TYPE B

THE CURRENT - 1750 N OXFORD AVE. - EAU CLAIRE, WI

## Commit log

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2019-05-20 exploded backgrounds to the electrical engineer
    [CTR - 1st Phase - Common Walls-Sheet - A100 - FLOOR PLAN - BASEMENT.dwg, CTR - 1st Phase - Common Walls-Sheet - A101 - FLOOR PLANS - 1ST FLOOR.dwg, CTR - 1st P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]
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2019-06-03 sketches/DWG from Precast Manu. -- Also OD question back to them.
    [Ultra Span Sections for Shop Drawings.dwg]
2019-06-05 Enlarged floor plans added, RCP plans deleted, 4 new wall sections added to show polycarbonate and a few other small tweaks
    [Starter Elevation.dwg]
2019-06-05 hopefully fixing git-crypt hiccup.
    [Starter Elevation.dwg]
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2019-06-11 20190611 - to ALL - 25% progress set
    [20190611 - CTR-Sheet - A100 - FLOOR PLAN - BASEMENT.dwg, 20190611 - CTR-Sheet - A101 - FLOOR PLANS - 1ST FLOOR.dwg, 20190611 - CTR-Sheet - A102 - FLOOR PLANS -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]
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2019-06-20 20190620 - from STRUCT to SOR - loads on precast
    [20190619 - CTR-Sheet - FLOOR PLAN - LOADING_ON_PRECAST_PLANKS.dwg, 20190619_1000 - CTR-Sheet - FLOOR PLAN - LOADING_ON_PRECAST_PLANKS.dwg]
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2019-06-28 fixing wall joinery @ stair & elevator shaft location
2019-07-01 Update loads on precast
    [20190629 - CTR-Sheet - FLOOR PLAN - LOADING_ON_PRECAST_PLANKS.dwg]
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2019-07-09 Upload XC FEM models
    [1st_floor_loads.dwg, b1_reaction.ods, basement.dwg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]
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2019-07-26 20190725 - to Design team - cad backgrounds
    [20190725 - CTR-Reflected Ceiling Plan - Basement.dwg, 20190725 - CTR-Reflected Ceiling Plan - ENLARGED RCP - 1ST FLOOR PLAN.dwg, 20190725 - CTR-Reflected Ceili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]
2019-07-26 Corridor floor fire design report
    [working_plan_2floor.dwg]
2019-08-09 20190809 - to Design Team - cad backgrounds
    [20190809 - CTR-Reflected Ceiling Plan - ENLARGED RCP - 1ST FLOOR PLAN.dwg, 20190809 - CTR-Reflected Ceiling Plan - ENLARGED RCP - 2ND FLOOR PLAN.dwg, 20190809 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]
2019-08-13 20190813 - cleaned up backgrounds
    [20190809 - CTR-Sheet - A100 - FLOOR PLAN - BASEMENT.dwg, 20190809 - CTR-Sheet - A101 - FLOOR PLANS - 1ST FLOOR.dwg, 20190809 - CTR-Sheet - A102 - FLOOR PLANS -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]
2019-08-15 a seed for the list of sheets
    [Sheets.csv]
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2019-08-15 Sheets Origins Added & .CSV saved
    [Sheets.csv]
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2019-08-19 Markups and changes made
    [CTR - Door Hardware Index - Sheet1.csv]
2019-08-20 fire extinguisher fixes
    [CTR - Door Hardware Index - Sheet1 markup done.csv]
2019-08-29 Fixed stairs railings not displaying - Fixes #62
2019-09-04 snapshot before folder restructuring
    [Sheets.ods]
2019-09-05 models now open source!
    [Sheets.csv, Sheets.ods, Starter Elevation.dwg]
2019-09-05 7/04 loads on precast
    [20190704 - CTR-Sheet - FLOOR PLAN - LOADING_ON_PRECAST_PLANKS.dwg]
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2019-09-27 Minor problems for clonning on DIOC server
    [column_reactions.csv, footing_schedule.csv, footings_dimensions.csv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]
2019-09-27 Repair broken symlink
    [wall_reactions.ods]
2019-09-27 20190927 - to precast engineer - proposed grid layout
    [20190927 - CTR - 1st Phase - Structure - Floor Plan - FOUNDATION PLAN 01.dwg]
2019-09-30 20190930 - to ELECT - CAD unit elevations
    [CTR - 1st Phase - Unit Layouts-Sheet - A470 - 1ST FLOOR STUDIO UNITS.dwg, CTR - 1st Phase - Unit Layouts-Sheet - A471 - 1ST FLOOR 1BD UNITS.dwg, CTR - 1st Phas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]
2019-10-01 20190930 - from precast engineer - layout
    [47-091-18_Preliminary Layout .dwg]
2019-10-08 20191007_2300 - from ARCH - structural coordination
    [footing_schedule_grp.ods, footing_schedule_grp.xlsx]
2019-10-09 20191009 - to GC - IFC - FOUNDATION
    [elevator_shaft.dwg, elevator_shaft_feet.dwg, south_basement_wall_foundation.dwg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]
2019-10-10 20191009 - to STRUCT - 1st floor framing background
    [CTR - 1st Phase - Structure - Sheet - S210 - FRAMING - 1ST FLOOR.dwg]
2019-10-15 20191014 - to precaster - additional drawings
    [20191010_loading_plan_1ST_FLOOR.dwg, 20191014_loading_plan_1ST_FLOOR.dwg, S210 - FRAMING - 1ST FLOOR.dwg]
2019-10-16 20191015 - to GC - top of foundation wall details
    [Revisions.csv]
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2019-10-17 test 2 push via tortoise git
    [test file - Copy.xlsx]
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2019-11-07 20191107 - to GC -Updated Foundation
    [108526.dwg, 47-091-18_Preliminary Layout .dwg, CTR - 1ST FLOOR HVAC - 10.21.19.dwg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]
2019-11-08 Plumbing and Mech backgrounds #89
    https://github.com/OpeningDesign/CTR/issues/89
    In the common and units file...
    - update the PLUMBING views with latest background here: CTR\_closed_cannery district - eau claire\Transfer\20191029 - from PLUMB eng - latest backgrounds
    - create MECH views, just like the PLUMBING views with the cad background here: CTR\_closed_cannery district - eau claire\Transfer\20191031 - from MECH eng
    - latest backgrounds
    create a new 'MECH' view template that has all the ARCH layers turned off in the cad file.
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2019-11-20 CTR\_closed_cannery district - eau claire\Building Products\03 - Concrete\03 40 00 Precast Concrete\20191118\20191120 - from ARCH to STRUCT - for review and comment.pdf
    [47-091-19 Cannery Trails for Ryan Schultz at OD 11-19-19.dwg]
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2019-12-04 Spreadsheet data and sketches for anchor position (issue #95)
    [holddown_anchors_position.ods]
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2019-12-31 corrected incorrect .gitignore
    [00base_6150001.dwg, 108526.dwg, 47-091-18_Preliminary Layout .dwg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]
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2020-01-27 20200127 - to GC - UPDATES TO PANELIZER
    [A100 - FLOOR PLANS - BASEMENT.dwg, A101 - FLOOR PLANS - 1ST FLOOR.dwg, A102 - FLOOR PLANS - 2ND FLOOR.dwg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]
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2020-01-27 20200127 - to owner - diagram floor plans
    [UNIT COUNT.xls]
2020-02-01 added missing sheet to current set
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2020-02-21 061753 - Shop-Fabricated Wood Trusses\20200221 - to GC - reviewed Truss Shops
    [141271_.DWG, 2nd-Floor.dwg]
2020-02-26 20200226 - to GC - review wall shops
    [F13 L1 CTR 2.25.20.dwg]
2020-02-27 20200227 - to GC - Floor Plan Dimensions
    [1ST FLOOR.dwg, 2ND FLOOR.dwg, 3RD FLOOR.dwg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]
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2020-03-13 20200313 - to framer - DWGs for 1st and 2nd floors
    [20200313 - CTR - 1ST FLOOR.dwg, 20200313 - CTR - 2ND FLOOR.dwg, 2nd-Floor Area-A.dwg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]
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2020-04-21 20200421 - to state - REVISION NO. 3
    [JH siding jamb detail.dwg]
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2020-04-27 20200425 - to owner - videos and renderings
    [34CORRUGATEDP3.dwg, 78CORRUGATEDP3.dwg, HALFCORRUGATEDP3.dwg]
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2020-07-15 Out for Issue Permit Revision #6 - 20200715
    [SHEET INDEX.csv]
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2020-12-04 20201203 - to GC - Courtyard Privacy Walls
    [F70-F70L_wd01-rothoblaas.dwg, F70-F70L_wd01-rothoblaas.dxf, ~~F70-F70L_wd01-rothoblaas.dxf]
